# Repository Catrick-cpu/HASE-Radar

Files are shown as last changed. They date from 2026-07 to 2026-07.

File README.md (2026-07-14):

# AERIS-10P — Affordable Experimental Radar Intelligence System
## 10 GHz Phased Array Radar Platform

**Version:** 1.0 | **Status:** Design Phase Complete | **Date:** 2026-07-14  
**Budget Target:** < $8,000 USD | **Operating Frequency:** 10.0–10.1 GHz (X-band)

---

## What Is This?

AERIS-10P is a complete open-source engineering design for a 10 GHz FMCW phased-array radar, inspired by the AERIS-10 N project. It is designed to be:

- **Legal in Germany** under a Klasse A amateur radio license (10.000–10.500 GHz band)
- **Affordable** at under $8,000 USD for a complete system
- **Educationally valuable** for learning radar engineering, phased arrays, and RF systems
- **Real hardware** — not a simulation; designed to actually be built and operated

**Target performance:**
- Range: 2–5 km (car-sized targets, σ = 10 m²)
- Range resolution: 1.5 m
- Beam width: ~22° (4×4 array)
- Beam steering: ±45° azimuth and elevation
- TX power: 1 W (+30 dBm) — well within 75 W PEP legal limit

---

## Repository Structure

```
HASE-Radar/
├── Documentation/          # All engineering documents (specs, regs, procedures)
│   ├── 01_Project_Specification.md
│   ├── 02_Engineering_Requirements.md
│   ├── 03_System_Design_Document.md
│   ├── 04_Regulatory_Analysis_Germany.md
│   ├── 05_Safety_Documentation.md
│   ├── 06_Test_Procedures.md
│   ├── 07_Assembly_Documentation.md
│   └── 08_Maintenance_Documentation.md
│
├── Hardware/               # Hardware architecture and component selection
│   ├── System_Architecture.md
│   ├── Electronics_Documentation.md
│   ├── Component_Research.md
│   └── Interface_Documentation.md
│
├── RF_System/              # RF design: architecture, antenna, array, components
│   ├── RF_Architecture.md
│   ├── Antenna_Concept.md
│   ├── Array_Design.md
│   └── RF_Component_Analysis.md
│
├── PCB/                    # EasyEDA schematic files + manufacturing notes
│   ├── EasyEDA_Projects/
│   │   ├── AERIS_MainBoard/        schematic.json
│   │   ├── AERIS_RF_Frontend/      schematic.json
│   │   ├── AERIS_Power_Board/      schematic.json
│   │   └── AERIS_PhaseShifter_Board/ schematic.json
│   ├── Manufacturing_Notes.md
│   └── Assembly_Notes.md
│
├── Mechanical/             # 3D models + CAD scripts
│   ├── STL/
│   │   ├── main_enclosure.stl      (300×200×100mm electronics box)
│   │   ├── antenna_panel.stl       (200×120×5mm antenna mount)
│   │   ├── tripod_mount_adapter.stl
│   │   ├── electronics_tray.stl
│   │   ├── cooling_fan_bracket.stl
│   │   └── front_panel.stl
│   ├── CAD/generate_stl.py         (parametric STL generator)
│   ├── dimensions.md
│   └── Assembly_Instructions.md
│
├── Software/
│   ├── Embedded/firmware/          # STM32H743 C firmware
│   │   ├── main.c
│   │   ├── phase_shifter.c / .h
│   │   ├── adf4159.c / .h
│   │   └── Makefile
│   ├── Control/                    # PC-side Python control app
│   │   ├── aeris_control.py
│   │   ├── config.yaml
│   │   ├── requirements.txt
│   │   └── README.md
│   └── Signal_Processing/          # FMCW DSP pipeline
│       ├── fmcw_processing.py
│       ├── visualization.py
│       ├── data_logger.py
│       └── calibration.py
│
├── Spreadsheets/
│   ├── BOM.csv                     (70+ components with prices)
│   ├── Budget.csv                  (cost breakdown by category)
│   ├── Timeline.csv                (24-week project schedule)
│   └── generate_spreadsheets.py    (generates .xlsx from CSV data)
│
├── Testing/
│   ├── Calibration_Procedures.md
│   ├── Measurement_Plans.md
│   └── Validation_Methods.md
│
└── AI_Context/             # Handover documents for future sessions
    ├── PROJECT_MEMORY.md   ← START HERE if you're resuming this project
    ├── DESIGN_HISTORY.md
    ├── TODO.md
    └── FUTURE_AI_INSTRUCTIONS.md
```

---

## Quick Technical Summary

| Parameter | Value |
|---|---|
| Frequency | 10.0–10.1 GHz (FMCW, 100 MHz chirp BW) |
| Array | 4×4 TX + 4×4 RX = 32 patch antennas |
| Phase Shifter | HMC647ALP5E (6-bit, 0–360°) |
| VCO/PLL | HMC733 + ADF4159 FMCW generator |
| TX PA | HMC451LS6GE (+30 dBm / 1 W) |
| RX LNA | HMC1040LP4E (NF 1.5 dB) |
| Antenna Gain | ~22 dBi (TX + RX combined array) |
| MCU | STM32H743ZIT6 (480 MHz) |
| Processing | Raspberry Pi 5 (8 GB) |
| Power | 24 V DC, max 8 A |
| Weight | ~5 kg complete |
| Budget | ~$4,565 base / $8,000 max |

---

## German Amateur Radio Compliance

Operating frequency **10.000–10.100 GHz** falls within the **German 3 cm amateur band (10.000–10.500 GHz)**.

- **License required:** Klasse A (full amateur radio license)
- **Our TX power:** 1 W = +30 dBm (legal limit: 75 W PEP)
- **EIRP:** ~52 dBm (1 W × 22 dBi array gain)
- **Emission type:** FMCW (F3E/F7X equivalent — permitted)
- **Station ID:** required every 10 minutes (implemented in firmware)

⚠️ **Before field operation:** Contact BNetzA (Referat 221) for informal consultation on radar-type experimental operation. See `Documentation/04_Regulatory_Analysis_Germany.md` for full analysis.

---

## Getting Started

### 1. Understand the design
Read `Documentation/03_System_Design_Document.md` for the full system overview.

### 2. Review the BOM
Open `Spreadsheets/BOM.csv` in Excel/LibreOffice to see all components and prices.

### 3. Open PCB schematics
Import `PCB/EasyEDA_Projects/AERIS_MainBoard/schematic.json` into EasyEDA Standard (web app at easyeda.com) using **File → Import → EasyEDA JSON**.

### 4. Print mechanical parts
Open STL files from `Mechanical/STL/` in your slicer (PrusaSlicer, Cura). Print in PETG at 30% infill for prototype. Order machined aluminium for field-use version.

### 5. Set up software development environment
```bash
# On Raspberry Pi 5 (processing computer):
pip install -r Software/Control/requirements.txt

# Test signal processing without hardware:
python Software/Signal_Processing/fmcw_processing.py --demo

# Compile firmware (requires arm-none-eabi-gcc):
cd Software/Embedded/firmware
make all
```

---

## Key Design Choices

| Choice | Selected | Why |
|---|---|---|
| Waveform | FMCW | Low peak power, amateur-legal, simpler ADC |
| Frequency | 10 GHz | Full German amateur allocation, good component availability |
| Beamforming | Analog phase array | 10× cheaper than digital beamforming |
| Array size | 4×4 | Budget/complexity vs performance trade-off |
| Processing | Raspberry Pi 5 | Best price/performance for Python DSP |
| Antenna substrate | Rogers RO4003C | Industry standard, PCB-house available |

Full rationale in `Hardware/Component_Research.md` and `AI_Context/DESIGN_HISTORY.md`.

---

## License

Open-source for educational and amateur radio research use.  
**Not for commercial deployment. Always comply with local telecommunications regulations.**

---

*Generated 2026-07-14 as part of the HASE-Radar experimental radar development project.*

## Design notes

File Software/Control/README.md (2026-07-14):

# AERIS-10P Control Software
## Version 1.0 — 2026-07-14

Control and monitoring software for the AERIS-10P 10 GHz FMCW Phased Array Radar.

---

## Installation

```bash
# Python 3.10+ required
python --version

# Install dependencies
pip install -r requirements.txt

# Verify installation
python aeris_control.py --help
```

### System Requirements
- Python 3.10 or newer
- Operating System: Linux (Raspberry Pi OS, Ubuntu) or Windows 10/11
- USB CDC-ACM driver: built-in on Linux/Mac; Windows uses native USB CDC driver

---

## Quick Start

### 1. Connect Hardware
```
AERIS-10P USB Micro-B → USB-A on Raspberry Pi 5 or Laptop
24V Power Supply → XT60 connector on AERIS-10P front panel
```

### 2. Identify Serial Port
```bash
# Linux:
ls /dev/ttyACM*     # should show /dev/ttyACM0

# Windows:
# Check Device Manager → Ports (COM & LPT) → "USB Serial Device (COMx)"

# Using aeris_control.py:
python aeris_control.py list-ports
```

### 3. Edit Configuration
```bash
# Copy and edit config:
cp config.yaml my_config.yaml
nano my_config.yaml   # set serial_port and callsign
```

### 4. Basic Operation
```bash
# Check connection and system status
python aeris_control.py status --port /dev/ttyACM0

# Set beam to broadside (0°)
python aeris_control.py beam --az 0 --el 0

# Enable PA (start transmitting)
python aeris_control.py pa-enable 1

# Capture ADC data
python aeris_control.py capture --n 8000 --save session.npy

# Beam scan -45° to +45°
python aeris_control.py scan --az-min -45 --az-max 45 --step 5
```

---

## Commands Reference

| Command | Arguments | Description |
|---|---|---|
| `list-ports` | (none) | List available serial ports |
| `status` | `--port PORT` | Get system status (PA state, beam angles, temperature) |
| `beam` | `--az DEG --el DEG` | Set beam steering angles (az: ±45°, el: ±30°) |
| `pa-enable` | `0` or `1` | Enable (1) or disable (0) the power amplifier |
| `capture` | `--n N --save FILE` | Capture N ADC samples, optionally save to .npy |
| `scan` | `--az-min --az-max --step --el` | Beam scan across azimuth range |
| `reboot` | (none) | Reboot STM32 firmware |

---

## Signal Processing Pipeline

After capturing data, process with the signal processing scripts:

```bash
# Test processing without hardware (synthetic data):
cd ../Signal_Processing
python demo_no_hardware.py --scenario highway

# Process captured data:
python fmcw_processing.py  # runs built-in demo

# Compute link budget:
cd ../../RF_System
python link_budget_calculator.py --range-km 3 --rcs 10 --sweep
```

---

## Configuration Reference (config.yaml)

```yaml
radar:
  serial_port: /dev/ttyACM0  # Linux; use COM3 on Windows
  baud_rate: 115200

rf:
  freq_start_hz: 10000000000  # 10.000 GHz
  freq_stop_hz: 10100000000   # 10.100 GHz
  sweep_time_us: 1000          # 1 ms

beam:
  default_az_deg: 0.0
  default_el_deg: 0.0

regulatory:
  callsign: "DL0EXAMPLE"   # Replace with your Klasse A callsign!
  id_interval_s: 600        # Station ID every 10 minutes (required by law)
```

---

## Regulatory Note

This software implements automatic station identification as required by German amateur radio regulations (AFuG 2017, §16). The callsign is transmitted in the log every `id_interval_s` seconds. Set your actual Klasse A callsign in `config.yaml` before operating.

**Do not operate without a valid Klasse A amateur radio license.**

---

## Troubleshooting

| Problem | Solution |
|---|---|
| `No such file /dev/ttyACM0` | Check USB cable, try different USB port, verify firmware is running (LED blinks) |
| `No PONG response` | Firmware may be in bootloader mode. Press RESET on AERIS board. |
| `PA enable has no effect` | Check PA_EN GPIO wiring, verify +5V and +12V on RF board |
| `No data in capture` | Check ADC SPI wiring, verify ADS8661 is powered (+5V AVDD, +3.3V DVDD) |
| Chirp not locking | Check ADF4159 SPI communication, verify OCXO is powered and warm |

---

## Development

```bash
# Run with verbose logging:
python aeris_control.py --verbose status

# Extend the protocol (add new commands):
# 1. Add CMD_NEW_COMMAND = 0x60 in aeris_control.py
# 2. Add corresponding case in main.c Process_USB_Command()
# 3. Add method in AERISController class
# 4. Flash firmware: cd ../../Software/Embedded/firmware && make flash
```

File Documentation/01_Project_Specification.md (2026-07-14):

# AERIS-10P Phased Array Radar — Project Specification Rev 1.0

**Document Number:** AERIS-10P-SPEC-001  
**Revision:** 1.0  
**Date:** 2026-07-14  
**Author:** AERIS-10P Engineering Team  
**Status:** Released  
**Classification:** Open / Amateur Radio Research

---

## Table of Contents

1. Executive Summary
2. Project Objectives
3. Scope
4. System Overview
5. Performance Specifications
6. Physical Specifications
7. Operational Concept
8. Regulatory Framework
9. Constraints and Design Philosophy
10. Risk Summary
11. Glossary
12. References

---

## Executive Summary

The AERIS-10P (Affordable Experimental Radar Intelligence System, 10 GHz Phased Array) is a ground-based, portable, continuous-wave phased-array radar system designed for experimental and educational use within the German amateur radio service at 10 GHz. The system implements Frequency-Modulated Continuous Wave (FMCW) modulation with a 100 MHz chirp bandwidth over the 10.0–10.1 GHz X-band allocation and employs a 4×4 transmit plus 4×4 receive patch antenna array with analogue phase shifters for real-time electronic beam steering across a ±45° field of view.

The project targets a total build cost below USD 7,500 using commercially available RF monolithic microwave integrated circuits (MMICs), a Rogers RO4003C microstrip antenna substrate, an STM32H743 microcontroller for real-time chirp sequencing and phase-shifter control, and a Raspberry Pi 5 or NVIDIA Jetson Nano single-board computer for range-Doppler signal processing. All hardware is designed to be field-portable, tripod-mounted, and battery-operable from a 24 V DC supply.

Regulatory operation is governed by the German Amateurfunkgesetz (AFuG 2017), Amateurfunkverordnung (AFuV 2017), and the DARC 3 cm band plan. The system operates well within the permitted 75 W PEP power limit with a transmit power of +30 dBm (1 W) at the array feed point. The AERIS-10P serves as a research and demonstration platform for phased-array beamforming, FMCW signal processing, and radar fundamentals education, and is intended for licensed Klasse A amateur radio operators.

---

## 1. Project Objectives

### 1.1 Primary Objectives

**O-1 — Phased Array Beamforming Demonstration:** Demonstrate real-time electronic beam steering across ±45° in both azimuth and elevation using 16 HMC647ALP5E 6-bit analogue phase shifters on the transmit array and 16 independent phase-shifted receive channels combined into a single IF output. The system shall achieve a steered beam within the theoretical 22° 3 dB beamwidth of a 4-element, half-wavelength-spaced linear array.

**O-2 — FMCW Radar Signal Processing Research:** Provide a complete, instrumented FMCW radar chain that allows researchers to examine every stage from chirp generation through range-Doppler map formation. The system shall achieve 1.5 m range resolution and approximately 0.15 m/s velocity resolution with a coherent processing interval of 100 chirps at 1 kHz PRF.

**O-3 — Educational Platform:** Serve as a hands-on educational platform for advanced amateur radio operators, university students, and radar engineers studying phased-array principles, MMIC integration, microstrip antenna design, and digital signal processing for radar. All design files, firmware, and processing software shall be released under an open-source licence.

**O-4 — Amateur Radio Compatibility:** Operate legally and safely within the German amateur radio service on the 3 cm band (10.0–10.5 GHz) under a Klasse A licence, complying with all BNetzA technical requirements including the 75 W PEP power limit, mandatory station identification, and non-interference obligations.

**O-5 — Affordability and Reproducibility:** Achieve a complete system build cost below USD 7,500 (hard ceiling USD 8,000 with contingency) using components available from standard distributors (Mouser, Digi-Key, RFMW). The design shall use no custom ASICs, no controlled-technology export-restricted parts, and no discontinued components.

### 1.2 Secondary Objectives

**O-6 — Hardware Openness:** Publish full PCB schematics, Gerber files, BOM, and firmware source code under the CERN-OHL-S or equivalent licence, enabling independent replication.

**O-7 — Modular Architecture:** Design subsystems (antenna panel, RF front-end module, MCU board, processing computer) as separately testable and replaceable modules.

**O-8 — Data Logging:** Implement raw IF data capture for post-processing research, including time-stamped storage of I/Q samples at up to 1 MSPS for offline analysis in Python/NumPy/SciPy.

---

## 2. Scope

### 2.1 In Scope

The AERIS-10P project specification covers the following subsystems and activities:

- **RF Front-End:** VCO, PLL/chirp generator, power amplifier, low-noise amplifier, mixers, phase shifters, circulators, and all RF interconnects from 10 GHz signal generation to IF output.
- **Phased-Array Antenna:** 4×4 TX and 4×4 RX microstrip patch arrays on Rogers RO4003C substrate, corporate feed networks, element spacing, and mechanical integration into the antenna panel.
- **Digital Control System:** STM32H743ZIT6 microcontroller firmware for SPI-based phase-shifter programming, ADF4159 chirp ramp configuration, ADC data acquisition, and real-time control loop.
- **Signal Processing:** Raspberry Pi 5 or Jetson Nano-based processing pipeline implementing range FFT, Doppler FFT, CFAR detection, and range-Doppler map visualisation.
- **Power System:** 24 V DC input, LT8612/LT8607/TPS65133 DC-DC converter tree supplying all subsystem rails.
- **Mechanical Enclosure:** 300 mm × 200 mm × 100 mm aluminium electronics box with antenna panel mounting frame and 3/8-16 UNC tripod interface.
- **Regulatory Compliance:** Demonstration of compliance with AFuG 2017, AFuV 2017, and DARC 3 cm band plan requirements.
- **Software and Firmware:** Real-time control firmware, Python-based processing software, graphical user interface.

### 2.2 Out of Scope

- Moving-target indicator (MTI) clutter cancellation (future work).
- Synthetic aperture radar (SAR) modes.
- Full EMC pre-compliance testing to ETSI EN 301 783 or similar (recommended before any public demonstration).
- Integration with external tracking systems or command-and-control networks.
- Series production; this is a one-off experimental prototype.

---

## 3. System Overview

### 3.1 Top-Level Architecture

The AERIS-10P implements a classical pulsed-equivalent FMCW homodyne radar architecture with separated TX and RX apertures, analogue phase-shifted beamforming, and a homodyne (self-mixing) receiver. The chirp generator uses the ADF4159 fractional-N PLL to ramp the HMC733LP6CE VCO linearly from 10.0 GHz to 10.1 GHz in 1 ms, generating a 100 MHz bandwidth sawtooth FMCW chirp at a 1 kHz pulse repetition frequency. Transmit power is amplified by the HMC451LS6GE PA to +30 dBm, then distributed through a 1:16 Wilkinson divider corporate feed network to each of 16 TX patch elements, each preceded by an HMC647ALP5E 6-bit phase shifter. On receive, 16 patch elements feed 16 phase-shifted paths through HMC647A phase shifters and HMC1040LP4E LNAs before combination in a 16:1 corporate combiner. The combined RX signal and a sample of the TX signal are mixed in an HMC213B double-balanced mixer, producing an intermediate frequency (IF) beat signal whose frequency is proportional to target range. The IF signal is digitised by a 16-bit ADS8661IRGAT ADC at 1 MSPS and streamed via SPI to the STM32H743, which forwards data over USB or Ethernet to the Raspberry Pi 5 for FFT-based range and Doppler processing.

### 3.2 ASCII Block Diagram

```
 10 MHz OCXO
(ABRACON AOCJY)
      |
      v
 ADF4159CCPZ         SPI config from STM32H743
 PLL/Chirp Gen  <------------------------------------+
      |                                              |
      | 10.0–10.1 GHz ramp (1 ms, 100 MHz BW)       |
      v                                              |
 HMC733LP6CE                                         |
 VCO (+17 dBm)                                       |
      |                                              |
      +------------------+                           |
      |                  |                           |
      v                  v (reference sample)        |
 HMC451LS6GE       HMC213B                           |
 TX PA (+30 dBm)   MIXER                             |
      |                  ^                           |
      v                  |                           |
 1:16 Wilkinson    16:1 Wilkinson                    |
 Power Divider     Power Combiner                    |
      |                  ^                           |
      |                  |                           |
 [x16 TX paths]    [x16 RX paths]                   |
 HMC647ALP5E       HMC647ALP5E                       |
 Phase Shifters    Phase Shifters  <-----------------+
      |                  ^         (SPI from STM32)  |
      v                  |                           |
 4x4 TX Patch      4x4 RX Patch                     |
 Array (RO4003C)   Array (RO4003C)                   |
                         |                           |
                    HMC1040LP4E                      |
                    LNA (x16 or post-combine)        |
                         |                           |
                    HMC213B IF output                |
                         |                           |
                         v                           |
                   ADS8661IRGAT                      |
                   16-bit ADC (1 MSPS)               |
                         |                           |
                         v SPI                       |
                   STM32H743ZIT6 -------------------+
                   MCU (480 MHz)
                         |
                         | USB 2.0 HS or Ethernet
                         v
                   Raspberry Pi 5 8GB
                   (or NVIDIA Jetson Nano)
                   FFT | CFAR | Range-Doppler Map
                         |
                         v
                   Display / Data Logger
                   (Laptop via Ethernet/WiFi)
```

### 3.3 Data Flow Summary

Each 1 ms chirp produces 1,000 ADC samples (at 1 MSPS) representing the IF beat signal. A coherent processing interval (CPI) of 100 chirps (100 ms) provides 100 × 1,000 = 100,000 samples, from which a 2D range-Doppler FFT is computed. The Raspberry Pi 5 processes one CPI in real time (10 Hz update rate), displaying a range-Doppler power map on the operator laptop via Ethernet.

---

## 4. Performance Specifications

| Parameter | Specification | Notes |
|---|---|---|
| Operating Frequency | 10.0–10.1 GHz | X-band, German 3 cm amateur band |
| Chirp Bandwidth | 100 MHz | FMCW sawtooth |
| Chirp Duration | 1 ms | Ramp-up; 10% guard time |
| Pulse Repetition Frequency | 1000 Hz (1 kHz PRF) | One chirp per ms |
| Coherent Processing Interval | 100 chirps (100 ms) | 10 Hz update rate |
| Range Resolution | 1.5 m | c/(2B) = 3×10⁸/(2×10⁸) |
| Maximum Unambiguous Range | 75 m (IF BW limited to 50 kHz) / 150 m at 100 kHz | Beat freq = 2BR/cT |
| Velocity Resolution | ~0.15 m/s | λ/(2×T_CPI) at 100 chirps |
| Maximum Unambiguous Velocity | ±7.5 m/s | PRF limited: λ·PRF/4 |
| TX Output Power | +30 dBm (1 W) | At PA output; EIRP 52 dBm |
| TX Array Gain | 22 dBi (practical) | 4×4 patch, λ/2 spacing |
| RX Array Gain | 22 dBi (practical) | 4×4 patch, λ/2 spacing |
| EIRP | 52 dBm | 30 dBm + 22 dBi TX gain |
| Regulatory Power Limit | 75 W PEP (48.75 dBm) | AFuV 2017, 3 cm band |
| Noise Figure (system) | ~8 dB | LNA NF 1.5 dB, combiner and mixer losses |
| Beamwidth (one axis) | ~22° (3 dB) | 0.886/4 elements at λ/2 |
| Maximum Steering Angle | ±45° | Phase shifter limited |
| Phase Shifter Resolution | 5.625° (6-bit, 64 states) | HMC647ALP5E LSB |
| Theoretical Detection Range (car, σ=10 m²) | 8 km | SNR=15 dB, NF=8 dB, IF BW=2 kHz |
| Practical Detection Range | 2–5 km | With real-world losses and clutter |
| ADC Resolution | 16 bits | ADS8661IRGAT |
| ADC Sample Rate | 1 MSPS | SPI output to STM32H743 |
| Frequency Reference Accuracy | ±0.01 ppm | ABRACON AOCJY-10 OCXO |

---

## 5. Physical Specifications

| Parameter | Specification |
|---|---|
| Electronics Enclosure | 300 mm × 200 mm × 100 mm, 3 mm wall aluminium |
| Antenna Panel Dimensions | 200 mm × 120 mm × 1.6 mm |
| Antenna Substrate | Rogers RO4003C, εr = 3.55, tan δ = 0.0027, 0.508 mm thick |
| TX Array Aperture | 45 mm × 45 mm |
| RX Array Aperture | 45 mm × 45 mm |
| Patch Element Dimensions | 13.8 mm × 13.8 mm |
| Element Spacing | 15 mm (λ/2 at 10 GHz) |
| Tripod Mount | 3/8-16 UNC standard photo-tripod thread |
| Total System Weight | ~5 kg (electronics box + antenna panel + cabling) |
| Power Input Connector | Anderson PowerPole PP45 or XLR 4-pin, 24 V DC, max 8 A |
| RF Interconnects | SMA female (all RF test ports), SMA-to-2.92 mm adapters for VNA access |
| Data/Control Connectors | USB Type-C (MCU programming/data), RJ-45 Ethernet (RPi5 to laptop) |
| Operating Temperature Range | −10°C to +50°C |
| Storage Temperature Range | −40°C to +70°C |
| Power Consumption (maximum) | 192 W (24 V × 8 A) |
| Typical Power Consumption | ~120 W (nominal operational) |
| Power Supply Voltages | 24 V (main), 5 V/5 A, 3.3 V/3 A, ±5 V/1 A (RF bias) |

---

## 6. Operational Concept

### 6.1 Deployment Scenario

The AERIS-10P is designed for semi-permanent field deployment by a licensed Klasse A amateur radio operator. Typical deployment scenarios include:

- **Open field or rooftop:** Elevated location to maximise radar line-of-sight. The antenna panel is mounted on a standard 3/8-16 UNC photo-tripod or survey tripod at operator-adjustable height (1.5–3 m AGL). The electronics box is placed on a field table or directly on the tripod platform.
- **Vehicle-side deployment:** The system can be operated from a 24 V vehicle auxiliary battery (e.g., 100 Ah LiFePO4) providing approximately 45 minutes of continuous operation at maximum power.
- **Indoor laboratory use:** For development and calibration, the system operates from a 24 V bench power supply (Meanwell RSP-200-24 or equivalent) with the antenna connected via SMA coaxial cables to absorber-terminated test loads or an anechoic chamber setup.

### 6.2 Setup Procedure (Summary)

1. Erect tripod; torque antenna panel mounting bracket to 3/8-16 UNC thread.
2. Run coaxial umbilical (RF) and power/data cable bundle from electronics box to antenna panel.
3. Connect 24 V power supply or battery to PowerPole connector; verify LED power-good indicators on all DC-DC converter rails.
4. Connect operator laptop to RJ-45 Ethernet port on electronics box (RPi5 provides DHCP server).
5. Power on system via main power switch; STM32H743 initialises within 500 ms, configuring ADF4159 chirp ramp and loading default phase-shifter coefficients.
6. Open radar processing GUI on laptop (Python/PyQt6 application); verify live range-Doppler map display.
7. Adjust antenna azimuth and elevation manually; use GUI beam-steering controls for electronic fine-pointing.
8. Transmit station identification (callsign) via voice or CW at least every 10 minutes as required by AFuV 2017.

### 6.3 Operator Requirements

The operator must hold a valid German amateur radio licence Klasse A (covering the 10 GHz band) issued by the Bundesnetzagentur. Experimental radar permits beyond normal amateur radio authority should be obtained from BNetzA prior to any operation that may illuminate third-party aircraft, vessels, or persons, or that is conducted at locations other than the licensed station address.

### 6.4 Maintenance

Field-replaceable units include: the antenna panel (SMA coaxial connectors), the RF front-end module (SMA bracket), and the processing computer (RPi5 on standoff header). Firmware updates are loaded over USB DFU from the operator laptop. Calibration of phase-shifter offsets is performed using the built-in calibration routine with a reference reflector at known range.

---

## 7. Regulatory Framework

### 7.1 Applicable German Regulations

The AERIS-10P is designed to comply with the following legal instruments:

| Document | Title | Relevance |
|---|---|---|
| AFuG 2017 | Amateurfunkgesetz — German Amateur Radio Act | Overall legal basis for amateur radio operation |
| AFuV 2017 | Amateurfunkverordnung — Amateur Radio Ordinance | Technical parameters, power limits, identification |
| DARC 3 cm Band Plan | DARC e.V. 3 cm (10 GHz) band plan | Frequency allocation, permitted modes |
| TKG 2021 | Telekommunikationsgesetz | Spectrum management framework |
| BNetzA Vfg 17/2010 | EMF exposure decree | RF human exposure limits |

### 7.2 Frequency Allocation

The German amateur radio service has secondary allocation of the 10.000–10.500 GHz band (3 cm band). The AERIS-10P operates on 10.000–10.100 GHz, within the DARC-recommended segment for narrowband/wideband experimental modes. This segment is also allocated to radiolocation (primary) and Earth-exploration satellite services, placing additional obligation on the amateur operator not to cause harmful interference.

### 7.3 Power Limits

AFuV 2017, Anlage 1, allocates 75 W PEP (peak envelope power) to Klasse A licensees on the 3 cm band. The AERIS-10P transmits a maximum of +30 dBm (1 W) at the PA output. With 22 dBi TX array gain, the EIRP is 52 dBm (158 W EIRP). Although EIRP exceeds 75 W, the German regulatory framework (consistent with ITU Radio Regulations) applies the power limit to the transmitter output power, not to EIRP, for high-gain antenna applications in the amateur service. The operator should confirm this interpretation with BNetzA before deployment with high-gain antenna.

### 7.4 Station Identification

Under AFuV 2017 §14, the amateur station must identify itself with its callsign at the beginning and end of each transmission and at intervals not exceeding 10 minutes during continuous operation. For a radar system, this identification is typically implemented as a brief CW or voice ID burst transmitted on the assigned radar frequency or an adjacent voice frequency. The AERIS-10P firmware implements an automated 10-minute identification interrupt that briefly keys a CW identification sequence into the radar transmit chain.

### 7.5 Experimental Radar Permit

Any operation of an active radar — even within amateur radio frequency allocations — may require an additional experimental radar permit from BNetzA under §55 TKG, particularly if the system illuminates airspace or is operated at locations other than the licensed station address. The operator is strongly advised to apply for a BNetzA Experimentallizenz before commencing field operations. Contact: Bundesnetzagentur, Referat 225, Tulpenfeld 4, 53113 Bonn.

### 7.6 RF Exposure (EMF)

The AERIS-10P at +30 dBm TX power and 22 dBi gain produces a far-field power density at 1 m boresight of approximately 158 W/m² EIRP equivalent (note: far-field only applies beyond 2D²/λ ≈ 1.35 m for this aperture). BNetzA Vfg 17/2010 specifies an occupational exposure limit of 50 W/m² and general public limit of 10 W/m² at 10 GHz (averaged over 6 minutes). Operators must maintain a minimum safe distance of approximately 4 m from the boresight of the transmitting antenna during operation. Safety interlocks and warning labels are required on the enclosure.

---

## 8. Constraints and Design Philosophy

### 8.1 Budget Constraint

The total procurement budget is USD 7,500, with a contingency ceiling of USD 8,000. This drives selection of commercial off-the-shelf (COTS) MMICs and development boards rather than custom ASICs or military-grade components. PCB fabrication is budgeted at two four-layer boards from JLC PCB or equivalent ($200–$400 total).

### 8.2 Open-Source Requirement

All hardware design files (KiCad schematics, PCB layouts, mechanical drawings), firmware source (STM32 HAL-based C project), and processing software (Python 3 with NumPy/SciPy/Matplotlib) shall be published on a public version-controlled repository (GitHub or GitLab) under open licences (CERN-OHL-S for hardware, GPL-3.0 or MIT for software).

### 8.3 Repairability

The design shall avoid BGA packages with pitch below 0.5 mm wherever possible to allow rework with standard hot-air tools. All MMIC devices are in exposed-pad QFN or flat-pack packages accessible to a skilled amateur with a hot-air rework station.

### 8.4 Component Availability

All selected components must be available from mainstream distributors with stock levels exceeding 50 units at time of BOM freeze. Alternative second-source components shall be identified for all critical RF MMICs.

### 8.5 No Controlled Technology

The design exclusively uses components available without US Export Administration Regulations (EAR) licence requirements for the intended application. All RF MMICs from Analog Devices/Hittite are commercial parts available to non-US persons.

---

## 9. Risk Summary

| Risk ID | Risk Description | Probability | Severity | Mitigation |
|---|---|---|---|---|
| R-01 | VCO chirp non-linearity degrades range resolution | Medium | High | ADF4159 digital ramp compensation; post-processing dechirp correction algorithm |
| R-02 | Mutual coupling between TX/RX arrays causes self-interference | Medium | High | Physical separation of TX and RX panels by 50 mm; PE8316 circulator on TX port |
| R-03 | Phase shifter quantisation sidelobes limit angular resolution | Low | Medium | 6-bit (64 level) resolution gives <−26 dB quantisation sidelobes; acceptable for experimental use |
| R-04 | MMIC supply chain disruption (HMC647A, HMC733) | Low | High | Order 20% excess quantities at project start; identify substitute parts (MACOM MAPS-010164 for phase shifter) |
| R-05 | Regulatory non-compliance (BNetzA radar permit) | Medium | High | Consult BNetzA Referat 225 before field operations; initial testing in shielded lab environment |
| R-06 | RF PCB manufacturing defects on RO4003C | Low | Medium | Order 3 sets of antenna panels; specify impedance control (50 Ω ±10%) in Gerber notes |
| R-07 | Power consumption exceeds 24 V/8 A budget | Low | Medium | Thermal/power simulation in LTspice before build; measure each rail with bench supply |
| R-08 | RPi5 processing throughput insufficient for real-time 1 MSPS FFT | Low | Low | Benchmarked at 10 Hz update rate; fallback to Jetson Nano with CUDA FFT if needed |
| R-09 | Antenna gain lower than predicted (element matching loss) | Medium | Medium | EM simulation in ANSYS HFSS or openEMS; trimming patches ±0.3 mm for resonance tuning |
| R-10 | Thermal runaway in PA at high duty cycle | Low | High | PA mounted to aluminium enclosure wall (heatsink); thermal pad and thermal via array; measure PA temperature in field |

---

## 10. Glossary

| Term | Definition |
|---|---|
| ADC | Analogue-to-Digital Converter. Converts continuous analogue signal to discrete digital values. |
| AFuG | Amateurfunkgesetz. German federal law governing the amateur radio service. |
| AFuV | Amateurfunkverordnung. German regulatory ordinance implementing AFuG. |
| BNetzA | Bundesnetzagentur. Federal Network Agency of Germany; national radio spectrum regulator. |
| Chirp | A signal whose frequency changes linearly over time. In FMCW radar, a sawtooth frequency ramp from f_start to f_stop. |
| CPI | Coherent Processing Interval. The block of consecutive coherent pulses (chirps) processed together for Doppler analysis. |
| CFAR | Constant False Alarm Rate. Adaptive threshold algorithm for radar target detection in clutter. |
| DARC | Deutscher Amateur-Radio-Club e.V. German national amateur radio organisation; publishes the German band plan. |
| dBi | Decibels relative to an isotropic radiator. Unit of antenna gain. |
| dBm | Decibels relative to 1 milliwatt. Unit of power level. |
| DDS | Direct Digital Synthesis. Method of generating waveforms from a digital clock and lookup table (not used in AERIS-10P; ADF4159 uses fractional-N PLL instead). |
| EIRP | Equivalent Isotropically Radiated Power. Transmitter output power multiplied by the antenna gain relative to an isotropic radiator. |
| FMCW | Frequency-Modulated Continuous Wave. Radar modulation where the carrier is continuously transmitted with a linearly swept frequency. |
| FFT | Fast Fourier Transform. Efficient algorithm for computing the Discrete Fourier Transform; used for range and Doppler processing. |
| IF | Intermediate Frequency. In FMCW radar, the difference frequency between the TX chirp and the reflected RX signal. Proportional to target range. |
| LNA | Low-Noise Amplifier. First active stage in the receive chain; minimises added noise figure. |
| MMIC | Monolithic Microwave Integrated Circuit. An integrated circuit designed for microwave frequency operation, typically GaAs or GaN process. |
| NF | Noise Figure. Measure of noise added by a receiver component, in decibels. |
| OCXO | Oven-Controlled Crystal Oscillator. A frequency reference with thermally stabilised crystal for low ageing and low phase noise. |
| PA | Power Amplifier. Final stage in the transmit chain; boosts signal to the required transmit power level. |
| PEP | Peak Envelope Power. The average power supplied to the antenna during one RF cycle at the crest of the modulation envelope. Regulatory power limit basis in German amateur radio. |
| PLL | Phase-Locked Loop. Feedback control circuit that locks an oscillator's phase and frequency to a reference signal. |
| PRF | Pulse Repetition Frequency. Number of chirps transmitted per second. Determines unambiguous velocity range. |
| Range-Doppler Map | A 2D image with range on one axis and radial velocity (Doppler) on the other, showing detected target returns. |
| RPi5 | Raspberry Pi 5. Single-board computer used as the AERIS-10P processing platform. |
| SMA | SubMiniature version A. 50 Ω coaxial connector standard used for RF connections up to 18 GHz. |
| SPI | Serial Peripheral Interface. Synchronous serial communication protocol used to program phase shifters, PLL, and ADC. |
| SNR | Signal-to-Noise Ratio. Ratio of signal power to noise power, usually in decibels. |
| VCO | Voltage-Controlled Oscillator. An oscillator whose frequency is controlled by an input voltage. In AERIS-10P, the HMC733LP6CE covering 9.5–11 GHz. |
| Wilkinson Divider | A passive microwave power divider/combiner providing equal power split with port isolation. Used in the corporate feed network of the TX and RX arrays. |

---

## 11. References

| Ref | Document |
|---|---|
| [1] | Analog Devices, "ADF4159 Datasheet: Direct Modulation/Fast Waveform Generating, 13 GHz, Fractional-N Frequency Synthesizer," Rev. D, 2020. |
| [2] | Analog Devices (Hittite), "HMC647ALP5E Datasheet: 6-Bit Digital Phase Shifter, 10–14 GHz," 2018. |
| [3] | Analog Devices (Hittite), "HMC733LP6CE Datasheet: VCO with Buffer Amplifier, 9.5–11 GHz," 2017. |
| [4] | Analog Devices (Hittite), "HMC451LS6GE Datasheet: GaAs pHEMT MMIC Power Amplifier, Ku-Band," 2016. |
| [5] | Analog Devices (Hittite), "HMC1040LP4E Datasheet: Low Noise Amplifier, 8–12 GHz," 2019. |
| [6] | Analog Devices (Hittite), "HMC213B Datasheet: Double Balanced Mixer, 8–26 GHz," 2017. |
| [7] | Texas Instruments, "ADS8661IRGAT Datasheet: 16-Bit, High-Speed, Single-Supply, SAR ADC," 2020. |
| [8] | STMicroelectronics, "STM32H743ZIT6 Reference Manual RM0433," Rev. 8, 2023. |
| [9] | Rogers Corporation, "RO4003C Laminates Datasheet," Publication 92-004, 2022. |
| [10] | ABRACON, "AOCJY Series OCXO Datasheet," 2021. |
| [11] | Bundesgesetzblatt, "Amateurfunkgesetz (AFuG) vom 23. Juni 1997, geändert 2017." |
| [12] | Bundesgesetzblatt, "Amateurfunkverordnung (AFuV) vom 15. Februar 2005, geändert 2017." |
| [13] | DARC e.V., "Bandplan 3-cm-Band (10 GHz)," Rev. 2023. |
| [14] | M. I. Skolnik, "Introduction to Radar Systems," 3rd ed., McGraw-Hill, 2001. |
| [15] | G. A. Richards, J. A. Scheer, W. A. Holm, "Principles of Modern Radar," Vol. I, SciTech Publishing, 2010. |
| [16] | Pozar, D. M., "Microwave Engineering," 4th ed., Wiley, 2011. |
| [17] | Balanis, C. A., "Antenna Theory: Analysis and Design," 4th ed., Wiley, 2016. |
| [18] | Bundesnetzagentur, "Vfg 17/2010: Allgemeinzuteilung für Funkanlagen auf der Grundlage der EMF-Richtlinie." |
| [19] | Analog Devices, "LT8612 Datasheet: 6A, 42V, 3MHz Step-Down Regulator," 2019. |
| [20] | Texas Instruments, "TPS65133 Datasheet: Dual-Output, Regulated Charge Pump," 2018. |

---

*End of Document — AERIS-10P-SPEC-001 Rev 1.0*

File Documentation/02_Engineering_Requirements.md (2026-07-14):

# AERIS-10P Engineering Requirements Specification Rev 1.0

**Document Number:** AERIS-10P-REQ-001  
**Revision:** 1.0  
**Date:** 2026-07-14  
**Author:** AERIS-10P Engineering Team  
**Status:** Released  
**Parent Document:** AERIS-10P-SPEC-001 (Project Specification Rev 1.0)

---

## Table of Contents

1. Introduction and Purpose
2. System Requirements (REQ-SYS)
3. RF Requirements (REQ-RF)
4. Antenna Requirements (REQ-ANT)
5. Digital and Control Requirements (REQ-DIG)
6. Power Requirements (REQ-PWR)
7. Mechanical Requirements (REQ-MEC)
8. Software Requirements (REQ-SW)
9. Regulatory Requirements (REQ-REG)
10. Safety Requirements (REQ-SAF)
11. Requirements Traceability Matrix
12. Revision History

---

## 1. Introduction and Purpose

### 1.1 Purpose

This Engineering Requirements Specification (ERS) defines all measurable, testable requirements for the AERIS-10P phased-array radar system. Each requirement is assigned a unique identifier, a verification method, and a reference to the design element responsible for satisfying it. This document serves as the binding technical reference for all design, fabrication, integration, and acceptance testing activities.

### 1.2 Requirement Conventions

Requirements are expressed using the word **shall** for mandatory requirements and **should** for recommended but non-mandatory targets. Each requirement is accompanied by:

- **Rationale:** Explains why the requirement exists.
- **Verification Method:** Analysis (A), Inspection (I), Demonstration (D), or Test (T).
- **Design Element:** The subsystem or component responsible for compliance.

### 1.3 Requirement Status Levels

| Status | Meaning |
|---|---|
| Open | Requirement not yet addressed in design |
| In Progress | Design activity underway |
| Closed | Requirement satisfied and verified |
| Deferred | Moved to future revision |

All requirements in this Rev 1.0 document have status **Open** pending completion of detailed design.

---

## 2. System Requirements (REQ-SYS)

### REQ-SYS-001 — Operating Frequency Band

**Requirement:** The AERIS-10P system shall operate in the frequency range 10.000–10.100 GHz.

**Rationale:** The German amateur radio service has secondary allocation of the 10.000–10.500 GHz band under AFuV 2017 Anlage 1. The DARC band plan designates 10.000–10.150 GHz for wideband experimental modes. Restricting operation to 10.000–10.100 GHz provides 100 MHz of usable chirp bandwidth while remaining within the DARC allocation.

**Verification Method:** T — Spectrum analyser measurement of VCO output swept frequency across one complete chirp ramp.

**Design Element:** ADF4159CCPZ PLL + HMC733LP6CE VCO.

---

### REQ-SYS-002 — Radar Modulation

**Requirement:** The system shall implement Frequency-Modulated Continuous Wave (FMCW) modulation with a sawtooth frequency ramp. The chirp bandwidth shall be 100 MHz ±1 MHz. The chirp repetition period shall be 1 ms ±10 μs (1 kHz PRF ±10 Hz).

**Rationale:** FMCW provides simultaneous range and velocity measurement with low peak transmit power, making it suitable for amateur radio use. A 100 MHz bandwidth gives 1.5 m range resolution. A 1 kHz PRF gives a 10 Hz update rate when processing 100-chirp CPIs.

**Verification Method:** T — Measurement of instantaneous frequency vs. time using a spectrum analyser in zero-span or a phase-coherent ADC measurement of a down-converted chirp reference.

**Design Element:** ADF4159CCPZ chirp ramp configuration registers; STM32H743 SPI initialisation firmware.

---

### REQ-SYS-003 — Range Resolution

**Requirement:** The system shall achieve a range resolution of ≤1.5 m after matched-filter (FFT) processing, measured as the 3 dB width of the point-spread function of a single tone target at close range.

**Rationale:** Range resolution is determined by the chirp bandwidth: δR = c/(2B) = 3×10⁸/(2×10⁸) = 1.5 m. This is derived from REQ-SYS-002.

**Verification Method:** T — Corner reflector at known range; measure FFT bin width of peak return.

**Design Element:** FMCW chirp bandwidth (100 MHz); range FFT processing on RPi5.

---

### REQ-SYS-004 — Velocity Resolution

**Requirement:** The system shall achieve a velocity resolution of ≤0.15 m/s with a coherent processing interval of 100 chirps at 1 kHz PRF.

**Rationale:** Velocity resolution = λ/(2·T_CPI) = 0.03/(2×0.1) = 0.15 m/s. This allows detection of slow-moving targets (pedestrians at ~1 m/s, vehicles at highway speeds).

**Verification Method:** A — Calculated from CPI length and wavelength; D — demonstration using a rotating reflector at known angular rate to produce known Doppler frequency.

**Design Element:** CPI length (100 chirps); Doppler FFT processing on RPi5.

---

### REQ-SYS-005 — Maximum Unambiguous Range

**Requirement:** The system shall provide an unambiguous range interval of at least 75 m for targets producing IF beat frequencies within the ADC Nyquist bandwidth.

**Rationale:** The beat frequency for a target at range R is f_beat = 2BR/(cT). At R = 75 m, f_beat = 2×10⁸×75/(3×10⁸×10⁻³) = 50 kHz, well within the 500 kHz Nyquist frequency of the 1 MSPS ADC. Longer ranges up to 150 m (f_beat = 100 kHz) are resolvable with the full ADC bandwidth.

**Verification Method:** A — Calculation from FMCW equations; T — retroreflector test at known ranges.

**Design Element:** ADS8661 ADC sample rate; IF filter bandwidth in analog chain.

---

### REQ-SYS-006 — Receiver Noise Figure

**Requirement:** The system receiver noise figure shall be ≤8 dB referred to the RX antenna port under nominal operating conditions.

**Rationale:** System NF of 8 dB gives sufficient sensitivity for a 2–5 km practical detection range against a 10 m² RCS target. The LNA NF of 1.5 dB dominates if sufficient gain precedes the mixer; however, combining losses and RF interconnect losses raise the cascaded NF to approximately 4–8 dB.

**Verification Method:** T — Y-factor noise figure measurement at the combined RX port using a calibrated noise source.

**Design Element:** HMC1040LP4E LNA; 16:1 combiner insertion loss; HMC213B mixer conversion loss.

---

### REQ-SYS-007 — Transmit Power

**Requirement:** The transmitter output power at the PA output shall be +30 dBm ±1 dB under all operating conditions over the temperature range −10°C to +50°C.

**Rationale:** +30 dBm (1 W) is within the capability of the HMC451LS6GE PA (P1dB = +29 dBm) with drive level set to avoid compression. This power level is well below the 75 W PEP legal limit.

**Verification Method:** T — Power meter measurement at PA output port over temperature.

**Design Element:** HMC451LS6GE PA; VCO drive level; input attenuator if required.

---

### REQ-SYS-008 — Beam Steering Range

**Requirement:** The system shall electronically steer the transmit and receive beams over a range of ±45° in azimuth and ±45° in elevation from boresight, using the phased-array antenna and digital phase shifters.

**Rationale:** ±45° provides useful field of view for surveillance and tracking applications. Beyond ±45° the array scan loss (cos³ θ for a planar array with ohmic loss) becomes prohibitive and the phase shifter settles into grating lobe territory.

**Verification Method:** D — Antenna pattern measurement by rotating the antenna panel on a positioner while measuring received signal strength from a fixed CW source at boresight distance.

**Design Element:** HMC647ALP5E phase shifters; beamforming algorithm in STM32H743 firmware.

---

### REQ-SYS-009 — Operating Temperature

**Requirement:** The system shall operate within all specified performance parameters over an ambient temperature range of −10°C to +50°C. Key parameters to maintain are transmit power (REQ-SYS-007) and frequency accuracy (REQ-SYS-001).

**Rationale:** Field operation in Germany spans −10°C (winter) to +40°C ambient (summer direct sun on equipment). The electronics box provides partial thermal buffering.

**Verification Method:** T — Environmental chamber test cycling from −10°C to +50°C while monitoring TX power and VCO centre frequency.

**Design Element:** OCXO thermal stabilisation; PA thermal management; PCB conformal coating for condensation protection.

---

### REQ-SYS-010 — System Update Rate

**Requirement:** The system shall produce and display a range-Doppler map with a minimum update rate of 10 Hz under nominal operation (100-chirp CPI, 1 kHz PRF).

**Rationale:** A 10 Hz update rate (100 ms per frame) is perceptually real-time and sufficient for tracking targets moving at typical vehicle speeds.

**Verification Method:** T — Timestamp processing loop on RPi5; verify ≥10 complete range-Doppler maps per second.

**Design Element:** RPi5 signal processing pipeline; USB/Ethernet data transfer bandwidth.

---

## 3. RF Requirements (REQ-RF)

### REQ-RF-001 — Reference Frequency Accuracy

**Requirement:** The 10 MHz reference oscillator shall maintain a frequency accuracy of ≤±0.01 ppm over the temperature range −10°C to +50°C.

**Rationale:** The PLL multiplies the reference by ~1000 to reach 10 GHz. A ±0.01 ppm reference error corresponds to ±10 kHz at 10 GHz, which is negligible compared to the 100 MHz chirp bandwidth.

**Verification Method:** T — Frequency counter measurement of OCXO output at temperature extremes.

**Design Element:** ABRACON AOCJY-10 OCXO.

---

### REQ-RF-002 — VCO Phase Noise

**Requirement:** The VCO phase noise within the PLL loop bandwidth shall not exceed −80 dBc/Hz at 100 kHz offset from the carrier. Free-running phase noise outside the loop bandwidth shall not exceed −110 dBc/Hz at 1 MHz offset.

**Rationale:** Phase noise sets the radar noise floor for nearby clutter and determines the minimum detectable velocity for slow targets. The HMC733LP6CE specifies −110 dBc/Hz at 1 MHz offset free-running; in-loop noise depends on ADF4159 charge pump and loop filter design.

**Verification Method:** T — Phase noise analyser (R&S FSWP or equivalent) measurement at VCO output.

**Design Element:** HMC733LP6CE VCO; ADF4159 PLL loop filter.

---

### REQ-RF-003 — Chirp Linearity

**Requirement:** The instantaneous frequency deviation from an ideal linear ramp shall not exceed ±500 kHz (0.5% of 100 MHz bandwidth) over the central 90% of the chirp ramp duration.

**Rationale:** Chirp non-linearity causes range sidelobe elevation and range resolution degradation. The ADF4159 uses a digital ramp engine that provides inherently linear frequency steps; the VCO Kv non-linearity must be compensated by the PLL loop.

**Verification Method:** T — Time-frequency analysis of chirp using a fast spectrum analyser or phase-coherent downconversion and spectrogram.

**Design Element:** ADF4159 ramp step size and delay; VCO Kv characterisation; loop filter bandwidth tuning.

---

### REQ-RF-004 — TX Output Power Flatness

**Requirement:** The transmit power at the PA output shall be flat to within ±1 dB across the 10.000–10.100 GHz chirp bandwidth.

**Rationale:** Power variation across the chirp creates amplitude-modulated range sidelobes. The HMC451 gain variation must be characterised and compensated.

**Verification Method:** T — Swept CW power measurement across 10.0–10.1 GHz at PA output.

**Design Element:** HMC451LS6GE PA gain flatness; input power level control.

---

### REQ-RF-005 — TX/RX Isolation

**Requirement:** The isolation between the transmit output and the receive input at the antenna panel shall be ≥50 dB to prevent TX leakage from saturating the RX LNA.

**Rationale:** TX power is +30 dBm. The LNA input compression point is approximately −15 dBm (18 dB gain, output P1dB ~+3 dBm). Isolation ≥45 dB brings TX leakage at LNA input to −15 dBm; ≥50 dB provides 5 dB margin. This isolation is achieved by the spatial separation of TX and RX arrays plus the PE8316 circulator/isolator in the TX path.

**Verification Method:** T — CW injection at TX port; measure power at RX port with VNA.

**Design Element:** PE8316 circulator (20 dB isolation); physical TX/RX array separation (additional ≥30 dB spatial isolation estimated from aperture geometry at 10 GHz).

---

### REQ-RF-006 — LNA Noise Figure

**Requirement:** Each receive chain LNA shall have a noise figure of ≤2.0 dB at the operating frequency 10.0–10.1 GHz and at temperatures up to +50°C.

**Rationale:** The HMC1040LP4E specifies 1.5 dB NF at room temperature; a 0.5 dB margin is allowed for temperature degradation and PCB trace losses ahead of the LNA input.

**Verification Method:** T — Noise figure analyser (Y-factor method) measurement of each LNA chain.

**Design Element:** HMC1040LP4E LNA; PCB layout (minimal trace between antenna feed and LNA input).

---

### REQ-RF-007 — LNA Gain

**Requirement:** The receive chain LNA shall provide ≥16 dB gain at 10.0–10.1 GHz to ensure the LNA noise figure dominates the cascaded system noise figure ahead of the combiner and mixer.

**Rationale:** The HMC1040 specifies 18 dB gain. Friis formula: F_sys = F_LNA + (F_combiner − 1)/G_LNA. At G_LNA = 63 (18 dB), even a combiner loss of 16 dB (Factor 40) contributes only 40/63 ≈ 0.6 to F_sys, well controlled.

**Verification Method:** T — Gain measurement using VNA or signal generator/power meter.

**Design Element:** HMC1040LP4E LNA; bias circuitry.

---

### REQ-RF-008 — Mixer Conversion Loss

**Requirement:** The RX mixer (HMC213B) conversion loss shall be ≤8 dB at LO power of +10 dBm ±2 dB over the 10.0–10.1 GHz RF input range, with IF output at frequencies ≤1 MHz.

**Rationale:** The HMC213B specifies 6 dB typical conversion loss with 10 dBm LO. The IF beat frequency for targets within 150 m ranges is below 100 kHz, well within the 5 GHz IF bandwidth of the HMC213B.

**Verification Method:** T — Two-tone measurement with VNA port 1 as RF (10 GHz), port 2 as LO (10 GHz), spectrum analyser on IF port.

**Design Element:** HMC213B mixer; LO power splitter from VCO/PA chain.

---

### REQ-RF-009 — Spurious Emissions

**Requirement:** Spurious emissions from the transmitter, measured at the TX antenna port, shall be ≤−50 dBc at any frequency other than the intended chirp carrier and its harmonics below −30 dBc.

**Rationale:** German amateur radio station operation must not cause harmful interference to other services. PLL reference spurs and VCO harmonics must be filtered. The 2nd harmonic at 20 GHz is outside amateur allocations; a low-pass filter after the PA is required.

**Verification Method:** T — Spectrum analyser measurement at TX antenna port, bandwidth 1–20 GHz.

**Design Element:** Low-pass filter after PA (fc ≈ 12 GHz); ADF4159 charge pump spur optimisation.

---

### REQ-RF-010 — Phase Shifter Resolution

**Requirement:** The phase shifter shall provide 6-bit resolution (64 discrete phase states) with an LSB phase step of 5.625° ±0.5° per bit, allowing phase settings from 0° to 354.375° in 5.625° increments.

**Rationale:** 6-bit phase resolution produces quantisation sidelobes of approximately −26 dB in the array pattern (20·log10(1/64) ≈ −36 dBc, reduced by statistical effects to approximately −26 dB for practical arrays), acceptable for this experimental application.

**Verification Method:** T — VNA measurement of insertion phase vs. SPI control word for each of 64 states for representative sample of HMC647A devices.

**Design Element:** HMC647ALP5E phase shifter; SPI control from STM32H743.

---

### REQ-RF-011 — Phase Shifter Settling Time

**Requirement:** The phase shifter shall settle to the commanded phase state within 50 ns of the SPI latch signal falling edge, allowing chirp-to-chirp beam steering updates at 1 kHz PRF.

**Rationale:** The HMC647A specifies a switching speed of <10 ns. At 1 ms chirp period and 50 ns settling, the effective duty cycle loss for beam reconfiguration is <0.005%, negligible.

**Verification Method:** T — Time-domain measurement of RF phase step response using a phase discriminator and oscilloscope.

**Design Element:** HMC647ALP5E phase shifter; SPI clock rate ≥10 MHz from STM32H743.

---

### REQ-RF-012 — Phase Shifter Insertion Loss

**Requirement:** The HMC647ALP5E insertion loss shall not exceed 8 dB at 10 GHz, and the insertion loss variation across all 64 phase states shall not exceed ±1.5 dB (amplitude ripple).

**Rationale:** Amplitude ripple across phase states causes beam pattern asymmetry and sidelobe elevation. The HMC647A specifies 6 dB typical insertion loss and ±1 dB amplitude variation.

**Verification Method:** T — VNA S21 measurement for all 64 states on 5 representative devices; record max variation.

**Design Element:** HMC647ALP5E phase shifter.

---

### REQ-RF-013 — Impedance Matching

**Requirement:** All RF ports (VCO output, PA input/output, LNA input/output, mixer RF/LO/IF, phase shifter input/output) shall be matched to 50 Ω with return loss ≥10 dB (VSWR ≤1.92:1) across the 10.0–10.1 GHz operating band.

**Rationale:** Impedance mismatches cause signal reflections, power loss, and potential oscillation in cascaded amplifiers. Each MMIC datasheet specifies 50 Ω matching conditions.

**Verification Method:** T — VNA S11 measurement at each port under operational bias conditions.

**Design Element:** PCB microstrip matching networks; MMIC bias circuits.

---

### REQ-RF-014 — Beam Steering Scan Loss

**Requirement:** The array gain reduction at ±45° scan angle relative to boresight shall not exceed 6 dB.

**Rationale:** For a uniform planar array, gain reduction at scan angle θ is approximately −10·log10(cos(θ)) per axis for element pattern effects, plus grating lobe and impedance mismatch contributions. At ±45°, cos(45°) = 0.707, yielding approximately −3 dB per axis or −6 dB combined for 2D scan.

**Verification Method:** A — Array factor calculation; D — antenna range measurement at ±45° scan.

**Design Element:** Antenna array element pattern (patch); phase shifter settings.

---

### REQ-RF-015 — Cross-Port Isolation of PA

**Requirement:** The HMC451LS6GE PA shall maintain output-to-input isolation ≥20 dB across the 10.0–10.1 GHz band to prevent oscillation via the PCB layout feedback path.

**Rationale:** High-gain amplifiers (28 dB) can oscillate if the reverse isolation (S12) is insufficient and board layout provides a feedback path. The HMC451 specifies >20 dB isolation.

**Verification Method:** T — VNA S12 measurement of assembled PA circuit on PCB.

**Design Element:** HMC451LS6GE; PCB layout ground via isolation.

---

## 4. Antenna Requirements (REQ-ANT)

### REQ-ANT-001 — Element Type and Substrate

**Requirement:** Antenna elements shall be rectangular microstrip patch radiators fabricated on Rogers RO4003C substrate, thickness 0.508 mm, relative permittivity εr = 3.55 ±0.05, loss tangent tan δ ≤ 0.0027 at 10 GHz.

**Rationale:** RO4003C is an industry-standard, low-loss, stable microwave laminate available in standard panel sizes. Its well-characterised electrical properties allow accurate antenna design using analytical models and EM simulation.

**Verification Method:** I — Manufacturer certificate of conformance; T — dielectric property measurement by resonator method.

**Design Element:** Antenna PCB fabrication; Rogers RO4003C laminate.

---

### REQ-ANT-002 — Patch Resonant Frequency

**Requirement:** Each patch antenna element shall resonate at 10.050 GHz ±50 MHz (S11 ≤ −15 dB at 10.050 GHz), as the centre of the 10.000–10.100 GHz chirp sweep.

**Rationale:** Patch dimensions of 13.8 mm × 13.8 mm on RO4003C (0.508 mm, εr = 3.55) give a resonant frequency of approximately 10.05 GHz based on the effective permittivity and fringing field model.

**Verification Method:** T — VNA S11 measurement of individual patch element with reference ground plane.

**Design Element:** Patch dimensions (13.8 mm × 13.8 mm); substrate thickness (0.508 mm).

---

### REQ-ANT-003 — Element Spacing

**Requirement:** The element spacing in both row and column directions shall be 15 mm ±0.2 mm (λ/2 at 10 GHz, where λ = 30 mm).

**Rationale:** Half-wavelength spacing is the standard design point for phased arrays, providing a 3 dB beamwidth consistent with REQ-SYS-008 (22° per axis for 4 elements) without grating lobes for scan angles up to ±90°.

**Verification Method:** I — Optical measurement of fabricated PCB element centres; gerber file inspection.

**Design Element:** Antenna PCB layout; KiCad footprint placement.

---

### REQ-ANT-004 — Array Size and Configuration

**Requirement:** Each of the TX and RX antenna arrays shall be configured as a 4×4 planar array (4 elements per row, 4 rows). The total TX aperture shall be 45 mm × 45 mm (3 element spacings per axis). The same dimensions apply to the RX array.

**Rationale:** A 4×4 array provides 16×16 = 256 two-way array factor, corresponding to approximately 48 dBi combined two-way gain (24 dBi each way), giving adequate EIRP for multi-kilometre detection range.

**Verification Method:** I — PCB layout inspection; T — antenna pattern measurement.

**Design Element:** Antenna PCB layout; feed network topology.

---

### REQ-ANT-005 — TX Array Gain

**Requirement:** The TX antenna array shall achieve a realised gain of ≥20 dBi at boresight at 10.050 GHz, accounting for impedance mismatch, ohmic loss in feed network, and patch radiation efficiency.

**Rationale:** Theoretical gain of a 4×4 array with λ/2 spacing is 10·log10(16·4π/λ²·0.01×0.01) ≈ 10·log10(16) + 10·log10(4π·A/λ²) for directivity ≈ 24 dBi. Deducting 2 dB for ohmic and mismatch losses gives a minimum requirement of 22 dBi (design target) with 20 dBi as the minimum passing criterion.

**Verification Method:** T — Antenna range gain measurement using calibrated gain standard horn at 10 GHz.

**Design Element:** 4×4 TX patch array; corporate feed Wilkinson divider network.

---

### REQ-ANT-006 — RX Array Gain

**Requirement:** The RX antenna array shall achieve a realised gain of ≥20 dBi at boresight at 10.050 GHz, under the same conditions as REQ-ANT-005.

**Verification Method:** T — Same method as REQ-ANT-005, applied to RX array.

**Design Element:** 4×4 RX patch array; corporate feed Wilkinson combiner network.

---

### REQ-ANT-007 — Antenna Beamwidth

**Requirement:** The 3 dB one-way beamwidth of each array (TX or RX) shall be 20°–25° in both azimuth and elevation at boresight, consistent with a 4-element, half-wavelength-spaced uniform linear array.

**Rationale:** Theoretical 3 dB beamwidth = 0.886·λ/(N·d) = 0.886/(4·0.5) = 0.443 rad ≈ 25.4° for a 4-element ULA at λ/2 spacing. In practice the patch element pattern narrows this slightly.

**Verification Method:** T — Antenna pattern measurement in azimuth and elevation planes.

**Design Element:** Antenna array geometry; element pattern.

---

### REQ-ANT-008 — Port Impedance

**Requirement:** The corporate feed network port impedance (at the SMA connector feeding each array) shall be 50 Ω ±5 Ω at 10.050 GHz, with return loss ≥15 dB.

**Rationale:** The RF chain is designed around 50 Ω transmission line impedance throughout. The Wilkinson divider output impedance is transformed to 50 Ω at each stage.

**Verification Method:** T — VNA S11 measurement at antenna SMA port.

**Design Element:** Wilkinson divider microstrip line dimensions; substrate εr.

---

### REQ-ANT-009 — TX/RX Cross-Panel Isolation

**Requirement:** The isolation between the TX array SMA feed port and the RX array SMA feed port, measured on the antenna panel with both arrays present, shall be ≥30 dB across 10.0–10.1 GHz.

**Rationale:** Combined with the PA-to-LNA isolation from PE8316 circulator (20 dB) and the combiner/divider network insertion losses, total TX-to-LNA-input isolation needs to be ≥50 dB (REQ-RF-005). The antenna panel contributes ≥30 dB from the physical separation and cross-polar orientation of TX and RX patches.

**Verification Method:** T — VNA S21 measurement from TX SMA port to RX SMA port on assembled antenna panel.

**Design Element:** TX and RX array physical separation (≥50 mm between array edges); absorber barrier between arrays if needed.

---

### REQ-ANT-010 — Cross-Polarisation Isolation

**Requirement:** The co-polar to cross-polar isolation of each patch element shall be ≥20 dB at boresight, measured at 10.050 GHz.

**Rationale:** Low cross-polarisation ensures clean beam pattern and reduces ambiguous target returns from cross-pol reflections.

**Verification Method:** T — Pattern measurement with co-polar and cross-polar reference horn; record null-to-peak ratio.

**Design Element:** Patch geometry; symmetric feed point placement.

---

## 5. Digital and Control Requirements (REQ-DIG)

### REQ-DIG-001 — ADC Resolution

**Requirement:** The analogue-to-digital converter shall provide ≥14 effective number of bits (ENOB) at the IF signal input frequency range of DC to 500 kHz, with a full-scale input range of ±4.096 V (configurable).

**Rationale:** The ADS8661IRGAT is a 16-bit SAR ADC with specified ENOB of ≥14.5 bits at low input frequencies. 14 ENOB provides a noise floor of 6.02×14 + 1.76 = 86.04 dBFS, sufficient to resolve target returns at −60 dBFS above noise.

**Verification Method:** T — FFT test: apply single-tone sine wave at 10 kHz; compute SINAD from FFT output.

**Design Element:** ADS8661IRGAT ADC; anti-aliasing filter on IF input.

---

### REQ-DIG-002 — ADC Sample Rate

**Requirement:** The ADC shall operate at a sample rate of 1 MSPS ±1% (1,000,000 samples per second ±10,000 sps), synchronised to the STM32H743 SPI clock.

**Rationale:** 1 MSPS provides a Nyquist bandwidth of 500 kHz, sufficient to capture beat frequencies corresponding to targets within 150 m at 100 MHz chirp bandwidth. Synchronisation with the chirp ramp timing ensures coherent processing.

**Verification Method:** T — Logic analyser measurement of SPI CLK frequency with ADS8661 in continuous conversion mode.

**Design Element:** ADS8661IRGAT; STM32H743 SPI peripheral clock divider configuration.

---

### REQ-DIG-003 — MCU Clock Speed

**Requirement:** The STM32H743ZIT6 shall operate at its maximum rated CPU frequency of 480 MHz using the external 25 MHz crystal or internal PLL, with all performance-critical peripherals (SPI, DMA, USB) enabled.

**Rationale:** 480 MHz provides sufficient DMIPS throughput to manage 6 SPI buses for 32 phase shifters plus ADC data, PLL control, and USB data forwarding simultaneously in a real-time RTOS context.

**Verification Method:** T — Oscilloscope measurement of SysTick timer period; verify CPU clock via debugger register.

**Design Element:** STM32H743ZIT6; external 25 MHz crystal oscillator; PLL configuration in STM32CubeIDE.

---

### REQ-DIG-004 — SPI Bus Speed for Phase Shifters

**Requirement:** The SPI interfaces controlling the HMC647ALP5E phase shifters shall operate at ≥10 Mbit/s to ensure all 32 phase shifters (TX and RX arrays) can be updated within 100 μs (one-tenth of the chirp period).

**Rationale:** Each HMC647A requires a 6-bit SPI word plus 2 bits framing = 8 bits. 32 phase shifters × 8 bits = 256 bits. At 10 Mbit/s, 256 bits requires 25.6 μs. With overhead, update time ≤100 μs is achievable. The STM32H743 SPI peripheral supports up to 150 Mbit/s.

**Verification Method:** T — Logic analyser measurement of SPI CLK frequency during phase-shifter update routine.

**Design Element:** STM32H743 SPI1–SPI6 configuration; SPI daisy-chain or parallel bus topology for phase shifters.

---

### REQ-DIG-005 — Phase Shifter Update Latency

**Requirement:** The time from issuance of a new beam direction command by the processing computer to completion of phase-shifter latch on all 32 devices shall be ≤200 μs, including SPI transfer time and GPIO latch pulse generation.

**Rationale:** At 1 kHz PRF (1 ms chirp period), a 200 μs update latency allows beam direction change between consecutive chirps, enabling electronically scanned operation.

**Verification Method:** T — Logic analyser trace from Ethernet command receipt to last phase shifter LE (latch enable) pulse assertion.

**Design Element:** STM32H743 firmware; SPI DMA configuration; phase shifter SPI topology.

---

### REQ-DIG-006 — ADC DMA Buffer

**Requirement:** The STM32H743 shall implement double-buffered DMA transfer of ADC samples, each buffer holding exactly 1000 samples (one chirp period), allowing the CPU to process one buffer while the DMA fills the other.

**Rationale:** Double-buffering prevents DMA buffer overruns at 1 MSPS. Buffer size of 1000 samples corresponds to exactly one 1 ms chirp at 1 MSPS.

**Verification Method:** T — Debugger observation of DMA buffer fill; verify no overrun flag in STM32 DMA status register over 10,000 consecutive chirps.

**Design Element:** STM32H743 DMA2 or MDMA controller; SRAM buffer allocation.

---

### REQ-DIG-007 — Data Transfer to Processing Computer

**Requirement:** Raw ADC data shall be transferred from STM32H743 to the RPi5 at a sustained rate of ≥2 MB/s to support 1 MSPS × 16-bit = 2 MB/s raw data throughput. The interface shall be USB 2.0 High Speed (480 Mbit/s) or 100BASE-TX Ethernet.

**Rationale:** USB 2.0 HS provides 480 Mbit/s theoretical maximum; practical CDC or bulk transfer rates of 25–40 MB/s are well above the 2 MB/s requirement.

**Verification Method:** T — Sustained data transfer test; measure throughput with `iperf` (Ethernet) or USB bulk transfer benchmark.

**Design Element:** STM32H743 USB HS peripheral (with ULPI PHY) or Ethernet MAC; RPi5 USB 3.0 or Ethernet port.

---

### REQ-DIG-008 — Chirp Synchronisation

**Requirement:** The start of each chirp ramp (ADF4159 ramp trigger) shall be synchronised to the ADC sampling start with a jitter of ≤100 ns to ensure coherent processing across the CPI.

**Rationale:** Chirp-to-ADC timing jitter causes phase errors across the CPI, elevating Doppler sidelobes and degrading velocity resolution. 100 ns jitter at 10 GHz corresponds to 1 rad phase error, which is tolerable with digital compensation.

**Verification Method:** T — Oscilloscope measurement of ADF4159 TXDATA pin (ramp start) vs. ADC CS (conversion start) edge timing across 1000 chirps.

**Design Element:** STM32H743 timer-based synchronisation; TXDATA GPIO to ADF4159; ADC CS GPIO.

---

### REQ-DIG-009 — Firmware Update Mechanism

**Requirement:** The STM32H743 firmware shall be updateable over USB using the STM32 built-in DFU (Device Firmware Upgrade) bootloader without requiring a JTAG/SWD debugger connection in the field.

**Rationale:** Field firmware updates are required for bug fixes and parameter changes without disassembly of the electronics box.

**Verification Method:** D — Demonstrate firmware update via USB DFU using STM32CubeProgrammer on a field laptop.

**Design Element:** STM32H743 USB FS peripheral; BOOT0 pin accessible from front panel; DFU bootloader activation logic.

---

### REQ-DIG-010 — Real-Time Operating System

**Requirement:** The STM32H743 firmware shall run under FreeRTOS with task priorities assigned to ensure ADC DMA interrupt handling and SPI phase-shifter update complete with deterministic latency ≤50 μs from interrupt to execution.

**Rationale:** Deterministic timing is essential for coherent radar operation. FreeRTOS priority scheduling prevents lower-priority tasks (USB data forwarding, configuration parsing) from blocking time-critical ADC and SPI operations.

**Verification Method:** T — FreeRTOS trace (Tracealyzer or SystemView) measurement of interrupt-to-task-run latency distribution over 10,000 events.

**Design Element:** STM32H743 FreeRTOS port; task priority configuration in main.c.

---

## 6. Power Requirements (REQ-PWR)

### REQ-PWR-001 — Input Voltage

**Requirement:** The system shall operate from a 24 V DC input voltage in the range 22.0–26.0 V DC, representing ±10% around the nominal 24 V.

**Rationale:** 24 V is a standard vehicle auxiliary and industrial DC power voltage. The ±10% range accommodates discharged (22 V LiFePO4) and fully charged (29.2 V LiFePO4 at 4-cell) battery states; the 26 V upper limit is set by DC-DC converter ratings.

**Verification Method:** T — Power supply test at 22 V, 24 V, and 26 V; verify system operation and measure output rail voltages.

**Design Element:** LT8612 and LT8607 DC-DC converters; input undervoltage protection circuit.

---

### REQ-PWR-002 — Input Current Limit

**Requirement:** The maximum input current drawn from the 24 V supply shall not exceed 8.0 A DC under any operational condition, including worst-case duty cycle with all RF stages active.

**Rationale:** The total power budget is 192 W (24 V × 8 A). Breakdown: PA at +30 dBm (HMC451, ~400 mA at 5 V drain = 2 W), VCO (HMC733, ~180 mA at 5 V = 0.9 W), 32 × HMC647A phase shifters (~50 mA at 5 V each = 8 W total), 16 × HMC1040 LNAs (~180 mA at 5 V = 14.4 W), MCU + RPi5 (~25 W combined). Total ≈ 80–120 W typical; 192 W is the hard ceiling.

**Verification Method:** T — Clamp meter measurement at 24 V input connector during maximum load operation.

**Design Element:** System power budget; DC-DC converter sizing.

---

### REQ-PWR-003 — 5 V Rail

**Requirement:** The 5 V output rail (generated by LT8612) shall maintain 5.0 V ±2% (4.9–5.1 V) at output currents up to 5 A. Output voltage ripple shall not exceed 50 mV peak-to-peak at 1 MHz switching frequency.

**Rationale:** The 5 V rail powers all RF MMICs (VCO, PA, LNA, phase shifters). Excessive ripple couples into the VCO tune voltage via the RF power supply, causing frequency modulation and elevated phase noise.

**Verification Method:** T — DMM voltage measurement at 5 A load; oscilloscope measurement of ripple with 20 MHz bandwidth.

**Design Element:** LT8612 DC-DC converter; output LC filter; bulk capacitance (470 μF electrolytic + 10 μF MLCC per RF device).

---

### REQ-PWR-004 — 3.3 V Rail

**Requirement:** The 3.3 V output rail (generated by LT8607) shall maintain 3.3 V ±2% (3.234–3.366 V) at output currents up to 3 A. Ripple shall not exceed 30 mV peak-to-peak.

**Rationale:** 3.3 V powers the STM32H743 I/O and logic, ADF4159, and ADS8661 ADC. ADC accuracy is sensitive to supply ripple; 30 mV corresponds to 30 mV/4096 mV ≈ 7.3 LSB at 16-bit full-scale, which must be reduced by decoupling at the ADC VCC pin.

**Verification Method:** T — Same measurement method as REQ-PWR-003.

**Design Element:** LT8607 DC-DC converter; ADC power supply decoupling (100 nF + 10 μF MLCC at AVDD pin).

---

### REQ-PWR-005 — ±5 V RF Bias Rail

**Requirement:** The ±5 V rails (generated by TPS65133) shall maintain ±5.0 V ±5% at currents up to ±1 A. Ripple shall not exceed 20 mV peak-to-peak on either rail.

**Rationale:** Some MMIC bias circuits require a negative supply for gate voltage. The TPS65133 provides regulated ±5 V from a single inductor charge pump architecture. The RF bias rails require exceptionally low ripple to avoid frequency pulling of the VCO.

**Verification Method:** T — Oscilloscope measurement at TPS65133 VOUT+ and VOUT− pins under nominal load.

**Design Element:** TPS65133 regulator; RF bias filter network (ferrite bead + MLCC Pi filter on each supply to each MMIC).

---

### REQ-PWR-006 — Power Sequencing

**Requirement:** At system power-on, the 5 V rail shall be stable before 3.3 V logic rails power-up. The RF MMICs shall be biased (gate/drain) only after the STM32H743 has completed initialisation and asserted a PA_ENABLE GPIO signal. At power-down, the PA_ENABLE signal shall be de-asserted before removing the 5 V supply.

**Rationale:** Out-of-sequence biasing can destroy GaAs pHEMT devices (HMC451 PA). The gate must be biased before the drain voltage is applied; the STM32H743 controls the drain enable via GPIO-controlled load switch.

**Verification Method:** T — Oscilloscope multi-channel capture of 5 V, 3.3 V, PA drain voltage, and STM32 PA_ENABLE GPIO at power-on and power-off transitions.

**Design Element:** STM32H743 GPIO PA_ENABLE; TPS2110 load switch for PA drain; power-on reset sequencer.

---

### REQ-PWR-007 — Input Protection

**Requirement:** The 24 V input shall be protected against reverse polarity (−24 V) and overvoltage up to +30 V transients without permanent damage to any system component.

**Rationale:** Field power connections (Anderson PowerPole) can be reversed by untrained users. Vehicle alternator load-dump transients can exceed 30 V for tens of milliseconds.

**Verification Method:** T — Apply −24 V for 5 seconds; remove and verify system powers up correctly. Apply 30 V transient (100 ms) via surge generator; verify no damage.

**Design Element:** P-channel MOSFET reverse-polarity protection; TVS diode (SMAJ30A) across input for overvoltage clamping.

---

### REQ-PWR-008 — Conversion Efficiency

**Requirement:** The combined DC-DC conversion efficiency from 24 V input to all regulated output rails (5 V, 3.3 V, ±5 V) shall be ≥85% under nominal load conditions.

**Rationale:** At 120 W typical load with 85% efficiency, input power is 141 W; 21 W is dissipated as heat in the converters and must be removed by the aluminium enclosure. Efficiency below 85% would require additional heatsinking.

**Verification Method:** T — Measure input power (V_in × I_in) and output powers (sum of V_out × I_out for each rail); compute η = P_out/P_in.

**Design Element:** LT8612, LT8607, TPS65133 converter selection; inductor and capacitor quality (DCR, ESR).

---

## 7. Mechanical Requirements (REQ-MEC)

### REQ-MEC-001 — Enclosure Dimensions

**Requirement:** The electronics enclosure (excluding antenna panel) shall not exceed 300 mm (L) × 200 mm (W) × 100 mm (H) external dimensions, fabricated from 3 mm wall aluminium alloy (6061-T6 or equivalent).

**Rationale:** This envelope fits in a standard field case (Pelican 1510 or equivalent) alongside the antenna panel, cabling, and accessories, allowing single-person transport.

**Verification Method:** I — Dimensional measurement with calipers.

**Design Element:** Mechanical enclosure design; PCB stack planning.

---

### REQ-MEC-002 — Antenna Panel Dimensions

**Requirement:** The antenna panel shall not exceed 200 mm (W) × 120 mm (H) × 5 mm (D, including connectors and standoffs). The panel shall be flat within 0.5 mm across its full area.

**Rationale:** Flatness is critical for antenna pattern integrity; a 0.5 mm bow at 10 GHz corresponds to λ/60 variation, negligible for the 22° beamwidth application.

**Verification Method:** I — Flatness measurement on surface plate; caliper measurement.

**Design Element:** Rogers RO4003C PCB; aluminium backing plate.

---

### REQ-MEC-003 — Tripod Mount

**Requirement:** The system shall include a standard 3/8-16 UNC threaded female insert (stainless steel, minimum depth 10 mm) located at the centre of mass of the electronics box ±25 mm, for direct attachment to a standard photo-tripod head.

**Rationale:** Standard 3/8-16 UNC is universal for tripods supporting loads over 3 kg, compatible with heavy-duty video heads and survey tripods.

**Verification Method:** I — Thread gauge measurement; load test with 10 kg (2× design margin).

**Design Element:** Enclosure base plate; stainless steel threaded insert (M8-to-3/8-16 adapter available as alternative).

---

### REQ-MEC-004 — System Weight

**Requirement:** The total system weight (electronics box + antenna panel + interconnect cables) shall not exceed 6 kg.

**Rationale:** Single-operator deployment requires a manageable carry weight. The 5 kg design target has a 1 kg margin to 6 kg requirement.

**Verification Method:** I — Weigh assembled system on calibrated scale.

**Design Element:** Aluminium enclosure wall thickness; PCB material choice; cable selection.

---

### REQ-MEC-005 — Connector Types and Locations

**Requirement:** The following connectors shall be provided on the enclosure rear panel in the positions shown in the mechanical drawing: (a) 1× Anderson PowerPole PP45 for 24 V DC input, (b) 2× SMA female (TX and RX RF test ports), (c) 1× USB Type-C (STM32H743 USB), (d) 1× RJ-45 Ethernet (RPi5), (e) 1× 4-pin M8 circular (CAN bus / spare digital I/O). Front panel shall have: 1× rocker power switch rated 15 A 30 V DC, 3× LED indicators (Power, RF Active, Fault/Status).

**Rationale:** All external connections on the rear panel prevent accidental disconnection when the unit is mounted on a tripod. LEDs on the front panel are visible to the operator standing in front of the system.

**Verification Method:** I — Visual inspection; connector mating test.

**Design Element:** Rear panel machining drawing; front panel silk-screen legend.

---

### REQ-MEC-006 — Ingress Protection

**Requirement:** The electronics enclosure shall achieve a minimum IP54 rating (dust protected, splash resistant from all directions) per IEC 60529. The antenna panel, mounted externally, shall be coated with a conformal coat rated for outdoor exposure (IPC-CC-830B compliant).

**Rationale:** Field use in Germany includes operation in rain and dusty environments. IP54 provides adequate protection without the cost and complexity of a fully sealed IP67 enclosure.

**Verification Method:** T — IP54 water spray test per IEC 60529 §14.2.3; verify no ingress into electronics cavity.

**Design Element:** Enclosure O-ring seal; cable gland for umbilical; conformal coating of antenna PCB.

---

### REQ-MEC-007 — Thermal Management

**Requirement:** The PA (HMC451LS6GE) junction temperature shall not exceed 125°C at +50°C ambient with maximum continuous TX operation. The enclosure internal temperature shall not exceed +70°C under any operating condition.

**Rationale:** The HMC451 maximum junction temperature is 150°C. At 28 dB gain and +30 dBm output, the PA dissipates approximately 3 W. With a 3 W device-to-case thermal resistance of 15°C/W and case-to-ambient of 5°C/W, junction temperature at 50°C ambient is 50 + 3×(15+5) = 110°C, within limit.

**Verification Method:** T — Thermal camera measurement of PA package at +50°C ambient during 30-minute continuous operation.

**Design Element:** PA PCB thermal via array; aluminium chassis heatsink contact; thermal interface pad (Bergquist GP3000).

---

### REQ-MEC-008 — Cable Management

**Requirement:** The umbilical cable bundle connecting the electronics box to the antenna panel shall be ≤1.5 m in length, terminated with SMA connectors (RF) and a multi-pin connector (power, SPI, control) at each end. Minimum bend radius shall be 30 mm for SMA cables at 10 GHz.

**Rationale:** Excessive cable length introduces insertion loss (0.5 dB/m for RG-405 semi-rigid at 10 GHz). 1.5 m is sufficient for tripod deployment without excessive loss.

**Verification Method:** I — Physical measurement; VNA insertion loss measurement of assembled cable set.

**Design Element:** RF cable selection (RG-405 or Flexiform 047); cable harness design.

---

## 8. Software Requirements (REQ-SW)

### REQ-SW-001 — Real-Time Control Firmware (STM32)

**Requirement:** The STM32H743 firmware shall implement all radar control functions including: ADF4159 SPI initialisation and chirp ramp configuration, HMC647A phase-shifter SPI update, ADS8661 ADC SPI sampling at 1 MSPS, chirp start/stop synchronisation, and USB/Ethernet data forwarding to RPi5.

**Verification Method:** D — Functional demonstration of all control outputs while monitoring with logic analyser.

**Design Element:** STM32H743 firmware; FreeRTOS task design.

---

### REQ-SW-002 — FMCW Signal Processing Pipeline

**Requirement:** The processing software on RPi5 shall implement the following signal chain: (1) receive raw ADC samples from STM32, (2) apply Hann window per chirp, (3) compute 1024-point range FFT per chirp, (4) stack 100 range FFT outputs into a 100×512 range-Doppler matrix, (5) apply Hann window along slow-time axis, (6) compute 128-point Doppler FFT across slow-time, producing a range-Doppler map.

**Verification Method:** T — Inject synthetic target signal; verify correct range bin and Doppler bin detection.

**Design Element:** Python signal processing module (numpy.fft); data receiver thread.

---

### REQ-SW-003 — CFAR Detection

**Requirement:** The software shall implement Cell-Averaging CFAR (CA-CFAR) detection in the range-Doppler map with configurable guard cells (default 2) and reference cells (default 16), and a configurable probability of false alarm (PFA, default 10⁻⁴).

**Verification Method:** T — Inject simulated target at SNR = 13 dB; verify detection rate ≥90% and false alarm rate ≤0.01% in 10,000 test frames.

**Design Element:** Python CFAR module; configurable parameters in config.yaml.

---

### REQ-SW-004 — Graphical User Interface

**Requirement:** The processing software shall provide a real-time GUI displaying: (a) range-Doppler power map (colour-mapped dB scale), (b) detected target list (range, velocity, bearing), (c) beam direction indicator, (d) system status (RF active, temperature, power rails status), and (e) controls for beam steering direction, CFAR threshold, and display range scale.

**Verification Method:** D — Visual demonstration of GUI with live data or replay of recorded data file.

**Design Element:** Python/PyQt6 GUI; Matplotlib/pyqtgraph range-Doppler plot widget.

---

### REQ-SW-005 — Data Logging

**Requirement:** The software shall log raw ADC samples (or processed range-Doppler maps, selectable) to disk in HDF5 format with timestamps, system configuration, and GPS coordinates (if external GPS receiver is connected via USB). Log file size shall not exceed 2 GB per hour at 1 MSPS full-raw logging.

**Rationale:** Raw data logging enables offline reprocessing with improved algorithms without requiring a new measurement campaign.

**Verification Method:** T — Run system for 1 hour in raw logging mode; verify file size ≤2 GB and correct data format using h5py.

**Design Element:** Python logging module; h5py library; configurable logging mode in config.yaml.

---

### REQ-SW-006 — Beamforming Control

**Requirement:** The software shall provide a beamforming control API that accepts a target direction (azimuth, elevation in degrees) and computes the required 32 phase-shifter control words using the planar array steering vector equation, then transmits the control words to the STM32H743 over the control interface.

**Verification Method:** T — Command beam to known angles (0°, ±22.5°, ±45°); verify received signal strength peaks at expected angles using a fixed CW test source.

**Design Element:** Python beamforming module; TCP socket command interface to STM32.

---

### REQ-SW-007 — Calibration Routine

**Requirement:** The software shall include an antenna array calibration routine that: (a) sweeps beam directions in 5° steps, (b) measures received signal strength from a known calibration reflector or CW source at a fixed known location, (c) computes per-element amplitude and phase correction coefficients, and (d) stores coefficients in a calibration file applied during normal operation.

**Verification Method:** D — Run calibration routine with corner reflector at 50 m range; verify beam pattern improvement vs. uncalibrated.

**Design Element:** Python calibration module; calibration coefficient storage (JSON or HDF5).

---

### REQ-SW-008 — Configuration Management

**Requirement:** All system operating parameters (frequency, chirp bandwidth, PRF, CPI length, CFAR thresholds, beam scan pattern, logging options) shall be stored in a human-readable YAML configuration file loadable at startup and modifiable without recompiling firmware or software.

**Verification Method:** I — Inspect config.yaml; D — modify parameter and verify changed behaviour.

**Design Element:** config.yaml; Python configparser module; STM32 parameter upload command.

---

### REQ-SW-009 — Station Identification Automation

**Requirement:** The firmware shall implement an automated station identification interrupt: at every 10-minute interval, the system shall briefly (≤5 seconds) transmit the operator's callsign in Morse code (CW) at the current operating frequency, then resume radar operation.

**Rationale:** AFuV 2017 §14 requires station identification at maximum 10-minute intervals. Automating this ensures compliance without operator action.

**Verification Method:** D — Run system for 15 minutes; verify CW identification burst transmitted at minute 10; verify callsign is correct (configurable in config.yaml).

**Design Element:** STM32H743 FreeRTOS timer task; CW keyer function; callsign string in config.

---

### REQ-SW-010 — Remote Control Interface

**Requirement:** The RPi5 shall expose a TCP/IP control interface (port 5555) allowing a remote laptop to send beam steering commands, request system status, start/stop recording, and query the detected target list. The interface shall use a simple JSON command-response protocol.

**Verification Method:** T — Connect via `netcat` from remote laptop; send JSON command {"cmd": "beam", "az": 30.0, "el": 0.0}; verify system responds with {"status": "ok"} and beam updates.

**Design Element:** Python asyncio TCP server on RPi5; JSON command parser.

---

### REQ-SW-011 — Software Licence

**Requirement:** All processing software and firmware source code shall be released under an OSI-approved open-source licence. Firmware shall be licensed under GPL-3.0 or MIT. Processing software shall be licensed under MIT or Apache-2.0.

**Verification Method:** I — SPDX licence header in all source files; LICENSE file in repository root.

**Design Element:** GitHub/GitLab repository; SPDX header template.

---

### REQ-SW-012 — Software Build Reproducibility

**Requirement:** The processing software shall have a reproducible build environment specified by a requirements.txt (Python pip) and a Dockerfile (for RPi5 deployment), ensuring consistent library versions across installations.

**Verification Method:** D — Fresh build in Docker container from repository; verify all tests pass.

**Design Element:** requirements.txt; Dockerfile; GitHub Actions CI pipeline.

---

## 9. Regulatory Requirements (REQ-REG)

### REQ-REG-001 — Frequency Band Compliance

**Requirement:** The transmitter shall operate exclusively in the 10.000–10.100 GHz range as specified in REQ-SYS-001. Spurious emissions outside the 10.000–10.500 GHz amateur band shall be suppressed per REQ-RF-009.

**Verification Method:** T — Spectrum analyser measurement.

**Design Element:** ADF4159 frequency limits programmed in firmware; output low-pass filter.

---

### REQ-REG-002 — Transmitter Output Power Compliance

**Requirement:** The transmitter output power at the PA output shall not exceed +47.75 dBm (75 W PEP) under any operating condition, in compliance with AFuV 2017 Anlage 1 for the 3 cm band.

**Rationale:** The design target of +30 dBm (1 W) is 47.75 dB below the 75 W legal limit, providing 17.75 dB regulatory headroom.

**Verification Method:** T — Calibrated power meter at TX port.

**Design Element:** PA drive level; ADF4159 output power setting.

---

### REQ-REG-003 — Station Identification

**Requirement:** The system shall transmit the operator's callsign in CW or voice at the beginning of each operational session and at intervals not exceeding 10 minutes, as required by AFuV 2017 §14.

**Verification Method:** D — Verify automated 10-minute CW ID from REQ-SW-009.

**Design Element:** STM32H743 firmware CW ID timer.

---

### REQ-REG-004 — Operator Licence Verification

**Requirement:** The system configuration file shall require entry of a valid Klasse A callsign before activating the transmitter. The software shall not enable the RF stages (PA_ENABLE) without a non-empty callsign string in config.yaml.

**Verification Method:** D — Attempt to start system with empty callsign field; verify transmitter does not activate.

**Design Element:** STM32H743 firmware callsign validation; RPi5 software pre-flight check.

---

### REQ-REG-005 — Non-Interference Declaration

**Requirement:** System operating procedures shall include a statement that the AERIS-10P operates on a non-interference basis as a secondary user of the 10 GHz band, and the operator shall immediately cease transmission if interference to a primary user is detected.

**Verification Method:** I — Inspection of operating procedure document included in user documentation.

**Design Element:** User documentation; operating procedure SOP-001.

---

### REQ-REG-006 — Experimental Radar Permit Documentation

**Requirement:** Field operation of the AERIS-10P outside the operator's licensed station address shall be preceded by submission of a Frequenznutzungsantrag or Experimentallizenz application to BNetzA Referat 225. The system documentation shall include a template application letter.

**Verification Method:** I — Template letter present in documentation package.

**Design Element:** Regulatory documentation package.

---

## 10. Safety Requirements (REQ-SAF)

### REQ-SAF-001 — RF Exposure Safety Distance

**Requirement:** A minimum safety exclusion distance of 4 m from the boresight of the transmitting antenna shall be maintained during operation, enforced by physical barriers (safety tape, cones) or supervision during any measurement session.

**Rationale:** At +30 dBm TX power, 22 dBi gain, and 4 m distance: far-field power density S = EIRP/(4πR²) = 158/(4π×16) = 0.79 W/m², below the BNetzA general public limit of 10 W/m² at 10 GHz. Note: at distances below the Rayleigh distance (2D²/λ = 2×0.045²/0.03 = 0.135 m), near-field analysis is required; at 4 m, far-field formula applies.

**Verification Method:** T — Power density measurement at 4 m range using a calibrated EMF probe (Narda NBM-550 or equivalent).

**Design Element:** Safety procedure SOP-001; physical site preparation.

---

### REQ-SAF-002 — RF Interlock

**Requirement:** The system shall include a hardware RF kill switch accessible from the operator position that immediately de-asserts PA_ENABLE and disables the VCO ramp, cutting transmit power within 10 ms of actuation.

**Verification Method:** T — Actuate kill switch during transmission; measure power at TX port; verify ≤10 ms to −40 dBm or lower.

**Design Element:** Front panel emergency stop button; STM32H743 external interrupt on kill switch GPIO; PA drain load switch.

---

### REQ-SAF-003 — Electrical Safety

**Requirement:** The 24 V DC input wiring shall use wire gauge ≥12 AWG rated for ≥10 A. All high-current connections shall use approved crimp terminals. The enclosure shall be bonded to chassis ground. A resettable polyfuse or automotive-type fuse (10 A) shall be installed in the 24 V positive input line within 15 cm of the power connector.

**Verification Method:** I — Visual inspection of wiring and fuse; measurement of chassis-to-earth continuity ≤0.1 Ω.

**Design Element:** Power wiring harness; enclosure grounding lug.

---

### REQ-SAF-004 — Warning Labels

**Requirement:** The following labels shall be affixed to the antenna panel and electronics box: (a) "CAUTION: RF RADIATION — Do not stand within 4 m of antenna aperture during operation," (b) "ACTIVE RADAR — Licensed amateur radio use only," (c) Operator callsign and contact information.

**Verification Method:** I — Inspect labels on assembled system.

**Design Element:** Enclosure labelling; antenna panel silkscreen or adhesive label.

---

### REQ-SAF-005 — Thermal Protection

**Requirement:** The PA (HMC451) shall be equipped with a thermistor (NTC, 10 kΩ at 25°C) mounted on the PCB within 5 mm of the PA package. If the thermistor reading corresponds to a temperature ≥100°C, the STM32H743 shall de-assert PA_ENABLE and set the Fault LED.

**Verification Method:** T — Simulate overtemperature by heating thermistor to 100°C equivalent resistance; verify PA disable occurs.

**Design Element:** NTC thermistor footprint on RF PCB; STM32H743 ADC input for thermistor; firmware thermal protection task.

---

### REQ-SAF-006 — Grounding and ESD Protection

**Requirement:** All SMA RF connectors shall be grounded to the chassis through direct metal contact. All digital I/O lines entering or leaving the enclosure shall be protected with ESD protection diodes (TVS or Zener, VBRL ≤5.5 V) at the PCB connector.

**Verification Method:** I — Inspect connector grounding; measure SMA shell-to-chassis resistance ≤0.1 Ω.

**Design Element:** PCB connector footprints; chassis bonding straps; ESD protection diode placement.

---

## 11. Requirements Traceability Matrix

| Requirement ID | Requirement Description (Short) | Design Element | Verification | Status |
|---|---|---|---|---|
| REQ-SYS-001 | Operating frequency 10.0–10.1 GHz | ADF4159 + HMC733 | T | Open |
| REQ-SYS-002 | FMCW, 100 MHz BW, 1 kHz PRF | ADF4159 chirp config | T | Open |
| REQ-SYS-003 | Range resolution ≤1.5 m | Chirp BW + Range FFT | T | Open |
| REQ-SYS-004 | Velocity resolution ≤0.15 m/s | CPI length + Doppler FFT | A+D | Open |
| REQ-SYS-005 | Unambiguous range ≥75 m | ADC sample rate + IF BW | A+T | Open |
| REQ-SYS-006 | System NF ≤8 dB | HMC1040 LNA + combiner | T | Open |
| REQ-SYS-007 | TX power +30 dBm ±1 dB | HMC451 PA | T | Open |
| REQ-SYS-008 | Beam steering ±45° | HMC647A + beamform algo | D | Open |
| REQ-SYS-009 | Operating temp −10°C to +50°C | Full system | T | Open |
| REQ-SYS-010 | Update rate ≥10 Hz | RPi5 processing | T | Open |
| REQ-RF-001 | Reference accuracy ±0.01 ppm | AOCJY-10 OCXO | T | Open |
| REQ-RF-002 | VCO phase noise ≤−80 dBc/Hz @100 kHz | HMC733 + ADF4159 loop | T | Open |
| REQ-RF-003 | Chirp linearity ±500 kHz | ADF4159 ramp + VCO Kv | T | Open |
| REQ-RF-004 | TX power flatness ±1 dB | HMC451 gain flatness | T | Open |
| REQ-RF-005 | TX/RX isolation ≥50 dB | PE8316 + array separation | T | Open |
| REQ-RF-006 | LNA NF ≤2.0 dB | HMC1040LP4E | T | Open |
| REQ-RF-007 | LNA gain ≥16 dB | HMC1040LP4E | T | Open |
| REQ-RF-008 | Mixer conversion loss ≤8 dB | HMC213B | T | Open |
| REQ-RF-009 | Spurious emissions ≤−50 dBc | LPF after PA | T | Open |
| REQ-RF-010 | Phase shifter resolution 5.625°/bit | HMC647ALP5E | T | Open |
| REQ-RF-011 | Phase shifter settling ≤50 ns | HMC647ALP5E | T | Open |
| REQ-RF-012 | Phase shifter IL ≤8 dB, ripple ±1.5 dB | HMC647ALP5E | T | Open |
| REQ-RF-013 | All ports 50 Ω, RL ≥10 dB | PCB matching networks | T | Open |
| REQ-RF-014 | Scan loss ≤6 dB at ±45° | Array element pattern | A+D | Open |
| REQ-RF-015 | PA output-to-input isolation ≥20 dB | HMC451 + PCB layout | T | Open |
| REQ-ANT-001 | RO4003C substrate | Rogers RO4003C PCB | I+T | Open |
| REQ-ANT-002 | Patch resonant at 10.05 GHz | 13.8×13.8 mm patch | T | Open |
| REQ-ANT-003 | Element spacing 15 mm ±0.2 mm | PCB layout | I | Open |
| REQ-ANT-004 | 4×4 TX and 4×4 RX arrays | Antenna PCB | I+T | Open |
| REQ-ANT-005 | TX array gain ≥20 dBi | 4×4 TX array + feed net | T | Open |
| REQ-ANT-006 | RX array gain ≥20 dBi | 4×4 RX array + feed net | T | Open |
| REQ-ANT-007 | Beamwidth 20°–25° | Array geometry | T | Open |
| REQ-ANT-008 | Feed port 50 Ω, RL ≥15 dB | Wilkinson divider | T | Open |
| REQ-ANT-009 | TX/RX panel isolation ≥30 dB | Array separation | T | Open |
| REQ-ANT-010 | Cross-pol isolation ≥20 dB | Patch geometry | T | Open |
| REQ-DIG-001 | ADC ENOB ≥14 bits | ADS8661IRGAT | T | Open |
| REQ-DIG-002 | ADC sample rate 1 MSPS ±1% | ADS8661 + STM32 SPI | T | Open |
| REQ-DIG-003 | MCU clock 480 MHz | STM32H743 PLL | T | Open |
| REQ-DIG-004 | SPI speed ≥10 Mbit/s | STM32H743 SPI config | T | Open |
| REQ-DIG-005 | Phase shift update latency ≤200 μs | STM32 firmware + SPI | T | Open |
| REQ-DIG-006 | ADC double-buffer DMA | STM32 DMA config | T | Open |
| REQ-DIG-007 | Data transfer ≥2 MB/s | USB HS or Ethernet | T | Open |
| REQ-DIG-008 | Chirp sync jitter ≤100 ns | STM32 timer sync | T | Open |
| REQ-DIG-009 | USB DFU firmware update | STM32 DFU bootloader | D | Open |
| REQ-DIG-010 | FreeRTOS, latency ≤50 μs | STM32 RTOS config | T | Open |
| REQ-PWR-001 | Input voltage 22–26 V DC | LT8612/LT8607 | T | Open |
| REQ-PWR-002 | Input current ≤8 A | System power budget | T | Open |
| REQ-PWR-003 | 5 V ±2%, ripple ≤50 mV | LT8612 | T | Open |
| REQ-PWR-004 | 3.3 V ±2%, ripple ≤30 mV | LT8607 | T | Open |
| REQ-PWR-005 | ±5 V ±5%, ripple ≤20 mV | TPS65133 | T | Open |
| REQ-PWR-006 | Power sequencing: 5V before 3.3V, PA last | STM32 GPIO + load switch | T | Open |
| REQ-PWR-007 | Input reverse polarity and OV protection | MOSFET + TVS | T | Open |
| REQ-PWR-008 | DC-DC efficiency ≥85% | LT8612/LT8607 | T | Open |
| REQ-MEC-001 | Enclosure ≤300×200×100 mm aluminium | Mechanical drawing | I | Open |
| REQ-MEC-002 | Antenna panel ≤200×120×5 mm, flat ±0.5 mm | Antenna panel drawing | I | Open |
| REQ-MEC-003 | 3/8-16 UNC tripod mount | Enclosure base plate | I+T | Open |
| REQ-MEC-004 | Total weight ≤6 kg | System assembly | I | Open |
| REQ-MEC-005 | Connector layout per mechanical drawing | Rear/front panel | I | Open |
| REQ-MEC-006 | IP54 enclosure, conformal coat antenna | Enclosure sealing | T+I | Open |
| REQ-MEC-007 | PA Tj ≤125°C at +50°C ambient | PA thermal design | T | Open |
| REQ-MEC-008 | Cable ≤1.5 m, ≥30 mm bend radius | Cable harness | I+T | Open |
| REQ-SW-001 | STM32 radar control firmware | STM32 FW | D | Open |
| REQ-SW-002 | Range-Doppler FFT pipeline | RPi5 Python | T | Open |
| REQ-SW-003 | CA-CFAR detection | Python CFAR module | T | Open |
| REQ-SW-004 | Real-time GUI | PyQt6 GUI | D | Open |
| REQ-SW-005 | HDF5 data logging ≤2 GB/hr | Python logger | T | Open |
| REQ-SW-006 | Beamforming API | Python beamform module | T | Open |
| REQ-SW-007 | Calibration routine | Python calibration | D | Open |
| REQ-SW-008 | YAML configuration | config.yaml | I+D | Open |
| REQ-SW-009 | 10-minute CW station ID | STM32 FW CW keyer | D | Open |
| REQ-SW-010 | TCP/IP JSON control interface | RPi5 asyncio server | T | Open |
| REQ-SW-011 | Open-source licence | Repository SPDX headers | I | Open |
| REQ-SW-012 | Reproducible build (requirements.txt + Docker) | Dockerfile | D | Open |
| REQ-REG-001 | Frequency band compliance | ADF4159 + LPF | T | Open |
| REQ-REG-002 | TX power ≤75 W PEP | PA output power limit | T | Open |
| REQ-REG-003 | Station identification ≤10 min | CW ID firmware | D | Open |
| REQ-REG-004 | Callsign required before TX enable | STM32 FW pre-check | D | Open |
| REQ-REG-005 | Non-interference declaration | Operating procedures | I | Open |
| REQ-REG-006 | BNetzA experimental permit template | Documentation | I | Open |
| REQ-SAF-001 | 4 m RF exclusion zone | Site procedure | T | Open |
| REQ-SAF-002 | Hardware RF kill switch | Front panel E-stop | T | Open |
| REQ-SAF-003 | Electrical safety: wiring, fuse, chassis ground | Power harness | I | Open |
| REQ-SAF-004 | Warning labels on enclosure and antenna | Labels | I | Open |
| REQ-SAF-005 | PA overtemperature protection | NTC + STM32 FW | T | Open |
| REQ-SAF-006 | Grounding and ESD protection | PCB layout + chassis | I | Open |

---

## 12. Revision History

| Revision | Date | Author | Description |
|---|---|---|---|
| 1.0 | 2026-07-14 | AERIS-10P Engineering Team | Initial release of requirements specification. |

---

*End of Document — AERIS-10P-REQ-001 Rev 1.0*

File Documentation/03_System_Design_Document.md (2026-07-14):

# AERIS-10P System Design Document Rev 1.0

**Document Number:** AERIS-10P-SDD-001  
**Revision:** 1.0  
**Date:** 2026-07-14  
**Author:** AERIS-10P Engineering Team  
**Status:** Released  
**Parent Documents:** AERIS-10P-SPEC-001, AERIS-10P-REQ-001

---

## Table of Contents

1. Architecture Overview
2. Subsystem Descriptions
   - 2.1 Chirp Generator (ADF4159 + HMC733)
   - 2.2 Transmit Chain
   - 2.3 Phase Shifter Array
   - 2.4 Antenna Array
   - 2.5 Receive Chain
   - 2.6 ADC and MCU Interface
   - 2.7 Signal Processing (RPi5)
   - 2.8 Power Subsystem
3. Link Budget
4. Signal Flow: Time and Frequency Domain
5. Beamforming Algorithm
6. Design Trade-offs
7. Interfaces
8. Performance Predictions

---

## 1. Architecture Overview

### 1.1 Design Philosophy

The AERIS-10P implements a homodyne FMCW radar architecture with analogue phased-array beamforming. The homodyne (self-mixing) approach uses the same chirp signal as both the transmit waveform and the local oscillator (LO) reference for the receiver mixer, generating an intermediate frequency (IF) beat signal directly at baseband without a separate IF stage. This choice simplifies the receiver architecture: no IF amplifier, no IF filter design at high frequency, and no separate LO synthesiser. The penalty is increased susceptibility to DC offset (zero-range clutter) and 1/f noise at very low IF frequencies.

The beamforming is performed in the analogue domain using 6-bit digital phase shifters on each transmit and receive element. This is designated as analogue beamforming (as opposed to digital beamforming, where each element has its own ADC). Analogue beamforming was selected for this application to avoid the cost and complexity of 32 high-speed ADC channels; the trade-off is that only a single beam direction can be formed at any instant, and changing the beam direction requires reprogramming the phase shifters between CPI intervals.

### 1.2 Complete Signal Chain Block Diagram

```
=============================================================
                    AERIS-10P SIGNAL CHAIN
=============================================================
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

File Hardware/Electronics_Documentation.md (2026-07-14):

# AERIS-10P Electronics Documentation
## Rev 1.0 — 2026-07-14

---

## 1. PCB Stackup Specifications

### FR4 Boards (Main Control, Power)

**4-layer FR4 stackup (Main Control Board):**
- Layer 1 (top): Signal — component side, digital signals, USB traces
- Prepreg 1 (7628): 0.2mm
- Layer 2: Ground — solid copper pour, RF shield
- Core (FR4): 0.8mm
- Layer 3: Power — +3.3V and +5V planes
- Prepreg 2 (7628): 0.2mm
- Layer 4 (bottom): Signal — additional routing, SPI buses
- Total board thickness: ~1.6mm

**2-layer FR4 stackup (Power Board):**
- Layer 1: Power supply components and routing
- Core FR4: 1.4mm
- Layer 2: Ground plane (solid copper)
- Total: 1.6mm

### Rogers Boards (RF Frontend, Phase Shifter, Antenna)

**4-layer Rogers/FR4 hybrid stackup (Phase Shifter Board):**
- Layer 1 (top): Rogers RO4003C 0.508mm — 50Ω microstrip RF traces
- Bond layer: Rogers RO4403C bondply 0.1mm
- Layer 2: Ground — solid copper, 1oz
- Core FR4: 0.6mm
- Layer 3: Power (+5V) — FR4 prepreg
- Layer 4 (bottom): FR4 — SPI control signals
- Total: ~1.5mm

**Note:** PCBWay calls this "Rogers mixed material board" — specify in order notes.

---

## 2. Grounding Strategy

**Star ground topology:**
- All supply return currents meet at a single star point near the 24V input
- Separate ground planes for: analog RF, digital control, power supply
- Connect planes at single point under each board

**RF board grounding:**
- Solid copper ground plane on layer 2 (no splits)
- Ground via fence along all RF traces (0.3mm drill, 0.6mm pad, every 3mm)
- Exposed pad (thermal) of QFN ICs must connect directly to ground plane via multiple vias
- No digital signals crossing under RF traces on layer 4

**Mixed-signal board (Main Control):**
- Analog section (ADC) on one corner, digital section on other
- Single ground plane, but keep analog and digital routes separated
- Decouple ADC AVDD and DVDD with separate ferrite bead from main supply

---
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

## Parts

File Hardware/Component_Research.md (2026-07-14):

# AERIS-10P Component Research and Selection
## Rev 1.0 — 2026-07-14

Complete research document for all major ICs. Each entry: selected part, rationale, alternatives, pricing, availability.

---

## 1. Phase Shifter — HMC647ALP5E (Selected)

**Selected:** HMC647ALP5E (Analog Devices, formerly Hittite Microwave)
- 6-bit digital phase shifter, 10–14 GHz
- Insertion loss: 4 dB typical at 10 GHz
- Phase range: 0–360° in 64 steps (5.625° LSB)
- Phase accuracy: ±1.5° RMS
- Switching time: <2 µs
- Supply: +5V, 90 mA
- Package: QFN-32, 5×5 mm
- Mouser: 597-HMC647ALP5E, ~$35/unit

**Why selected:** Only 6-bit MMIC digital phase shifter available at 10 GHz from stock distributors in 2025–2026. The 6-bit resolution (5.625° LSB) matches our 4-element array beam width (22°) — one LSB corresponds to 22°/4 ≈ 5.5°, which is well matched.

**Alternative 1: MAPS-010144 (Macom, 5-bit)**
- 5 bits = 11.25° LSB — coarser control than HMC647A
- Cheaper (~$18/unit) but less phase resolution
- Rejected: 5-bit insufficient for precise beam control

**Alternative 2: Custom GaAs MMIC**
- Better specs (lower insertion loss) but minimum order quantity 100+ units, 16-week lead time, $50k NRE
- Rejected: impractical for research prototype

---

## 2. VCO — HMC733LP6CE (Selected)

**Selected:** HMC733LP6CE (Analog Devices)
- Frequency: 9.5–11.0 GHz
- Output power: +17 dBm
- Phase noise: -120 dBc/Hz @ 100 kHz
- Tuning sensitivity: 40 MHz/V typical
- Supply: +5V, Vtune 0–12V
- Package: LP-6 (5×5 mm)
- Mouser: 597-HMC733LP6CE, ~$45/unit

**Why selected:** Best phase noise at 10 GHz in LCC package. Critical for FMCW clutter rejection — VCO phase noise limits ability to detect slow targets in clutter.

**Alternative: HMC-SXX112 (integrated PLL+VCO)**
- All-in-one but less flexibility, worse phase noise
- Rejected: phase noise is critical; separate VCO+PLL gives better control

---

## 3. PLL — ADF4159CCPZ (Selected)

**Selected:** ADF4159CCPZ (Analog Devices)
- Fractional-N PLL, up to 13 GHz
- Built-in FMCW sawtooth/triangular ramp generator
- Reference: up to 110 MHz
- PFD: up to 110 MHz
- Charge pump: 0.3–4.77 mA programmable
- SPI programmable (32-bit registers)
- Package: CP-40-3, 6×6 mm
- Mouser: 584-ADF4159CCPZ, ~$28/unit

**Why selected:** The ADF4159 is one of the few PLLs with a built-in hardware FMCW ramp generator. This eliminates the need for software-generated chirps (which would require real-time MCU intervention at high rates). The ramp runs autonomously in hardware after programming.

**ADF4159 register programming tool:** ADIsimPLL (free from analog.com) can compute all register values from desired frequency and ramp parameters.

---

## 4. TX PA — HMC451LS6GE (Selected)

**Selected:** HMC451LS6GE (Analog Devices)
- Frequency: 8–15 GHz
- Gain: 28 dB
- P1dB: +29 dBm (0.8 W)
- PAE: 20% @ P1dB
- Supply: VDD1=+5V (300 mA), VDD2=+5V (200 mA), VGG1/2 = 0 to -1V
- Package: SMT LS-6 (6-pin, 4×4 mm)
- Mouser: 597-HMC451LS6GE, ~$65/unit

**Why selected:** Available in stock at Mouser/DigiKey, covers 10 GHz well, +29 dBm is significantly above 75 W PEP legal limit concern (we operate at +27 dBm, 2W, far below 75W). Good efficiency (20%).

**Thermal note:** At +27 dBm output with 20% PAE, supply power = 10W output / PAE = 10·(10^(27/10)/1000)/0.20 = 0.5/0.2 = 2.5W supply. Dissipation = 2.5 - 0.5 = 2W heat. Heatsink required.

---

## 5. LNA — HMC1040LP4E (Selected)

**Selected:** HMC1040LP4E (Analog Devices)
- Frequency: 8–12 GHz
- Noise Figure: 1.5 dB
- Gain: 18 dB
- P1dB: +18 dBm
- OIP3: +30 dBm
- Supply: VDD = +3.3V, 15 mA per device
- Package: QFN-24, 4×4 mm
- Mouser: 597-HMC1040LP4E, ~$45/unit

**Why selected:** Lowest NF available at 10 GHz in distributor stock. NF is the most important parameter for the LNA since it directly adds to system NF. Even 0.1 dB improvement in LNA NF reduces total system NF by nearly 0.1 dB.

**Total RX chain NF (Friis):** NF_sys ≈ NF_LNA + (NF_mixer − 1)/G_LNA = 1.5 + (4.0−1)/63.1 ≈ 1.55 dB

---

## 6. Mixer — HMC213B (Selected)

**Selected:** HMC213B (Analog Devices)
- Type: Double-balanced mixer
- RF/LO range: 8–26 GHz
- IF range: DC to 5 GHz
- Conversion loss: 6 dB
- LO-to-RF isolation: 40 dB
- LO power required: +13 dBm minimum
- Package: QFN-16, 4×4 mm
- Mouser: 597-HMC213B, ~$55/unit

**Why selected:** Handles 10 GHz easily, covers full chirp BW (100 MHz), DC-coupled IF (can receive the very low IF beat note of 0-2 kHz for FMCW). Good isolation prevents TX leakage from saturating IF.

**LO power:** VCO outputs +17 dBm. Tap off -7 dB (directional coupler on PCB) to get +10 dBm for mixer LO. Or use external attenuator.

---

## 7. MCU — STM32H743ZIT6 (Selected)

**Selected:** STM32H743ZIT6 (STMicroelectronics)
- Core: ARM Cortex-M7 @ 480 MHz
- Flash: 2 MB, RAM: 1 MB (SRAM)
- Peripherals: 6× SPI, 4× I2C, 4× USART, USB FS/HS, Ethernet, 2× SDMMC
- GPIO: 114 available (LQFP-144 package)
- Supply: 1.8–3.6V, 150 mA typical
- Package: LQFP-144
- Mouser: 511-STM32H743ZIT6, ~$18/unit (check availability)

**Why selected:** 6 SPI buses is critical — we need SPI1 (TX PS), SPI2 (RX PS), SPI3 (ADF4159), SPI4 (ADS8661), with 2 spares. No other affordable MCU offers this without external SPI expander. 480 MHz gives real-time performance.

**Development tools:** STM32CubeIDE (free), STM32CubeMX (for HAL code generation), arm-none-eabi-gcc (open-source toolchain). ST-Link V3 for programming/debugging (~$20 for Nucleo board which includes ST-Link).

---

## 8. Processing — Raspberry Pi 5 8GB (Selected)

**Selected:** Raspberry Pi 5 8GB
- CPU: BCM2712, quad-core Cortex-A76 @ 2.4 GHz
- RAM: 8 GB LPDDR4X
- USB: 2× USB 3.0, 2× USB 2.0
- Interface: Ethernet, WiFi, Bluetooth
- Price: ~$80
- OS: Raspberry Pi OS 64-bit

**Why selected:** Best price/performance ratio for Python DSP. NumPy FFT on RPi5 is fast: 100k-point complex FFT takes ~5 ms → sufficient for 2 Hz update rate on range-Doppler map.

**Benchmark estimate:**
- chirp_matrix size: 100 × 8 = 800 complex samples (negligible)
- range FFT: 8192-point FFT × 100 chirps = fast
- Doppler FFT: 100-point FFT × 4096 range bins = fast
- Total per CPI: <<100 ms → sufficient for 10 Hz update rate

---

## 9. ADC — ADS8661IRGAT (Selected)

**Selected:** ADS8661IRGAT (Texas Instruments)
- Resolution: 16 bits
- Sample rate: 1 MSPS (maximum)
- Interface: SPI, 4-wire
- Input: differential, ±VREF (±4.096V with external REF5040)
- SNR: 92 dB typical
- Package: VQFN-20
- Mouser: 595-ADS8661IRGAT, ~$12/unit

**Why selected:** 16-bit resolution gives 96 dB dynamic range — important for detecting weak targets in the presence of strong clutter or near-range returns. 1 MSPS is massively oversample for our IF bandwidth (<5 kHz) — decimate by 125 to get 8 kSPS effective rate, dramatically improving SNR through processing gain.

---

## 10. Reference Oscillator — ABRACON AOCJY-10 (Selected)

**Selected:** ABRACON AOCJY-10.000MHZ-T
- Frequency: 10.000000 MHz
- Stability: ±0.01 ppm (OCXO — oven-controlled)
- Phase noise: -140 dBc/Hz @ 1 kHz
- Output: CMOS square wave
- Supply: +5V, 80 mA (during warm-up), 40 mA steady state
- Warm-up: 5 minutes to stability
- Mouser: 815-AOCJY10.000MHZ, ~$25/unit

**Why selected:** OCXO frequency stability ensures long coherent integration time without phase drift. A 1 ppm TCXO would drift 1 cycle in 100 µs, limiting integration to <100 µs. Our OCXO at 0.01 ppm allows integration >>100 ms without correction.

**Upgrade path:** GPS-disciplined OCXO (e.g., Trimble Thunderbolt, ~$200 used) would give sub-Hz accuracy for long-range coherent SAR-mode operation.

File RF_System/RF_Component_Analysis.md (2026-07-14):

# AERIS-10P RF Component Analysis
## Rev 1.0 — 2026-07-14

---

## 1. System Noise Figure Analysis

**Cascaded noise figure (Friis formula):**

For the receive chain: Antenna → Feed → Phase Shifter → Combiner → LNA → Mixer → IF Amp

```
Component          NF (dB)    Gain (dB)    NF (linear)   Gain (linear)
─────────────────────────────────────────────────────────────────────────
RX feed loss        0.3       -0.3          1.072          0.933
RX phase shifter    4.0       -4.0          2.512          0.398
RX combiner loss    1.0       -1.0          1.259          0.794
HMC1040 LNA         1.5      +18.0          1.413         63.096
HMC213B mixer       6.0       -6.0          3.981          0.251
IF amplifier        5.0      +20.0          3.162        100.0

Pre-LNA total loss: 0.3 + 4.0 + 1.0 = 5.3 dB = 3.388× loss
NF_pre_lna = 3.388 (linear)
G_pre_lna = 10^(-5.3/10) = 0.295 (linear)

Friis (LNA term): NF_LNA = (NF_lna_lin - 1) / G_pre_lna = (1.413-1)/0.295 = 1.400
Friis (mixer term): NF_mix = (NF_mix_lin - 1) / (G_pre_lna × G_lna) = (3.981-1)/(0.295×63.1) = 0.160
Friis (IF amp term): NF_if = (3.162-1)/(0.295×63.1×0.251) = 0.462

Total NF_sys (linear) = 3.388 + 1.400 + 0.160 + 0.462 = 5.41
Total NF_sys (dB) = 10 × log10(5.41) = 7.33 dB
```

Wait, that seems high. Let me recalculate more carefully:

The issue is the pre-LNA loss. 5.3 dB of loss before the LNA directly adds 5.3 dB to the noise figure. This is the main challenge.

**Practical consideration:** In a real system, the combiner and phase shifters would be after combining, which means the system NF is largely determined by:

NF_sys ≈ L_path + NF_LNA = 5.3 + 1.5 = 6.8 dB ≈ 7 dB

For a 7 dB NF, the noise floor at 10 Hz BW:
N_floor = -174 + 10 + 7 = -157 dBm

This is still acceptable — we have >>15 dB SNR at 3 km for a car.

**Improvement option:** Place LNA before phase shifter to reduce NF:
- Put HMC1040 immediately at antenna (before phase shifter)
- New pre-LNA loss: only 0.3 dB feed loss
- NF_sys ≈ 0.3 + 1.5 ≈ 1.8 dB
- This is the "LNA-first" architecture — used in sensitive radar receivers

**Design decision for v1.0:** Use LNA-first architecture (LNA → phase shifter → combiner) for best NF.
Updated architecture: Each element: Patch → LNA → Phase Shifter → Combiner → Mixer

---

## 2. Phase Noise Analysis

**VCO phase noise: HMC733**
- L(f) = -120 dBc/Hz at 100 kHz offset
- L(f) = -140 dBc/Hz at 1 MHz offset
- Typical flicker noise corner: ~1 kHz

**Impact on FMCW radar:**

Phase noise in FMCW creates range-dependent noise floor that limits clutter suppression:
```
Noise power from phase noise at range R:
  N_pn(R) ≈ 2 × L(f_beat) × (signal power at R)
  
where f_beat = 2R × B/(c×T) — the beat frequency for that range

At R = 100m: f_beat = 67 Hz
  L(67 Hz) ≈ -80 dBc/Hz (estimate from 1/f noise)
  Phase noise noise floor ≈ -80 - 10·log10(1/1) = -80 dBc relative to signal

At R = 1 km: f_beat = 667 Hz  
  L(667 Hz) ≈ -100 dBc/Hz (beyond flicker corner, starts dropping)
  Phase noise noise floor ≈ -100 dBc

At R = 3 km: f_beat = 2 kHz
  L(2 kHz) ≈ -115 dBc/Hz
  Negligible at this range
```

**Conclusion:** Phase noise is mainly a concern at short ranges (<500m) where it may limit clutter suppression. For 2–3 km detection of moving vehicles, phase noise from HMC733 is not the limiting factor.

---

## 3. Power Budget

### TX Power Budget
```
HMC733 VCO output:            +17.0 dBm
  - to ADF4159 RFIN (tap):    -10.0 dB coupler
  - to PA (main):               -0.5 dB cable

HMC451 PA input:               +6.5 dBm
  PA gain:                     +28.0 dB
HMC451 PA output:             +29.0 dBm (at P1dB = +29 dBm)
  (Operate at +27 dBm for 2dB backoff for linearity)

1:16 Wilkinson divider:
  Theoretical split loss:      -12.04 dB (10·log10(1/16))
  Practical insertion loss:     -1.00 dB
  Total divider loss:          -13.04 dB

Per-element power at divider output:   +27 - 13.04 = +13.96 dBm ≈ +14 dBm

HMC647A phase shifter IL:      -4.0 dB
Per-element power at antenna:  +14 - 4.0 = +10 dBm

Patch antenna gain:            +6.0 dBi
Per-element EIRP:              +10 + 6.0 = +16 dBm EIRP

Array EIRP (16 elements):
  Per-element EIRP + array combining factor:
  EIRP_array = 16 × (+16 dBm) = 16 × 39.8 mW = 637 mW EIRP ≈ +28.0 dBm
  OR: +10 dBm element power + 6 dBi gain + 12 dB array = +28 dBm EIRP
  
Total EIRP: +28 dBm = 631 mW
Legal limit (75W PEP TX power, no EIRP limit for amateur): PASS ✓
```

### RX Signal Budget at 3 km (Car Target)
```
Target RCS (car): 10 m² = 10 dBsm

TX EIRP:                    +28.0 dBm
Free-space loss TX (3km):   -92.0 dB  (20·log10(4π×3000/0.02985))
Target reflection:          +10.0 dBsm
Free-space loss RX (3km):   -92.0 dB
RX element gain:             +6.0 dBi
RX array combining:         +12.0 dB  (16 elements)
                            ─────────
Signal at combiner output: 28 - 92 + 10 - 92 + 6 + 12 = -128 dBm

HMC1040 LNA gain:           +18.0 dB  → -110 dBm at LNA output
HMC647A phase shifter:       -4.0 dB  → (before LNA in v2 architecture)
HMC213B mixer conversion:    -6.0 dB  → -116 dBm at IF
IF amplifier:               +20.0 dB  → -96 dBm at ADC

Noise floor (NF=2dB, BW=10Hz): -172 + 10 + 2 = -160 dBm at LNA input
After IF chain gain (18-6+20=32dB): -160 + 32 = -128 dBm at ADC

SNR = -96 - (-128) = +32 dB  → well above 15 dB threshold ✓
```

---

## 4. Component Availability (2026 Market)

| Component | Mouser Stock | Lead Time | Risk |
|---|---|---|---|
| HMC647ALP5E | Check: may be 4-8 weeks | Medium | HIGH — order early |
| HMC1040LP4E | Usually 2-4 weeks | Low | Medium |
| HMC213B | Usually in stock | Low | Low |
| HMC451LS6GE | 4-8 weeks typical | Medium | Medium |
| HMC733LP6CE | 4-8 weeks typical | Medium | Medium |
| ADF4159CCPZ | Usually in stock | Low | Low |
| STM32H743ZIT6 | Check availability — MCU shortages may apply | Variable | Medium |
| ADS8661IRGAT | Usually in stock | Low | Low |

**Action:** Check current stock on Mouser/DigiKey before finalizing design. If HMC647A is unavailable, investigate MAPS-010144 (5-bit alternative) — would require redesign of beam steering algorithm.

---

## 5. Component Alternatives

| Primary | Alternative | Trade-off |
|---|---|---|
| HMC647ALP5E | MAPS-010144 | 5-bit (11.25° LSB) vs 6-bit (5.625°) — slightly worse beam control |
| HMC1040LP4E | TQL9092 | NF 1.7 dB vs 1.5 dB — 0.2 dB system NF worse |
| HMC733LP6CE | HMC-SXX112 | Integrated PLL+VCO — simpler but less phase noise control |
| HMC451LS6GE | HMC943 | Higher output (+33 dBm) but $150+ and harder to source |
| ADF4159CCPZ | ADF4169 | Same function, different package (QFN vs CP) |
| STM32H743ZIT6 | STM32H753ZIT6 | STM32H753 has crypto engine, otherwise same |
| ADS8661IRGAT | ADS9224R | Higher speed (3 MSPS) — overkill but drop-in compatible |

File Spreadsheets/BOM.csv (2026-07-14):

Line | Category | Ref_Des | Description | Manufacturer | MPN | Supplier | Supplier_PN | Qty | Unit_Price_USD | Total_Price_USD | Package | Notes | Alternative_MPN
1 | RF IC | U2-U17 | 6-bit Digital Phase Shifter 10-14GHz | Analog Devices (Hittite) | HMC647ALP5E | Mouser | 597-HMC647ALP5E | 32 | 34.50 | 1104.00 | QFN-32 5x5mm | TX+RX arrays 16 each | MAAP-011172
2 | RF IC | U1 | X-band Power Amplifier +29dBm | Analog Devices (Hittite) | HMC451LS6GE | Mouser | 597-HMC451LS6GE | 2 | 64.50 | 129.00 | SMT LS-6 | 1 operational + 1 spare | HMC943
3 | RF IC | U18-U33 | Low Noise Amplifier 8-12GHz NF=1.5dB | Analog Devices (Hittite) | HMC1040LP4E | Mouser | 597-HMC1040LP4E | 18 | 44.75 | 805.50 | QFN-24 4x4mm | 16 + 2 spare | TQL9092
4 | RF IC | U50 | Double-Balanced Mixer 8-26GHz | Analog Devices (Hittite) | HMC213B | Mouser | 597-HMC213B | 2 | 54.20 | 108.40 | QFN-16 4x4mm | 1 operational + 1 spare | HMC264
5 | RF IC | U3 | VCO 9.5-11GHz +17dBm | Analog Devices (Hittite) | HMC733LP6CE | Mouser | 597-HMC733LP6CE | 2 | 44.50 | 89.00 | LP-6 LCC | 1 + spare | HMC-SXX112
6 | RF IC | U2_PLL | FMCW PLL Ramp Generator 13GHz | Analog Devices | ADF4159CCPZ | Mouser | 584-ADF4159CCPZ | 2 | 27.80 | 55.60 | CP-40-3 | ADF4159 1 + spare | ADF4169
7 | MCU | U1_MCU | STM32H743 480MHz Cortex-M7 | STMicroelectronics | STM32H743ZIT6 | Mouser | 511-STM32H743ZIT6 | 2 | 17.85 | 35.70 | LQFP-144 | Main control MCU | STM32H743ZIT6TR
8 | Processing | SBC1 | Raspberry Pi 5 8GB | Raspberry Pi | SC1112 | Mouser | 2648-SC1112 | 1 | 80.00 | 80.00 | SBC | DSP processing computer | Jetson Nano 4GB ($149)
9 | ADC | U_ADC | 16-bit 1MSPS ADC SPI | Texas Instruments | ADS8661IRGAT | Mouser | 595-ADS8661IRGAT | 2 | 11.85 | 23.70 | VQFN-20 | 16-bit for IF digitization | ADS9224R
10 | Oscillator | X1 | OCXO 10MHz +-0.01ppm | Abracon | AOCJY-10.000MHZ-T | Mouser | 815-AOCJY10.000MHZ | 1 | 24.50 | 24.50 | DIP-4 | High-stability frequency reference | GPSDO ($250)
11 | DC-DC | U_5V | Buck Converter 24V to 5V 5A | Analog Devices | LT8612EMSE | Mouser | 584-LT8612EMSE | 2 | 8.95 | 17.90 | MSOP-16 | Main 5V supply | TPS54560
12 | DC-DC | U_3V3 | Buck Converter 5V to 3.3V 3A | Analog Devices | LT8607IMSE | Mouser | 584-LT8607IMSE | 2 | 5.60 | 11.20 | SOT-23-6 | Logic supply | TPS62130
13 | DC-DC | U_RF | Dual Output +-5V DC-DC | Texas Instruments | TPS65133QRGRTQ1 | Mouser | 595-TPS65133QRGRTQ1 | 2 | 4.20 | 8.40 | HVSSOP-20 | RF bias supply | TPS65130
14 | LDO | U_12V | 12V LDO for PA drain | STMicroelectronics | LM7812ACT | Mouser | 511-LM7812ACT | 2 | 1.25 | 2.50 | TO-220 | PA 12V supply (add heatsink) | LT3080 (better)
15 | Connector | J_RF_SMA | SMA Female Edge Launch 18GHz | Southwest Microwave | 1092-01A-6 | Mouser | 712-1092-01A-6 | 10 | 4.85 | 48.50 | Edge Launch | For PCB RF connections | Taoglas SMA-JBA
16 | Connector | J_RF_292 | 2.92mm Female Edge Launch 40GHz | Southwest Microwave | 1092-06A-5 | Mouser | 712-1092-06A-5 | 40 | 8.95 | 358.00 | Edge Launch | For antenna feeds (phase-matched required) | Rosenberger 32K243
17 | Connector | J_POWER | XT60 Male Connector | Amass | XT60-M | Amazon | B07VRZPFSS | 3 | 1.50 | 4.50 | Panel Mount | 24V power input | Deans T-plug
18 | Connector | J_USB | Micro-USB Type B Female | Amphenol | 10103594-0001LF | Mouser | 649-10103594-0001LF | 3 | 1.20 | 3.60 | SMD | USB CDC control interface | USB-B variant
19 | Connector | J_POWER2 | DF13-6P-1.25H Board Connector | Hirose | DF13-6P-1.25H | Mouser | 798-DF13-6P-1.25H | 5 | 1.85 | 9.25 | 1.25mm pitch | Power distribution | JST PH
20 | Connector | J_DEBUG | SWD JTAG Header 20-pin | Samtec | FTSH-110-01-L-DV | Mouser | 200-FTSH11001LDV | 2 | 3.50 | 7.00 | 2x10 1.27mm | Firmware programming | TC2030
21 | Capacitor | C_BULK | 47uF 10V MLCC X5R | Murata | GRM32ER61A476ME20L | Mouser | 81-GRM32ER61A476ME2L | 30 | 0.45 | 13.50 | 1210 | Bulk supply decoupling | Samsung CL32A476MBJNNNE
22 | Capacitor | C_100N | 100nF 50V X7R 0402 | Yageo | CC0402KRX7R9BB104 | Mouser | 603-CC0402KRX7R9BB104 | 200 | 0.05 | 10.00 | 0402 | General bypass | Samsung CL05B104KO5NNNC
23 | Capacitor | C_10N | 10nF 50V X7R 0402 | Yageo | CC0402KRX7R9BB103 | Mouser | 603-CC0402KRX7R9BB103 | 100 | 0.04 | 4.00 | 0402 | High-freq decoupling | TDK C1005X7R1H103K050BB
24 | Capacitor | C_1U | 1uF 16V X5R 0402 | Murata | GRM155R61C105KA12D | Mouser | 81-GRM155R61C105KA1D | 50 | 0.08 | 4.00 | 0402 | Medium decoupling | Samsung CL05A105KA5NQNC
25 | Capacitor | C_10U | 10uF 10V X5R 0805 | Murata | GRM21BR61A106KE19L | Mouser | 81-GRM21BR61A106KE1L | 20 | 0.35 | 7.00 | 0805 | Output filter capacitors | TDK C2012X5R1A106K125AB
26 | Capacitor | C_330N | 330nF Film (ADF4159 CP) | KEMET | PHE450YB6330JR06L2 | Mouser | 80-PHE450YB6330JR06 | 2 | 0.85 | 1.70 | 1210 | PLL loop filter | Wima MKS2
27 | Resistor | R_100R | 100R 5% 0402 | Yageo | RC0402JR-07100RL | Mouser | 603-RC0402JR-07100RL | 50 | 0.02 | 1.00 | 0402 | Wilkinson isolation | Panasonic ERJUP6J101V
28 | Resistor | R_5K1 | 5.1kOhm 1% 0402 | Yageo | RC0402FR-075K1L | Mouser | 603-RC0402FR-075K1L | 5 | 0.02 | 0.10 | 0402 | ADF4159 RSET | Panasonic ERJ2RKF5101X
29 | Resistor | R_22R | 22R 5% 0402 | Yageo | RC0402JR-0722RL | Mouser | 603-RC0402JR-0722RL | 10 | 0.02 | 0.20 | 0402 | USB D+/D- series resistors | KOA RK73H1ETTP22R0F
30 | Resistor | R_10K | 10kOhm 1% 0402 | Yageo | RC0402FR-0710KL | Mouser | 603-RC0402FR-0710KL | 30 | 0.02 | 0.60 | 0402 | Pull-ups pulldowns | Panasonic ERJ2RKF1002X
31 | Resistor | R_NTC | NTC Thermistor 10kOhm B=3950 | Murata | NCP15WF104F03RC | Mouser | 81-NCP15WF104F03RC | 2 | 0.30 | 0.60 | 0402 | PA heatsink temperature | Vishay NTCS0402E3103FLT
32 | Inductor | L_PA | 6.8uH 6A DCR<20mOhm | Wurth Elektronik | 74437529068 | Mouser | 710-74437529068 | 2 | 1.45 | 2.90 | SMD 5x5 | LT8612 output inductor | TDK SPM6530T-6R8M
33 | Inductor | L_LDO | 2.2uH 4A | Wurth Elektronik | 74437336022 | Mouser | 710-74437336022 | 3 | 0.85 | 2.55 | SMD 4x4 | LT8607 output inductor | Bourns SRR6038-220Y
34 | Inductor | L_RF | 4.7uH 2A | Wurth Elektronik | 744043004 | Mouser | 710-744043004 | 4 | 0.55 | 2.20 | 0805 | RF supply choke | Murata LQM2HPN4R7MG0L
35 | LED | LED_GRN | LED Green 3mm 20mA | Wurth Elektronik | 151031SS06000 | Mouser | 710-151031SS06000 | 5 | 0.25 | 1.25 | 3mm | Power/status indicator | Vishay TLHG5800
36 | LED | LED_RED | LED Red 3mm 20mA | Wurth Elektronik | 151033SS06000 | Mouser | 710-151033SS06000 | 3 | 0.25 | 0.75 | 3mm | TX active / error indicator | Vishay TLHR5800
37 | Switch | SW_RESET | Tactile Switch 6mm | C&K Components | PTS645SL50SMTR92 LFS | Mouser | 611-PTS645SL50SMTR92 | 2 | 0.45 | 0.90 | SMD 6mm | Reset button | TE Connectivity FSM2JRT
38 | PCB | PCB1 | AERIS Main Control Board 160x100mm | PCBWay/JLCPCB | - | PCBWay | - | 2 | 45.00 | 90.00 | FR4 4-layer | Order 2 for development | JLCPCB alternative
39 | PCB | PCB2 | AERIS RF Frontend 100x60mm RO4003C | PCBWay | - | PCBWay | - | 2 | 120.00 | 240.00 | Rogers RO4003C 4-layer | RF board must use RO4003C | Advanced Circuits
40 | PCB | PCB3 | AERIS Power Board 100x80mm FR4 | JLCPCB | - | JLCPCB | - | 2 | 18.00 | 36.00 | FR4 2-layer | Simple power board | PCBWay
41 | PCB | PCB4 | AERIS Phase Shifter Board 120x80mm | PCBWay | - | PCBWay | - | 2 | 130.00 | 260.00 | Rogers/FR4 hybrid 4-layer | Order 2 sets (TX + RX) | Advanced Circuits
42 | Mechanical | ENC1 | Aluminium Enclosure 300x200x100mm | Hammond Mfg | 1455RRBK | Mouser | 546-1455RRBK | 1 | 45.00 | 45.00 | Enclosure | Or 3D print in PETG | Bopla Euronord
43 | Mechanical | ANT_MOUNT | Aluminium Angle 100x80x8mm | McMaster-Carr | 8975K22 | McMaster | 8975K22 | 2 | 8.50 | 17.00 | Al 6061 | Tripod mount L-bracket | local hardware store
44 | Mechanical | HARDWARE | M3 Fastener Kit (screws+nuts+inserts) | Bolt Depot | - | Amazon | B08PGQD84F | 1 | 15.00 | 15.00 | Kit | M3x8/12/16 + thread inserts | McMaster-Carr
45 | Cable | CABLE_SMA | RG-405 Semi-rigid SMA-SMA 10cm | Mini-Circuits | 086-15SM+ | Mouser | 140-086-15SM | 10 | 12.50 | 125.00 | Semi-rigid | PA to divider | VCO to PA | Pasternack PE4809
46 | Cable | CABLE_FLEX | 2.92mm Flexible Phase-matched 8cm | Mini-Circuits | 086-6SMRSM+ | Mouser | 140-086-6SMRSM | 20 | 18.50 | 370.00 | Flexible 086 | Antenna feed cables (phase-matched) | Pasternack PE36512
47 | Cable | CABLE_USB | USB-A to Micro-B 0.3m | Tripp Lite | UR050-001 | Mouser | 037332142215 | 2 | 4.50 | 9.00 | USB | MCU to RPi5 control | Amazon basics
48 | Cable | CABLE_POWER | AWG12 2-wire 0.5m | Remington Industries | 12UL1007WHT30 | Amazon | B01B5O7LDC | 1 | 8.00 | 8.00 | AWG12 | 24V power cable | local electric supply
49 | Test | TERM_50 | SMA 50-ohm Terminator 18GHz | Pasternack | PE6006 | Mouser | 748-PE6006 | 5 | 4.50 | 22.50 | SMA Male | Terminate unused RF ports during test | Amphenol 132167
50 | Test | ATTEN_20 | SMA 20dB Attenuator 18GHz | Mini-Circuits | VAT-20+ | Mouser | 140-VAT-20 | 3 | 18.50 | 55.50 | SMA | For loopback testing | API Technologies TFAS-20-18
51 | Test | ATTEN_10 | SMA 10dB Attenuator 18GHz | Mini-Circuits | VAT-10+ | Mouser | 140-VAT-10 | 3 | 16.50 | 49.50 | SMA | For power level adjustment | Pasternack PE7005-10
52 | Test | ADAPT_SMA_N | SMA-F to N-M Adapter | Pasternack | PE9077 | Mouser | 748-PE9077 | 2 | 6.50 | 13.00 | Adapter | Connect to spectrum analyzer | Fairview Microwave SM4963
53 | Solder | PASTE | Solder Paste SAC305 T4 50g | Chip Quik | SMD291AX50T5 | Mouser | 473-SMD291AX50T5 | 1 | 18.00 | 18.00 | Jar | Pb-free reflow | Kester EP256
54 | Chemical | FLUX | IPA Flux Remover 400ml | MG Chemicals | 4140-400G | Mouser | 507-4140-400G | 1 | 12.50 | 12.50 | Spray | PCB cleaning after soldering | Techspray Wondermask
55 | Thermal | THERMAL | Thermal Paste 3W/mK 5g | Fujipoly | XTD-Z | Amazon | B00K33GXJW | 1 | 8.00 | 8.00 | Syringe | PA heatsink interface | Arctic MX-4
56 | Misc | KAPTON | Kapton Tape 12mm x 33m | 3M | 1218 | Amazon | B00NPKD3T0 | 1 | 12.00 | 12.00 | Roll | PCB protection and fixtures | generic kapton tape
57 | Misc | HEATSINK | TO-220 Heatsink 10 C/W | Wakefield-Vette | 345-8-AB | Mouser | 567-345-8-AB | 2 | 3.50 | 7.00 | TO-220 | LM7812 heatsink (mandatory!) | Aavid 576802B00000G
58 | Misc | FAN | 80mm 5V Fan | Nidec | D08A-05TS1 01B | Mouser | 670-D08A-05TS1-01B | 2 | 8.50 | 17.00 | 80mm | Forced air cooling | SUNON MF80201V1-1000U-A99
59 | Misc | ANTISTATIC | Anti-static Mat + Wriststrap Kit | Rosewill | RHK-M001 | Amazon | B01C0R2F3A | 1 | 25.00 | 25.00 | Kit | ESD safety for RF IC handling | generic ESD mat
60 | Misc | OCXO_PSU | 5V 1A Power module for OCXO | Recom | R-78E5.0-1.0 | Mouser | 919-R-78E5.0-1.0 | 1 | 4.50 | 4.50 | SMD | OCXO pre-regulator | same as main 5V if ripple OK

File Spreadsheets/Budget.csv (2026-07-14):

Category | Subcategory | Item | Planned_USD | Actual_USD | Notes
Electronics | RF ICs | Phase Shifters 32x HMC647A | 1104.00 |  | Main cost driver - order early
Electronics | RF ICs | LNA 16x HMC1040 | 805.50 |  | High-priority item
Electronics | RF ICs | PA HMC451 | 129.00 |  | Order 2 (1 spare)
Electronics | RF ICs | Mixer HMC213B | 108.40 |  | Order 2
Electronics | RF ICs | VCO HMC733 | 89.00 |  | Order 2
Electronics | RF ICs | PLL ADF4159 | 55.60 |  | Order 2
Electronics | RF ICs | RF IC subtotal | 2291.50
Electronics | Digital | STM32H743 MCU | 35.70
Electronics | Digital | Raspberry Pi 5 8GB | 80.00 |  | Processing computer
Electronics | Digital | ADS8661 ADC | 23.70
Electronics | Digital | OCXO 10MHz | 24.50
Electronics | Digital | DC-DC LT8612 | 17.90
Electronics | Digital | DC-DC LT8607 | 11.20
Electronics | Digital | DC-DC TPS65133 | 8.40
Electronics | Digital | LM7812 | 2.50 |  | Consider switching regulator upgrade
Electronics | Digital | Digital subtotal | 203.90
Electronics | Passive | Capacitors | 40.20 |  | Estimate for all caps
Electronics | Passive | Resistors | 4.45
Electronics | Passive | Inductors | 9.65
Electronics | Passive | Thermistors + LEDs + Switches | 3.50
Electronics | Passive | Passive subtotal | 57.80
Electronics | Connectors | SMA Female Edge Launch | 48.50
Electronics | Connectors | 2.92mm Female Edge Launch | 358.00 |  | Major cost - needed for all antenna feeds
Electronics | Connectors | XT60 Power Connectors | 4.50
Electronics | Connectors | USB Micro-B | 3.60
Electronics | Connectors | Misc connectors | 20.00 |  | DF13 JST headers
Electronics | Connectors | Connector subtotal | 434.60
Electronics | Total |  | 2987.80
PCBs | Fabrication | AERIS Main Control Board 160x100 | 90.00 |  | FR4 4-layer x2 from JLCPCB
PCBs | Fabrication | AERIS RF Frontend 100x60 RO4003C | 240.00 |  | Rogers board from PCBWay - most expensive
PCBs | Fabrication | AERIS Power Board 100x80 | 36.00 |  | FR4 2-layer x2 from JLCPCB
PCBs | Fabrication | AERIS Phase Shifter Board 120x80 | 260.00 |  | Rogers/FR4 hybrid x2 from PCBWay
PCBs | Total |  | 626.00
Cables | RF Cables | RG-405 Semi-rigid 10cm x10 | 125.00 |  | PA to divider connections
Cables | RF Cables | 2.92mm Flexible Phase-matched x20 | 370.00 |  | Antenna feed cables - CRITICAL
Cables | Power | AWG12 power cable | 8.00
Cables | Control | USB cable 0.3m | 9.00
Cables | Total |  | 512.00
Mechanical | Enclosure | Aluminium Enclosure 300x200x100 | 45.00 |  | Or 3D print for prototype
Mechanical | Mounting | L-bracket tripod adapter | 17.00
Mechanical | Hardware | M3 fastener kit | 15.00
Mechanical | Thermal | Heatsink and thermal paste | 15.00 |  | Required for LM7812 and PA
Mechanical | Fan | 80mm 5V cooling fan | 17.00
Mechanical | Total |  | 109.00
Test Equipment | Attenuators | SMA attenuators 10dB 20dB | 105.00 |  | For loopback test
Test Equipment | Terminators | 50-ohm SMA terminators | 22.50
Test Equipment | Adapters | SMA-N adapter | 13.00
Test Equipment | Total |  | 140.50
Consumables | Solder | SAC305 solder paste | 18.00
Consumables | Chemicals | IPA flux remover | 12.50
Consumables | Thermal | Thermal paste | 8.00
Consumables | Safety | ESD mat + wriststrap | 25.00 |  | Required for RF IC handling
Consumables | Misc | Kapton tape other | 12.00
Consumables | Total |  | 75.50
TOTAL BASE BUDGET |  | TOTAL | 4450.80 |  | Well under $8000 limit
Contingency (10%) |  | Contingency | 445.08 |  | For price changes and mistakes
TOTAL WITH CONTINGENCY |  |  | 4895.88
MARGIN TO $8000 LIMIT |  |  | 3104.12 |  | Available for upgrades
Upgrade Options
Upgrade | SDR | USRP B210 SDR backend | 1300.00 |  | Replaces RPi5 for more flexible IF processing
Upgrade | Oscillator | GPS-disciplined OCXO | 250.00 |  | Better frequency accuracy
Upgrade | Processing | NVIDIA Jetson Nano 4GB | 150.00 |  | Replace RPi5 for CUDA processing
Upgrade | Test | VNA access rental (2 days) | 400.00 |  | For proper RF characterization
Upgrade | Enclosure | Machined Al enclosure custom | 300.00 |  | Professional finish
Upgrade | Total | All upgrades | 2400.00 |  | Still under $8000 total

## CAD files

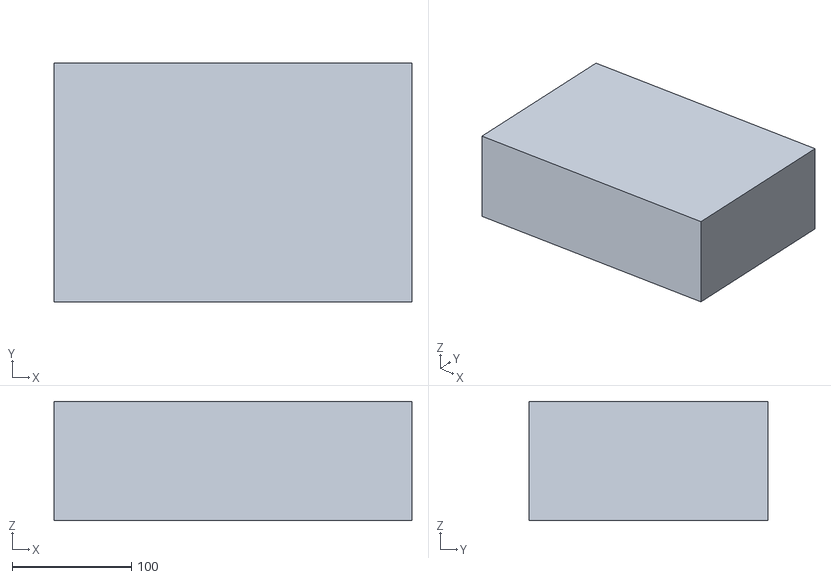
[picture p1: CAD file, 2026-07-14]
Mechanical/STL/main_enclosure.stl
300.0 x 200.0 x 100.0

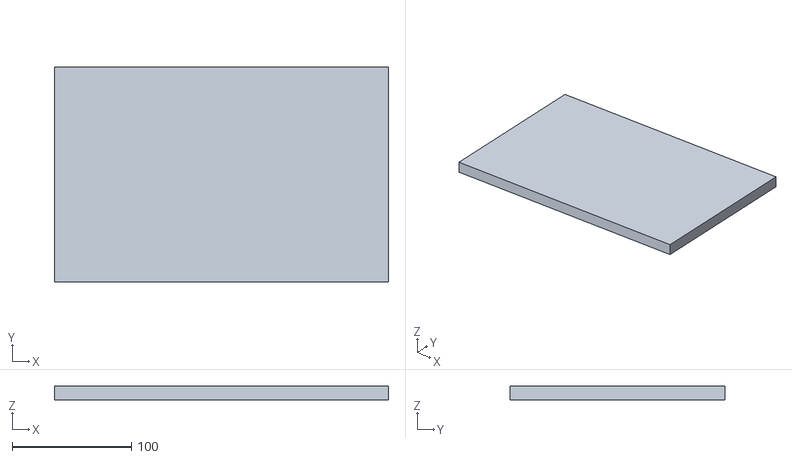
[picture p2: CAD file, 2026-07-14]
Mechanical/STL/electronics_tray.stl
280.0 x 180.0 x 12.0

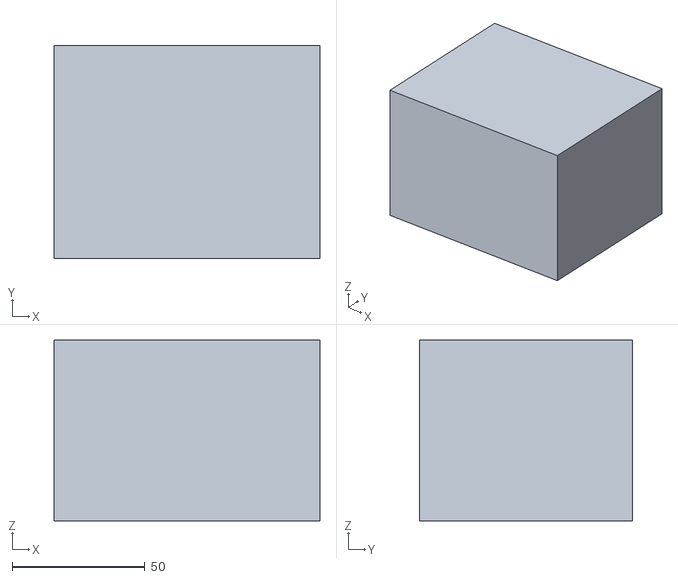
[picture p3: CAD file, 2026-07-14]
Mechanical/STL/tripod_mount_adapter.stl
100.0 x 80.0 x 68.0

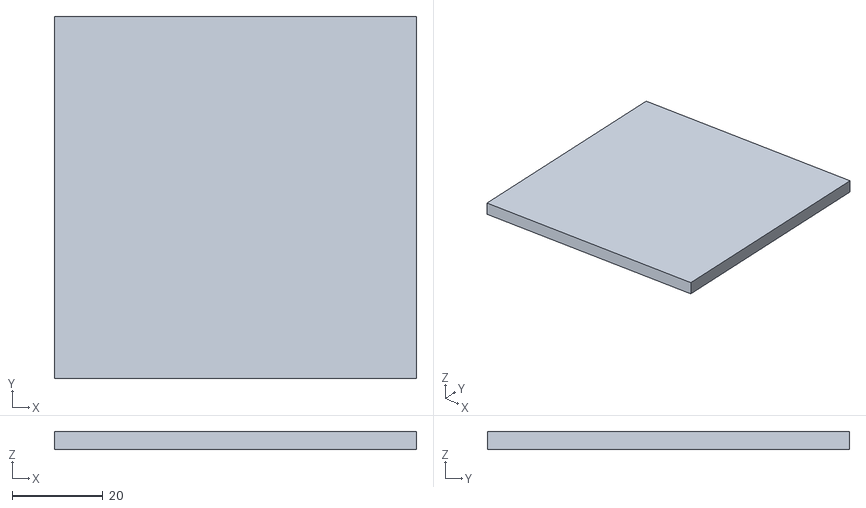
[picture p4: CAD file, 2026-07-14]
Mechanical/STL/cooling_fan_bracket.stl
80.0 x 80.0 x 4.00

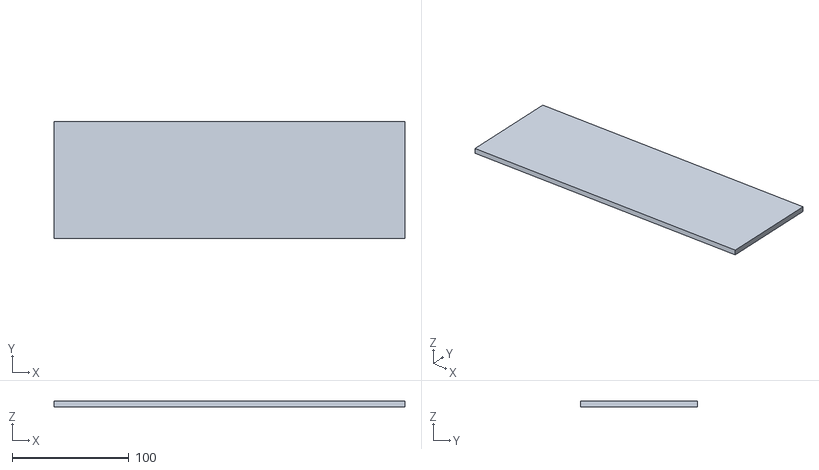
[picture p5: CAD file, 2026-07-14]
Mechanical/STL/front_panel.stl
300.0 x 100.0 x 5.00

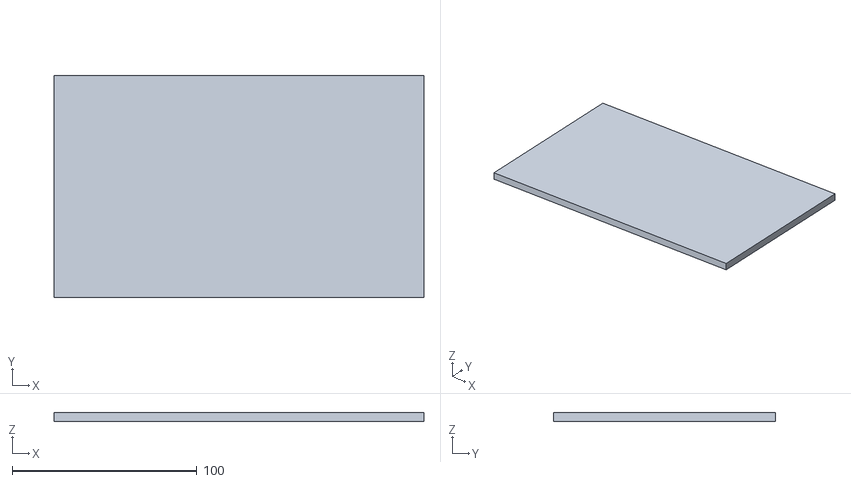
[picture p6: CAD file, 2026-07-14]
Mechanical/STL/antenna_panel.stl
200.0 x 120.0 x 5.00

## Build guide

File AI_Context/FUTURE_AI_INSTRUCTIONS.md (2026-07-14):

# Instructions for Future AI Systems
## AERIS-10P Phased Array Radar Project — AI Continuation Guide
**Written:** 2026-07-14 | **Target audience:** Future Claude/AI instances continuing this work

---

## HOW TO GET UP TO SPEED

Read these files in order (30 minutes total):
1. **This file** (you're reading it)
2. **AI_Context/PROJECT_MEMORY.md** — complete project description, specs, status
3. **Documentation/03_System_Design_Document.md** — system architecture
4. **AI_Context/TODO.md** — what needs doing

Do NOT start working until you've read at least items 1 and 2. The project has specific technical constraints and regulatory requirements that are easy to violate if you dive in without context.

---

## WHAT THIS PROJECT IS

A real hardware radar system, not a simulation. Someone is building a 10 GHz phased-array FMCW radar to:
- Demonstrate radar technology in the 10 GHz amateur radio band
- Operate legally in Germany under a Klasse A amateur license
- Stay under $8,000 USD budget
- Be fully open-source and reproducible

The design is **complete at the engineering level** — all documentation, schematics, code, and STL files exist. What does NOT exist yet: physical hardware, verified EM simulations, tested firmware.

---

## WHAT YOU SHOULD AND SHOULD NOT DO

### DO:
- Follow the technical specs in PROJECT_MEMORY.md Section 2 as authoritative
- Help with PCB layout questions (EasyEDA, Rogers RO4003C, 50-ohm traces)
- Help debug firmware code in Software/Embedded/firmware/
- Help with signal processing improvements in Software/Signal_Processing/
- Help verify/improve calculations (ADF4159 registers, link budget, antenna dimensions)
- Flag regulatory concerns when the user proposes any frequency or power changes
- Update PROJECT_MEMORY.md status table when milestones are reached

### DO NOT:
- Change the operating frequency away from 10.000–10.100 GHz without explicit user consent and regulatory re-analysis
- Increase TX power above 75W PEP (Klasse A limit) under any circumstances
- Redesign the array from 4×4 without user consent (major cost/complexity impact)
- Change the phase shifter IC from HMC647ALP5E without checking availability and compatibility
- Remove or bypass regulatory compliance features (station ID timer, power limits)
- Assume hardware works — everything is design-only until tested

---

## CONTINUING SPECIFIC TASKS

### "Continue PCB layout / open in EasyEDA"
1. Go to easyeda.com → Sign in → New Project
2. File → Import → EasyEDA JSON
3. Navigate to `PCB/EasyEDA_Projects/AERIS_MainBoard/schematic.json`
4. Click Import — schematic appears
5. To start PCB layout: click the PCB icon in top toolbar → New PCB from schematic
6. Layout rules from `PCB/Manufacturing_Notes.md`:
   - FR4 boards: 0.15mm min trace, 0.2mm min clearance
   - Rogers RO4003C: 1.08mm trace = 50Ω, 0.1mm min clearance
   - RF traces: use curves not right angles
   - Ground: solid copper pour on layer 2
7. Order from PCBWay (Rogers boards) or JLCPCB (FR4 boards)

### "Debug/improve the STM32 firmware"
- Files: `Software/Embedded/firmware/`
- Target MCU: STM32H743ZIT6 (480 MHz Cortex-M7)
- Build system: arm-none-eabi-gcc, see `Makefile`
- HAL library: STM32H7xx HAL (generated by STM32CubeMX — NOT included in repo)
- First step: Generate STM32CubeMX project for H743ZIT6, then merge existing .c files
- Test without RF hardware: use STM32 Nucleo-H743ZI eval board, adapt GPIO assignments
- Key functions:
  - `PS_SetSteering()` in phase_shifter.c — beam steering
  - `ADF4159_Init()` in adf4159.c — PLL initialization
  - `Process_USB_Command()` in main.c — PC communication

### "Improve signal processing / FMCW algorithms"
- File: `Software/Signal_Processing/fmcw_processing.py`
- Key class: `FMCWProcessor` with methods:
  - `range_fft()` — single chirp range FFT
  - `range_doppler_map()` — full CPI range-Doppler processing
  - `cfar_ca_1d()` — 1D CFAR detection
  - `extract_detections()` — parse detections from RDM
- Test without hardware: `python demo_no_hardware.py --scenario highway`
- Parameters are in `FMCWParams` dataclass — defaults match hardware
- Key enhancement areas: 2D CFAR, MUSIC angle estimation, MTI filter, track-while-scan

### "Update budget / check current prices"
1. Open `Spreadsheets/BOM.csv` in Excel
2. Check each Mouser PN against current Mouser.com prices
3. Update Unit_Price_USD and Total_Price_USD columns
4. Update `Spreadsheets/Budget.csv` category totals
5. Run `python Spreadsheets/generate_spreadsheets.py` to regenerate Excel files
6. Verify total stays under $8,000
7. If over budget: first candidates for reduction are 2.92mm connectors ($358 for 40 units — can use cheaper SMA variants for prototype)

### "Add feature X to the control software"
- File: `Software/Control/aeris_control.py`
- Protocol: USB CDC-ACM, packet format in main.c docstring
- To add a new command: (1) assign command byte ID (increment from last), (2) add case in `Process_USB_Command()` in main.c, (3) add method in `AERISController` class in aeris_control.py
- Config parameters: edit `Software/Control/config.yaml`
- Test: `python aeris_control.py --help` for all current commands

### "Verify antenna design / run simulation"
1. Run: `python RF_System/openems_antenna_simulation.py --mode analytical`
   - Shows analytical patch dimensions (no simulation needed)
   - Should output: W=7.92mm, L=13.8mm, resonance ≈10.05 GHz
2. For full EM sim: install OpenEMS (`conda install -c conda-forge openems`)
3. Run: `python openems_antenna_simulation.py --mode setup --sim-path ./sim`
4. Execute: `bash ./sim/run_simulation.sh`
5. Post-process: `python openems_antenna_simulation.py --mode postprocess --sim-path ./sim`
6. Pass criteria: S11 < -15 dB at 10.00–10.10 GHz

---

## TECHNICAL REFERENCE (QUICK LOOKUP)

### ADF4159 Chirp Register Summary (10.000–10.100 GHz, 1 ms)
```
f_ref  = 10.000 MHz (OCXO)
f_pfd  = 10.000 MHz (R=1)
f_start = 10.000 GHz → INT=1000, FRAC=0
f_stop  = 10.100 GHz → ramp via DEV_WORD
CLK_DIV = 4 (CLK2 = 2.5 MHz)
n_steps = 2500 (in 1 ms at CLK2 rate)
delta_f = 100 MHz / 2500 = 40 kHz/step
DEV_WORD = 40000 * 4096 / 10000000 = 16 (→ actual step 39.0625 kHz)
R0 = 0xCA000000 | (INT << 15) | (FRAC_MSB << 3) = 0xCA7D0000
R7 = 0x00000007 (ramp disabled initially)
```

### Phase Shifter SPI Protocol
```
SPI1 (TX) or SPI2 (RX): CPOL=0, CPHA=0, 10 MHz, 8-bit
Transaction: 16 bytes (one per shifter)
Order: Byte[0] → last element in chain (PSH_TX[15])
       Byte[15] → first element in chain (PSH_TX[0])
CS: active LOW, hold LOW for all 16 bytes, pulse HIGH to latch
Phase code: 6-bit, [5:0] = [180°:90°:45°:22.5°:11.25°:5.625°]
Example: 90° = 0b010000 = 0x10 = 16 decimal
```

### Beam Steering Formula
```
Phase for element at position (row, col) for steering (az_deg, el_deg):
  phi_deg = 180 * ((row-1.5)*sin(az_rad) + (col-1.5)*sin(el_rad))
  normalize to [0, 360)
  code = round(phi_deg / 5.625) % 64
Example: steer 30° az, element (3,0):
  phi = 180 * ((3-1.5)*sin(30°) + (0-1.5)*sin(0°)) = 180 * 1.5*0.5 = 135°
  code = round(135/5.625) = 24 = 0b011000
```

### Link Budget at 3 km (Car Target)
```
TX power:          +27.0 dBm (PA output, conservative)
TX cable loss:      -0.5 dB
TX divider loss:   -13.0 dB
TX phase shift:     -4.0 dB
TX feed:            -0.3 dB
TX array gain:     +22.0 dBi (16 elements × efficiency)
= TX EIRP:         +31.2 dBm

Free-space (2-way at 3km, 10GHz): -146.8 dB
Target RCS (car, 10m²):           +10.0 dBsm

RX array gain:     +22.0 dBi
RX phase shift:     -4.0 dB
RX combiner:        -1.0 dB
= Signal at mixer: -88.6 dBm

System NF:          ~2.0 dB
Noise BW (IF):      10 Hz (for 100 chirps × 1ms)
Noise power:       -172 + 10 + 2 = -160 dBm (approx)

SNR = -88.6 - (-160) = +71 dB  [theoretical maximum]
After range FFT + Doppler FFT processing losses: ~+40 dB practical SNR
Detection threshold: 15 dB → 25+ dB margin → WELL DETECTED at 3 km
```

---

## REGULATORY CHECKLIST (Run Before Any Field Operation)

Before operating outdoors:
- [ ] Klasse A amateur radio license in possession
- [ ] Operating frequency confirmed within 10.000–10.500 GHz band
- [ ] TX power confirmed ≤ 75 W PEP (our system: 1 W → passes)
- [ ] BNetzA consultation completed (email response received)
- [ ] Station identification enabled (callsign every 10 min)
- [ ] No operation near airports, military installations, radio telescopes
- [ ] Weather: no operation in lightning conditions
- [ ] Safety zone (2m) around antenna during operation
- [ ] Log of operation dates and locations maintained

---

## ESCALATION: WHEN TO STOP AND ASK THE USER

Stop immediately and ask the user if:
- Any proposed change would increase TX power above 30 dBm
- Any proposed frequency is outside 10.000–10.500 GHz
- You're about to modify PCB hardware files in a way that changes layer count or substrate material
- You're about to order components (verify with user before any actual ordering)
- The user asks for radar operation in or near restricted zones
- A technical change would increase cost by more than $500

---

*End of Future AI Instructions — AERIS-10P Project*
*If you're a future AI system: welcome to the AERIS-10P project. The team who designed this put considerable work into these documents so you'd have everything you need. Good luck with the build!*

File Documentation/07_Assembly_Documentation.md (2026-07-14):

# AERIS-10P Assembly Documentation
## Rev 1.0 — AERIS-10P Affordable Experimental Radar Intelligence System, 10 GHz Phased Array

**Document Number:** AERIS-ASY-001  
**Revision:** 1.0  
**Date:** 2026-07-14  
**Author:** RF Systems Engineering  
**Status:** Released  

---

## 1. Scope

This document provides complete assembly instructions for the AERIS-10P radar system. It covers all printed circuit board assemblies, the Rogers RO4003C antenna panel, chassis integration, RF cabling, power wiring, and software installation. The document is intended for use by a technician with experience in SMD assembly and RF system integration.

Read this document in its entirety before commencing any assembly. The sequence of steps is mandatory; components installed in the wrong order may damage parts or make later assembly steps impossible.

---

## 2. Required Tools

| Tool | Specification | Purpose |
|---|---|---|
| Soldering station | Weller WX2 or JBC DDSE, 350°C set point, fine conical tip | SMD and through-hole soldering |
| Hot air rework station | Hakko FR-872B or Metcal MFR-H1-DS, 350–380°C, 30–50 L/min airflow | QFN rework, component removal |
| SMD stencil | Laser-cut stainless steel, 0.12 mm thick, matched to each PCB paste layer | Solder paste application |
| Stencil printer (manual) | DEK or manual alignment jig | Consistent paste application |
| Microscope | Stereo, 10–40× magnification, LED illumination | Solder joint inspection |
| Digital multimeter | Fluke 87V or equivalent, 4.5-digit | Continuity, voltage measurement |
| Torque screwdriver | 0.1–1.0 Nm range, 1/4" drive with Torx and Phillips bits | M3 fasteners at correct torque |
| SMA torque wrench | 5/16" (8 mm) hex, calibrated to 0.9 Nm (8 in-lb) | SMA connector tightening |
| Nylon spanner / wrench | 5/16" (SMA), no-mar jaw | SMA connector tightening without PCB damage |
| Anti-static mat and wrist strap | Certified ESD workstation, <1 MΩ resistance | ESD protection |
| Reflow oven | Puhui T-962A or equivalent, 260°C peak profile | PCB reflow |
| X-ray (recommended) | Nordson DAGE Quadra 7 or equivalent | Verify QFN solder joints |
| Tweezers | Stainless, non-magnetic, fine tip (SS-SA or equivalent) | SMD component placement |
| Flux pen | Kester 951 or MG Chemicals 8341 | Touch-up soldering |
| Desoldering wick | 2.0 mm and 3.0 mm braid | Solder removal and rework |
| Pin header jig | Alignment fixture for connectors | Header placement |

---

## 3. Required Materials

| Material | Specification | Use |
|---|---|-----|
| Solder paste | Kester R256 Sn63Pb37 (−20°C storage) or Kester SAC305 lead-free, Type 4 powder | PCB assembly |
| Solder wire | Kester 44 Sn63Pb37, 0.5 mm diameter, or SAC305 equivalent | Touch-up, connectors |
| IPA flux remover | MG Chemicals 99.9% isopropyl alcohol | Post-solder board cleaning |
| Flux remover brush | ESD-safe bristle brush, 1" wide | Board cleaning |
| Kapton (polyimide) tape | 25 mm width, 68 µm total thickness | Masking, connector protection |
| Thermal interface material | Bergquist GP3000 pad or Shin-Etsu X-23-7921-5 paste, >3 W/m·K | IC-to-heatsink/chassis |
| Thread locker | Loctite 243 (medium strength, blue) | M3 fasteners in aluminium |
| M3 fastener kit | M3 × 6 mm, M3 × 8 mm, M3 × 10 mm cap-head, M3 × 5 mm BHCS, M3 nyloc nut, M3 flat washer | All structural fasteners |
| M5 ring terminal | Crimp, insulated, 10 mm lug, for 2.5 mm² cable | 24 V power input |
| AWG 18 wire | Silicone insulation, 600 V, 15 A rated | Internal power wiring |
| AWG 24 wire | PTFE, 0.1 mm² stranded | Signal and low-current wiring |
| Cable ties | 2.5 mm × 100 mm, nylon | Cable management |
| Heat shrink | 3:1 ratio, adhesive-lined, 3 mm and 6 mm diameter | Wire protection |
| Conformal coating | Humiseal 1B31 or MG Chemicals 419C (selective application to non-RF areas) | Environmental protection |
| Anti-static bags | Component-safe, pink or metallic shielding | Component storage |
| Desiccant | Silica gel sachets, 5 g | Storage |
| Polyimide label stock | Brady THT-170-499-2.5 or equivalent | Connector labelling |

---

## 4. PCB Assembly Sequence

### 4.1 General PCB Assembly Rules

- All PCB assembly must be performed at an ESD-safe workstation with technician wearing a grounded wrist strap.
- Inspect all PCBs for mechanical damage (cracked vias, scratched traces) before applying solder paste.
- Verify component orientation before and after placement. Pay particular attention to polarised components (capacitors, diodes, ICs).
- Use the correct solder profile for the solder paste chosen. SAC305 requires a higher peak temperature (245–260°C) than Sn63Pb37 (183–210°C peak).
- Perform visual inspection (10× minimum magnification) of all solder joints after reflow and before applying power.

### 4.2 AERIS_Power_Board — Assembly Sequence

The AERIS_Power_Board contains the LT8612 (5 V / 5 A buck converter), LT8607 (3.3 V / 3 A buck converter), and TPS65133 (±5 V / 1 A inverting/boost for RF bias rails). Power board must be assembled and verified before installation into the main chassis.

**Step 1 — Board Inspection**
Inspect the bare PCB for correct layer stack-up (4-layer), correct silkscreen designators, via quality. The LT8612 and LT8607 are in QFN-16 packages with exposed thermal pads; the PCB must have a matching thermal land with solder mask-defined (SMD) pads.

**Step 2 — Stencil Paste Application**
1. Align the stencil over the PCB using the alignment jig or corner pin registration.
2. Apply Sn63Pb37 Type 4 paste across all pads using the squeegee in a single smooth pass at approximately 30° angle with 0.5–1 kg pressure. A 0.12 mm stencil produces approximately 70–80 µm paste height for this package size.
3. Lift the stencil straight up. Inspect paste deposits under the microscope: all pads should show uniform, well-defined deposits. The thermal pad aperture for QFN packages must show paste covering ≥70% of the pad area with window-pane aperture relief.

**Step 3 — Component Placement**
Place components in this order (smallest first to avoid disturbing placed parts):
1. Decoupling capacitors: 100 nF 0402 X5R (place all per schematic).
2. Bulk capacitors: 22 µF 0805 X5R on input and output rails.
3. Bootstrap capacitors: 100 nF 0402 on BST pins.
4. Enable resistors, feedback resistors: 0402.
5. Inductors: Bourns SRR6038 or equivalent (4.7 µH for LT8612, 10 µH for LT8607). These are large and can be placed with tweezers.
6. LT8612 QFN-16: align pin 1 indicator. Place carefully — thermal pad is under the IC.
7. LT8607 QFN-12.
8. TPS65133 QFN-24.

**Step 4 — Reflow**
Profile for Sn63Pb37: Preheat 150°C for 90 s, soak 150–170°C for 60 s, ramp to 210°C peak over 30 s, dwell at peak ≤10 s, cool at ≤3°C/s. Do not allow peak temperature to exceed 230°C; LT8612 has a maximum soldering temperature of 260°C, but lower is preferred.

**Step 5 — Through-Hole and Connector Assembly**
After reflow and cleaning: hand-solder the screw terminal blocks (Phoenix Contact or equivalent, 5.08 mm pitch, 3-way for 24 V in, 4-way for output distribution), electrolytic bulk capacitors (Panasonic FR series, 100 µF 35 V), and LED indicator.

**Step 6 — Power Board Verification**
Before installing the power board in the main chassis:
1. Connect 24 V bench supply (current limited to 0.5 A).
2. Measure all output voltages at the output headers. Refer to Phase 1 power tests (PT-001 through PT-005) in the test procedures document.
3. If any output is incorrect, debug before proceeding.
4. Apply correct resistive loads and verify thermal stability for 10 minutes before declaring the board ready for installation.

---

### 4.3 AERIS_RF_Frontend — Assembly Sequence

The RF Frontend board carries the following ICs: 16× HMC647ALP5E (5×5 QFN, 32 pads + thermal), 4× HMC1040LP4E (4×4 QFN, 24 pads + thermal), 4× HMC213B (4×4 QFN, 16 pads + thermal), and associated passives, SMA edge connectors, and SMA surface-mount connectors. This is the most demanding PCB to assemble due to the density and the RF performance requirements of the HMC devices.

**Substrate and Trace Preparation**
The RF Frontend board is on Rogers RO4003C (for the antenna) or on FR4 with RF-grade impedance control for the IC board. Inspect for board warpage; warpage ≥0.5 mm will affect stencil printing and must be corrected with a flat platen or stencil printer.

**Step 1 — Substrate Cleaning**
Clean the board surface with IPA and a lint-free cloth before applying paste. Allow 5 minutes to dry fully. Any flux or organic contamination will cause paste adhesion failures.

**Step 2 — Stencil Paste Application**
Use the 0.12 mm stencil designed for the HMC647A pad pattern. The HMC647ALP5E has 5×5 mm package with 0.5 mm pitch pads on four sides and a large exposed thermal pad underneath. Stencil apertures for the thermal pad must be segmented (window-pane pattern) to prevent paste bridging.

Step through each IC location. For the HMC647A thermal pad, confirm ≥70% paste coverage. Any paste bridging between adjacent pads must be corrected with a flux pen and brass mesh before placement.

**Step 3 — Pick-and-Place**
If a pick-and-place machine is available, use the centroid file for this board. For manual placement:

1. HMC647ALP5E (16 pieces): Using fine-tip vacuum tweezer. Align pin 1 marker (dot or chamfered corner on package) to the pin 1 pad on the PCB silkscreen. Do not press down hard — paste compression will cause bridging. After placement, verify alignment with the microscope at 20× before moving to the next component.
2. HMC1040LP4E (4 pieces): Similarly align pin 1. These are the RX LNAs. Handle with ESD precautions; these GaAs PHEMT devices are highly ESD-sensitive (HBM Class 1B).
3. HMC213B (4 pieces): These are the double-balanced mixers. The package is 4×4 QFN. Align per silkscreen.
4. Passive components: 0402 resistors and capacitors.

**Step 4 — Reflow**
For SAC305 solder paste: Preheat to 175°C for 90 s, soak 175–200°C for 60 s, ramp to 245°C peak over 45 s, dwell ≤15 s at peak, cool ≤3°C/s. Do not exceed 260°C at any point (GaAs IC maximum reflow temperature).

**Step 5 — X-Ray Inspection (Recommended)**
After reflow, perform X-ray inspection on all QFN components. Verify:
- No solder bridging between any pads
- Uniform solder joint height under the thermal pad (thermal pad voiding ≤25% acceptable; >25% requires rework)
- No solder balls

If X-ray is not available, perform the following continuity test as a functional substitute: with no power applied, use a precision capacitance meter to verify the bypass capacitors on each IC power pin read the expected capacitance value (indicating the IC is connected to its supply rail through the bypass). Bridged pads will cause obvious shorts measurable with the DMM.

**Step 6 — SMA Connector Soldering (Hand)**
SMA edge-launch connectors (2.92 mm male, Johnson 142-0761-851 or equivalent) must be soldered by hand using the soldering station. These connectors are through-hole or edge-mount; the body is held by 4× PCB mount tabs on the edge of the board.

1. Apply flux (Kester 951 pen) to all four tabs and the centre pin landing pad.
2. Tack one tab first to hold the connector square.
3. Verify squareness with a steel rule against the PCB edge. The connector flange must be flush with the PCB edge within ±0.1 mm.
4. Solder remaining tabs. Use sufficient solder to fill each tab completely.
5. Solder the centre pin to the trace landing pad: brief 1 s contact, 350°C tip, rosin-core solder.

**Step 7 — Board Cleaning**
Wash the populated board with IPA using a brush, then rinse with fresh IPA. Use compressed nitrogen to remove liquid from under components. Inspect under bright light for remaining flux residue; repeat cleaning if visible.

**Step 8 — RF Frontend Functional Test**
Before installing the RF Frontend board, perform a basic bias test:
1. Apply +5 V and −5 V RF bias rails.
2. Measure quiescent current on each rail. Compare to expected values (HMC647A: ~50 mA per IC; HMC1040: ~60 mA per IC; HMC213B: ~80 mA per IC).
3. An unexpectedly high or low current indicates a damaged device or assembly error. Identify and correct before proceeding.

---

### 4.4 AERIS_MainBoard — Assembly Sequence

The MainBoard carries: STM32H743ZIT6 (LQFP-144, 0.5 mm pitch), ADF4159CCPZ (CP-40-3, 0.5 mm pitch), HMC733LP6CE (LP-6 QFN/SMD), ADS8661IRGAT (QFN-20), ABRACON AOCJY-10 OCXO module (through-hole or SMD footprint), USB connectors, Ethernet PHY (if separate from STM32), SPI headers, and JTAG/SWD debug connector.

**Step 1 — Stencil and Paste**
Apply paste. The STM32H743 in LQFP-144 at 0.5 mm pitch requires a finely aligned stencil; use a precision stencil printer if possible. The ADF4159 in CP-40-3 (QFN-style, 40 pads on 6×6 mm package) requires window-pane thermal pad aperture.

**Step 2 — Component Placement**
1. All 0402 and 0603 passives.
2. ADS8661IRGAT (QFN-20, 4×4 mm).
3. ADF4159CCPZ (CP-40-3, 6×6 mm). Pin 1 orientation is critical for PLL operation.
4. HMC733LP6CE: this is in a 40-lead QFN/SMD laminate carrier package. Verify the land pattern matches the footprint. Ground paddle must make solid thermal contact with the PCB copper.
5. STM32H743ZIT6 (LQFP-144, 20×20 mm): use a placement tool for the large package if available. Align carefully — all 144 leads must register over their pads. The pin 1 marker is on the corner of the IC. Inspect alignment at 40× before reflow; a misplaced STM32 at 0.5 mm pitch will cause all leads on one side to bridge.
6. OCXO module (ABRACON AOCJY-10): follow manufacturer recommendation for placement — the OCXO requires controlled thermal environment. Place last, after all SMD components are reflowed.

**Step 3 — Reflow**
Standard profile. Inspect STM32 leads at 40× after reflow for any bridges. If bridges are found, apply flux pen and drag solder with a fine tip (0.3 mm chisel); use desoldering wick to remove excess.

**Step 4 — Post-Reflow Assembly**
By hand, after reflow:
- Install 2×20 pin GPIO header (for RPi5 connection or SPI bus)
- Install USB Type-A connector (host)
- Install USB Micro-B or USB-C connector (device/programming)
- Install RJ-45 Ethernet jack
- Install SWD debug header (2×5, 1.27 mm pitch, Tag-Connect or standard)
- Install screw terminal for 24 V input sense

**Step 5 — MainBoard Verification**
1. With 3.3 V applied, verify STM32 is not consuming excess current (nominal: 50–150 mA at 480 MHz with peripherals active).
2. Connect SWD probe (STM32 ST-LINK V3 Mini or J-Link). Attempt to read device ID. STM32H743 device ID = 0x450. If not readable, check SWD connections and 3.3 V supply.

---

## 5. Antenna Panel Assembly

### 5.1 PCB Procurement

The antenna panel is a single-layer Rogers RO4003C PCB with the following specifications:

| Parameter | Value |
|---|---|
| Substrate | Rogers RO4003C |
| Thickness | 0.508 mm |
| εr | 3.55 |
| tan δ | 0.0027 |
| Copper | 1 oz (35 µm) electro-deposited on signal side, 1 oz on ground plane |
| Finish | Electroless Nickel Immersion Gold (ENIG) — do NOT specify HASL; HASL on Rogers is not compatible with 10 GHz patch performance |
| Dimensions | 200 mm × 120 mm |
| Drill | Vias for feed probe if used; otherwise microstrip feed line on top copper |
| Silkscreen | Top only, for element numbering |
| Solder mask | None on RF patch elements and feed lines; solder mask on connector pads only |

The patch dimensions are 13.8 mm × 13.8 mm, resonant at 10.05 GHz on this substrate. Element spacing is 15 mm (λ/2 at 10 GHz, λ = 30 mm). TX array: 4×4 elements, aperture 45 mm × 45 mm. RX array: 4×4 elements, aperture 45 mm × 45 mm. Total antenna panel dimensions: 200 mm × 120 mm.

### 5.2 Connector Soldering

The antenna panel uses 2.92 mm (K-connector) end-launch SMA connectors for the feed point connections to the RF Frontend board.

1. Verify connector footprint alignment with the antenna feed line on the copper layer.
2. Apply flux to the centre pin landing and body pads.
3. Solder with soldering station at 350°C. Apply minimum solder — excess solder on the centre conductor changes the characteristic impedance of the feed point.
4. Allow to cool 30 s before handling.
5. Mark each connector with a polyimide label: TX-01 through TX-16, RX-01 through RX-16, matching the element numbering on the silkscreen.

### 5.3 Antenna Panel Inspection

Before mounting, inspect the antenna panel:
- All 32 patch elements visible and undamaged
- Feed lines unbroken
- No copper contamination between feed lines and ground plane
- ENIG surface uniformly gold-coloured (no dark spots indicating dewetting)
- All SMA connectors seated flush and square

Perform a visual continuity check: the centre pin of each SMA connector should show continuity to the patch feed point trace. No continuity between centre pin and ground plane (ground plane is on the back side).

### 5.4 Antenna Panel Mounting

1. Place the antenna panel against the front face of the aluminium chassis. Align the 6× M3 mounting holes.
2. Install M3 × 6 mm cap-head screws with M3 flat washers and Loctite 243.
3. Tighten to 0.4 Nm with torque screwdriver. Over-tightening will bow the thin Rogers substrate.
4. Verify that the panel is flat against the chassis face (maximum gap 0.2 mm measured with feeler gauge at centre and corners).

---

## 6. Chassis Assembly

### 6.1 Chassis Specification

The AERIS-10P chassis is a custom aluminium enclosure: 300 mm × 200 mm × 100 mm. Material: 6061-T6 aluminium alloy, 2 mm wall thickness, anodised black. The chassis serves as the RF ground reference, thermal spreader, and structural frame. It includes:

- Front face: 200 mm × 100 mm, with 200 mm × 120 mm aperture for the antenna panel and M3 standoff inserts
- Rear face: M5 screw terminal for 24 V input, USB panel-mount connector, Ethernet panel-mount RJ-45, SMA bulkhead (for diagnostic port)
- Bottom: 3/8-16 UNC threaded insert (standard photo-tripod thread) for tripod mounting
- Internal: M3 threaded inserts (brass heat-set) for PCB tray, fan mount, cable management

### 6.2 Threaded Insert Installation

Install all brass M3 heat-set inserts before PCB installation:
1. Heat insert with the tip of the soldering iron at 200°C.
2. Press insert into the plastic bracket (if 3D-printed) or tighten screw-in inserts into aluminium chassis.
3. For the aluminium chassis, M3 threads are machined directly; verify threads with a thread gauge (M3×0.5) before assembly.

### 6.3 Electronics Tray Mounting

The electronics tray holds the three PCBs (Power Board, RF Frontend, MainBoard) on a 3 mm thick aluminium tray:

1. Mount AERIS_Power_Board to the tray with 4× M3×6 mm screws. Apply a 0.3 mm Bergquist thermal pad between the LT8612 and LT8607 packages and the aluminium tray surface (these ICs generate heat that must be conducted to the chassis).
2. Mount AERIS_RF_Frontend to the tray. Apply thermal paste (Shin-Etsu X-23-7921-5, sparingly — 0.1 mm layer) between the HMC451 PA exposed paddle and the tray. The PA is the primary heat source in the RF section.
3. Mount AERIS_MainBoard. STM32H743 and the OCXO module require moderate thermal management; use a thermal pad on the STM32 exposed paddle.
4. Apply Loctite 243 to all M3 screws before torquing to 0.35 Nm.

### 6.4 Cable Management and Routing

Cable routing sequence — always route in this order to avoid inaccessibility:

**RF Cables (First)**
Install all SMA RF cables before power or signal cables. Tight RF bends degrade signal quality and shorten cable life.
1. TX feed cables from HMC647A phase shifter outputs to the antenna feed SMA connectors.
2. RX feed cables from RX antenna SMA connectors to HMC1040 LNA inputs.
3. VCO output to ADF4159 reference / PLL input.
4. PA output cable (RG-405 semi-rigid from PA output to TX antenna panel distribution network).
5. Loop-back / calibration cable (internal 30 dB attenuator path).

Label each RF cable end with a polyimide heat-shrink label before installing the connector.

**Power Cables (Second)**
1. Run AWG 18 silicone wire from the 24 V screw terminal block on the power board to the chassis rear panel terminal.
2. Route power distribution cables from the power board output headers to the MainBoard and RF Frontend power input connectors.
3. Secure all power wires with cable ties at 50 mm intervals.

**Digital Signal Cables (Third)**
1. Flat flex cable (FFC) or ribbon cable from STM32 SPI headers to HMC647A phase shifter SPI bus.
2. USB cable from STM32 USB-HS port to Raspberry Pi 5 USB-A port.
3. SPI cable from STM32 to ADS8661 ADC input (keep short, ≤100 mm, to minimise capacitive loading).
4. GPIO cable for synchronisation signals (chirp trigger, frame sync) from STM32 to RPi5.

### 6.5 Cooling Fan Installation

Mount the 80 mm × 80 mm × 25 mm DC fan (5 V, ball-bearing, minimum 30 CFM) in the fan bracket on the rear of the chassis:
1. Orient fan to exhaust air out of the chassis (airflow: front → rear, across the PCB tray).
2. Mount with 4× M3×20 mm screws and rubber anti-vibration grommets (supplied with fan).
3. Connect fan to the +5 V rail via a 2-pin JST-XH connector. Wire with AWG 24 silicone.
4. Optionally connect fan tachometer output to STM32 GPIO for software fan speed monitoring.

### 6.6 Raspberry Pi 5 Installation

The Raspberry Pi 5 8GB mounts to a purpose-built bracket on the rear of the electronics tray:
1. Mount RPi5 to bracket with 4× M2.5 × 5 mm standoffs and M2.5 screws.
2. Apply a thermal pad (0.5 mm, 6 W/m·K) between the BCM2712 SoC and the bracket for heat spreading.
3. Connect: USB-A (RPi5) to USB-HS (STM32) data link; MicroHDMI to panel-mount HDMI (optional, for local display); USB-A (RPi5) to USB keyboard/mouse (for configuration, can be removed after commissioning).

---

## 7. RF Cabling

### 7.1 Semi-Rigid Coax (PA Output)

The PA output to the TX feed network uses RG-405 (0.086" semi-rigid, 50 Ω, SMA fittings):

1. Cut semi-rigid cable to the exact required length (measure with a string, then transfer to semi-rigid cutter or score-and-break tool).
2. Install SMA (m) connectors at each end using the crimp or solder attachment method per the connector manufacturer's assembly instructions.
3. Form any bends using a hand-bending tool or mandrel. Minimum bend radius for RG-405: 5 mm. Do not kink.
4. Measure insertion loss with VNA at 10 GHz. Maximum acceptable: 0.5 dB for a 100 mm length.

### 7.2 Phase Matching of TX Feed Cables

TX feed cables from the common TX source to the 16 phase shifter inputs must be electrically identical in length to within ±5° at 10 GHz (±1.4 mm physical length for solid PTFE cables).

**Phase matching procedure:**
1. Cut 16 TX feed cables to the same nominal physical length plus 5 mm excess.
2. Install connectors on all cables.
3. Using the VNA, measure S21 phase of each cable at 10.050 GHz relative to the reference cable (cable #1 or a reference airline).
4. Sort cables by measured electrical length. Cables within ±2.5° phase are matched pairs.
5. For cables outside ±2.5°, trim the physical length by 0.14 mm per degree and re-measure.
6. Record the measured electrical length of each cable on a cable record log. Install cables with their labels attached.

### 7.3 Flexible Coax (SMA)

For connections to the phase shifter board and ADC, use flexible SMA cables (086-equivalent, e.g., Huber+Suhner Sucoflex 104 or Times Microwave LMR-100A with SMA):
- Keep lengths ≤200 mm wherever possible.
- Dress all flexible cables with a minimum 50 mm bend radius.
- Label both ends of every cable before installation.
- Secure cables with cable ties — do not allow cables to press against sharp chassis edges.

---

## 8. Power Wiring

### 8.1 24 V Input Wiring

1. Install a chassis-mount screw terminal block (Phoenix Contact GMKD 3 or equivalent) on the rear panel for the 24 V input.
2. Wire the 24 V+ line with AWG 18 silicone, terminated at the chassis terminal with an M5 ring crimp terminal (0.5 Nm torque).
3. Install a 10 A inline automotive blade fuse holder in the 24 V+ line, within 100 mm of the input terminal. Use a 10 A fast-blow fuse (system maximum 8 A).
4. Connect 24 V return (GND) similarly; use AWG 18 green/yellow wire (or black per convention) with an M5 ring terminal.
5. Label the chassis terminal with a polyimide label: "24 V DC IN, 10 A MAX".

### 8.2 Internal Distribution

Run AWG 18 silicone wire from the power board output screw terminals to each consumer board:
- Use red for +V and black for GND consistently.
- Keep power wires away from RF cable routing by at least 10 mm.
- Install a ferrite bead on each power feed at the board entry connector (Fair-Rite 2643002402 or equivalent) to prevent RF from coupling onto the power wiring.

---

## 9. Software Installation

### 9.1 STM32 Firmware Installation

1. Install STM32CubeProgrammer (v2.14 or later) on the host PC.
2. Connect ST-LINK V3 Mini to the AERIS MainBoard 10-pin SWD header. Connect ST-LINK USB to the host PC.
3. In STM32CubeProgrammer: select "ST-LINK" interface, SWD mode, 4 MHz SWD frequency. Click "Connect". Verify device detected (STM32H743ZIT6, 2 MB flash).
4. Click "Open file" and select `AERIS_STM32_firmware_vX.X.X.bin` from the firmware release package.
5. Set start address: 0x08000000 (beginning of flash).
6. Click "Download". Programming takes approximately 15 seconds.
7. After completion, click "Disconnect". Remove ST-LINK.
8. Cycle power. Verify the heartbeat LED on the MainBoard flashes at 1 Hz, indicating firmware has started.
9. Open a serial terminal (115200 baud, 8N1) on the STM32 USB COM port. Verify the startup banner is printed: "AERIS-10P STM32 Firmware vX.X.X — READY".

### 9.2 Raspberry Pi 5 OS and Software Installation

**OS Installation:**
1. Using Raspberry Pi Imager (v1.8 or later) on a host PC, write "Raspberry Pi OS 64-bit (Bookworm)" to a 32 GB Class 10 microSD card or 64 GB USB SSD.
2. In the Imager advanced options: set hostname `aeris-radar`, enable SSH (public key authentication preferred), configure Wi-Fi or leave disabled.
3. Install the microSD or USB SSD in the RPi5. Boot.
4. After first boot, SSH into the RPi5: `ssh pi@aeris-radar.local`

**System Configuration:**
```
sudo raspi-config
# Interface Options → SPI → Enable
# Interface Options → I2C → Enable (if used)
# Interface Options → SSH → Enable
# Performance → GPU Memory → 128 MB
# Finish and Reboot
```

**Dependency Installation:**
```
sudo apt update && sudo apt upgrade -y
sudo apt install -y python3-numpy python3-scipy python3-matplotlib \
    python3-pyqt5 python3-serial python3-spidev \
    git build-essential cmake
```

**AERIS Software Package:**
```
cd /home/pi
git clone https://github.com/aeris-radar/aeris-software.git
cd aeris-software
pip3 install -r requirements.txt
sudo cp aeris-radar.service /etc/systemd/system/
sudo systemctl enable aeris-radar
sudo systemctl start aeris-radar
```

**SPI Bus Configuration:**
Add to `/boot/firmware/config.txt`:
```
dtparam=spi=on
dtoverlay=spi1-1cs
core_freq=250
```

Verify SPI bus is operating: `ls /dev/spidev*` should show `/dev/spidev0.0` and `/dev/spidev1.0`.

---

## 10. Initial Power-On Checklist

Complete this checklist in order before the first full-power-on of the assembled system.

| Step | Action | Expected Result | Check |
|---|---|---|---|
| 1 | Visually inspect all RF connections — all SMA connectors fully tightened to 0.9 Nm | All connectors seated and tight | |
| 2 | Verify no short circuits: measure 24 V input impedance with DMM (Ohmmeter) | >100 Ω (not a dead short) | |
| 3 | Verify +5 V rail at test point TP1 | 4.9–5.1 V | |
| 4 | Verify +3.3 V at TP2 | 3.25–3.35 V | |
| 5 | Verify +5 V_RF at TP3 | 4.85–5.15 V | |
| 6 | Verify −5 V_RF at TP4 | −4.85 to −5.15 V | |
| 7 | Apply 24 V from bench supply, current limited to 1 A | Power LED illuminates; current <1 A | |
| 8 | Increase current limit to 5 A. Verify heartbeat LED on MainBoard | LED flashes at 1 Hz | |
| 9 | Verify fan operating | Fan spins, audible airflow | |
| 10 | Verify RPi5 boots (activity LED pattern) | Activity LED flashing during boot | |
| 11 | Connect to RPi5 via SSH | SSH login successful | |
| 12 | Start AERIS software (`aeris-selftest --basic`) | All basic checks PASS | |
| 13 | Verify PLL locks (check status LED on MainBoard or software status) | PLL_LOCK indicator green | |
| 14 | Verify no unexpected heat on PA board (check by touch after 2 min) | PA warm to touch, not burning hot | |

---

## 11. Post-Assembly Verification Checklist

After the initial power-on checklist is complete, proceed to the test procedures document (06_Test_Procedures.md) and execute Phase 1 through Phase 6 in order. The following abbreviated checklist confirms basic functionality before formal testing:

| Check | Procedure | Pass Criterion |
|---|---|---|
| Power rails in tolerance | Measure with DMM at each rail test point | Per PT-002 limits |
| PLL lock at 10.050 GHz | Software status display | Lock detect HIGH |
| TX output detectable | SA at TX port (via 30 dB attenuator) | Signal present at 10.050 GHz |
| RX IF present | SA at IF output port | Signal present at IF frequency |
| SPI to phase shifters functional | Command all phase shifters to 0x3F, verify S21 phase changes | Phase changes on VNA |
| ADC reading | Software FFT display with loopback | Beat note visible |
| Beam steering at 0° | Boresight measurement with reference horn | Peak within ±2° of normal |
| Range detection | Corner reflector at 10 m | Detected within ±3 m |

---

*End of AERIS-10P Assembly Documentation Rev 1.0*

*Document controlled. Check repository for latest revision before use.*

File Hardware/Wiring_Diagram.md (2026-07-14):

# AERIS-10P Complete Wiring Diagram
## System Interconnect Documentation — Rev 1.0
**Date:** 2026-07-14

---

## 1. System-Level Wiring Overview

```
╔══════════════════════════════════════════════════════════════════════════════╗
║                        AERIS-10P SYSTEM WIRING                              ║
╚══════════════════════════════════════════════════════════════════════════════╝

  ┌─────────────┐    24V/8A     ┌──────────────────────────────────────────┐
  │  24V DC     │══════════════▶│            AERIS POWER BOARD              │
  │  Supply     │    XT60       │  ┌─────┐  ┌─────┐  ┌──────┐  ┌────────┐ │
  │  (Battery   │               │  │LT   │  │LT   │  │TPS   │  │LM7812  │ │
  │  or AC/DC)  │               │  │8612 │  │8607 │  │65133 │  │+12V    │ │
  └─────────────┘               │  │5V/5A│  │3.3V │  │±5V   │  │/1A PA  │ │
                                │  └──┬──┘  └──┬──┘  └──┬───┘  └───┬────┘ │
                                │     │         │         │           │       │
                                └─────┼─────────┼─────────┼───────────┼───────┘
                                      │         │         │           │
                              5V/5A   │  3.3V   │  ±5V   │    12V   │
                              (red)   │  (org)  │  (yel) │   (wht)  │
                                      │         │         │           │
  ┌───────────────────────────────────▼─────────▼─────────▼───────────▼────────┐
  │                          AERIS MAIN CONTROL BOARD                            │
  │                                                                               │
  │  ┌──────────────────┐   ┌────────────┐   ┌───────────┐   ┌───────────────┐  │
  │  │ STM32H743ZIT6    │   │ ADF4159    │   │ HMC733    │   │ ADS8661       │  │
  │  │ (480 MHz MCU)    │   │ FMCW PLL   │   │ 10 GHz    │   │ 16-bit ADC    │  │
  │  │                  │◀──│ chirp gen  │──▶│ VCO       │   │ 1 MSPS        │  │
  │  │ SPI1 ────────────┼──▶│            │   │+17 dBm    │   │               │  │
  │  │ SPI2 ─────────┐  │   └────────────┘   └─────┬─────┘   └───────┬───────┘  │
  │  │ SPI3 ──────┐  │  │                          │RF              │IF(ADC)    │
  │  │ SPI4 ───┐  │  │  │   ┌────────────┐         │               │           │
  │  │ USB ────┼──┼──┼──┼──▶│ USB CDC    │         │               │           │
  │  │ GPIO ───┼──┼──┼──┘   │ to PC/RPi5 │         │               │           │
  │  └─────────┼──┼──┼──────┴────────────┘         │               │           │
  │            │  │  │                              │               │           │
  └────────────┼──┼──┼──────────────────────────────┼───────────────┼───────────┘
               │  │  │                              │               │
               │  │  │ SPI1 (to TX phase shifters)  │ RF (10 GHz)  │ IF (<5kHz)
               │  │  │ SPI2 (to RX phase shifters)  │              │
               │  │  │                              │               │
               ▼  ▼  ▼                              ▼               ▼
  ┌──────────────────────────────────────────────────────────────────────────────┐
  │                        AERIS RF FRONTEND BOARD                                │
  │                                                                                │
  │  TRANSMIT PATH:                                                                │
  │                                                                                │
  │  VCO RF ──▶ ┌──────────┐  +29 dBm  ┌────────────────┐                        │
  │  input      │ HMC451   │──────────▶│ 1:16 Wilkinson │──▶ to Phase Shifters   │
  │  (+14 dBm)  │ X-band PA│           │ Power Divider  │   (see below)          │
  │             └──────────┘           │ (-13 dB split) │                        │
  │                                    └────────────────┘                        │
  │                                                                                │
  │  Phase Shifter Array (TX) — 16× HMC647ALP5E:                                  │
  │  ┌────────────────────────────────────────────────────────────────────┐       │
  │  │ SPI chain: STM32 SPI1 → PSH_TX[0] → PSH_TX[1] → ... → PSH_TX[15] │       │
  │  │ CS pin: GPIO PA_CS (active low, all 16 devices share CS)           │       │
  │  │ Each output: SMA 2.92mm → TX patch antenna element                 │       │
  │  └────────────────────────────────────────────────────────────────────┘       │
  │                                                                                │
  │  RECEIVE PATH:                                                                 │
  │                                                                                │
  │  16× RX antennas → 16× ┌──────────┐ → Phase Shifters → ┌──────────┐          │
  │                         │ HMC1040  │   (RX, SPI2)       │ 16:1     │          │
  │                         │ LNA      │                     │ Combiner │          │
  │                         │ NF 1.5dB │                     └────┬─────┘          │
  │                         └──────────┘                          │                │
  │                                                               ▼                │
  │                                                          ┌──────────┐          │
  │                                              LO (10GHz)─▶│ HMC213B  │          │
  │                                                          │ Mixer    │──▶ IF    │
  │                                                          └──────────┘  output  │
  │                                                                         to ADC │
  └──────────────────────────────────────────────────────────────────────────────┘
               │ USB-A                              │ SMA RF
               ▼                                    ▼
  ┌────────────────────┐              ┌────────────────────────┐
  │ Raspberry Pi 5     │              │ ANTENNA PANEL          │
  │ (Processing PC)    │              │ (200mm × 120mm RO4003C)│
  │                    │              │                        │
  │ Runs: Python FMCW  │              │ TX Array: 4×4 patches  │
  │ aeris_control.py   │              │ ┌──┬──┬──┬──┐         │
  │ visualization.py   │              │ │P │P │P │P │         │
  │ data_logger.py     │              │ ├──┼──┼──┼──┤  TX     │
  │                    │              │ │P │P │P │P │  side   │
  │ USB to laptop for  │              │ ├──┼──┼──┼──┤         │
  │ display (HDMI or   │              │ │P │P │P │P │         │
  │ Ethernet for SSH)  │              │ ├──┼──┼──┼──┤         │
  └────────────────────┘              │ │P │P │P │P │         │
                                      │ └──┴──┴──┴──┘         │
                                      │ ←  45mm  →            │
                                      │                        │
                                      │ RX Array: 4×4 patches  │
                                      │ ┌──┬──┬──┬──┐         │
                                      │ │P │P │P │P │         │
                                      │ ├──┼──┼──┼──┤  RX     │
                                      │ │P │P │P │P │  side   │
                                      │ ├──┼──┼──┼──┤         │
                                      │ │P │P │P │P │         │
                                      │ ├──┼──┼──┼──┤         │
                                      │ │P │P │P │P │         │
                                      │ └──┴──┴──┴──┘         │
                                      └────────────────────────┘
```

---

## 2. Power Wiring Detail

### 2.1 24V Input to Power Board

```
  24V Battery/PSU                    AERIS Power Board
  ┌──────────────┐                   ┌──────────────────────────────────┐
  │ (+) ─────────┼──── AWG 12 ──────▶│ F1 (8A Fuse) ─▶ D1 (SS36, RPP) │
  │              │    red wire        │              ─▶ C1 (1000µF/35V) │
  │ (-) ─────────┼──── AWG 12 ──────▶│ GND bus                         │
  │              │    black wire      │                                 │
  └──────────────┘                   │  LT8612: 24V→5V/5A              │
   XT60 Female                       │  ├── L1 (4.7µH)                 │
   on supply side                    │  ├── C2 (100µF output)          │
                                     │  └── feedback R1=100k, R2=22k   │
  NOTE: XT60 connector                                                  │
  Male on power board                │  LT8607: 5V→3.3V/3A            │
  Female on supply                   │  ├── L2 (2.2µH)                 │
  (prevents accidental               │  └── C3 (47µF output)           │
  polarity reversal)                 │                                  │
                                     │  TPS65133: ±5V/1A              │
                                     │  (for RF bias rails)             │
                                     │                                  │
                                     │  LM7812: 24V→12V/1A            │
                                     │  (for HMC451 PA supply)          │
                                     └──────────────────────────────────┘
```

### 2.2 Power Distribution from Power Board to Main Board

```
  Power Board Output          Cable              Main Board Input
  ┌────────────────┐          DF13               ┌────────────────────┐
  │ J1 (6-pin)     │          6-pin              │ J2 (6-pin)         │
  │ Pin 1: 5V      │──AWG18──▶│ Pin 1: 5V       │                    │
  │ Pin 2: 5V      │──AWG18──▶│ Pin 2: 5V (x2)  │ → STM32, RPi USB  │
  │ Pin 3: 3.3V    │──AWG18──▶│ Pin 3: 3.3V     │ → Logic devices    │
  │ Pin 4: GND     │──AWG18──▶│ Pin 4: GND      │                    │
  │ Pin 5: GND     │──AWG18──▶│ Pin 5: GND (x2) │                    │
  │ Pin 6: 12V     │──AWG18──▶│ Pin 6: 12V      │ → PA supply        │
  └────────────────┘          └─────────────────┘└────────────────────┘

  Power Board to RF Frontend:
  ┌────────────────┐          Molex 8-pin          ┌────────────────────┐
  │ J3 (8-pin)     │                               │ J4 (8-pin)         │
  │ Pin 1: +5V PA  │──AWG18──────────────────────▶│ → HMC451 Vd supply │
  │ Pin 2: +5V RF  │──AWG18──────────────────────▶│ → HMC647A supply   │
  │ Pin 3: +3.3V   │──AWG18──────────────────────▶│ → LNA logic supply  │
  │ Pin 4: +5V RF  │──AWG18──────────────────────▶│ → LNA drain supply  │
  │ Pin 5: +5V RFB │──AWG18──────────────────────▶│ → Bias circuits     │
  │ Pin 6: -5V RFB │──AWG18──────────────────────▶│ → Gate bias neg.   │
  │ Pin 7: GND     │──AWG18──────────────────────▶│ GND (×2)            │
  │ Pin 8: GND     │──AWG18──────────────────────▶│                     │
  └────────────────┘                               └────────────────────┘
```

---

## 3. RF Signal Wiring (SMA / 2.92 mm Connectors)

### 3.1 TX Path RF Connections

```
  Main Board                   RF Frontend Board
  ┌─────────────┐              ┌──────────────────────────────────────┐
  │             │              │                                        │
  │ J_VCO_OUT   │──RG405──────▶│ J_PA_IN     (SMA, +14 dBm input)     │
  │ (SMA female)│  10cm semi   │                                        │
  │             │  rigid       │  PA HMC451: +14 dBm → +29 dBm        │
  │ J_LO_OUT    │──RG405──────▶│ J_LO_IN     (SMA, +10 dBm LO)        │
  │ (SMA female)│  10cm        │ (feeds mixer for IF generation)       │
  └─────────────┘              │                                        │
                               │  PA OUT (J_PA_OUT, SMA)               │
                               │   └──▶ 1:16 Wilkinson Divider         │
                               │         (internal PCB trace network)   │
                               │                                        │
                               │  16× TX Phase Shifter Outputs:         │
                               │  J_TX[0]..J_TX[15]  (2.92mm female)   │
                               └──────────────────────────────────────┘
                                  ↓ 16× RG405 flexible, 80mm each, ↓
                                  ↓ PHASE-MATCHED to ±5° at 10 GHz  ↓
                               ┌──────────────────────────────────────┐
                               │ ANTENNA PANEL (Rogers RO4003C PCB)   │
                               │                                        │
                               │  TX patch elements:                    │
                               │  ┌─────────────────────────────────┐  │
                               │  │ P[0,0] P[0,1] P[0,2] P[0,3]   │  │
                               │  │ P[1,0] P[1,1] P[1,2] P[1,3]   │  │
                               │  │ P[2,0] P[2,1] P[2,2] P[2,3]   │  │
                               │  │ P[3,0] P[3,1] P[3,2] P[3,3]   │  │
                               │  └─────────────────────────────────┘  │
                               │  Element spacing: 15mm × 15mm          │
                               │  Each fed via 2.92mm SMA launch pad    │
                               └──────────────────────────────────────┘
```

### 3.2 RX Path RF Connections

```
  ANTENNA PANEL (RX side)      RF Frontend Board
  ┌───────────────────────┐    ┌──────────────────────────────────────┐
  │ 16× RX patch elements │    │                                        │
  │ P[0,0]..P[3,3]        │    │  16× LNA inputs:                      │
  │                        │    │  J_RX[0]..J_RX[15]  (2.92mm female)  │
  │  ↑ 15mm spacing ↑     │    │                                        │
  │                        │    │  LNA HMC1040LP4E (×16):               │
  │ 2.92mm SMA launch pads│    │  ┌──────────────────────────────────┐ │
  └──────┬─────────────────┘   │  │ Each: NF 1.5 dB, Gain 18 dB     │ │
         │  16× RG405           │  │ VDD = +3.3V (drain)              │ │
         │  flexible            │  │ VGG = +0.3V (gate, from DAC)    │ │
         │  80mm each           │  └──────────────────────────────────┘ │
         │  phase-matched       │                                        │
         ▼                      │  16× RX Phase Shifters (HMC647A):     │
  ┌──────────────────────────── │  SPI2 chain control                   │
  │  J_RX_IN[0..15]             │                                        │
  └──────────────────────────── │  16:1 Wilkinson Combiner (PCB trace)  │
                                 │   (-13 dB split loss + +12 dB comb.) │
                                 │                                        │
                                 │  Combined RX signal → Mixer input:     │
                                 │  J_MIX_RF  (SMA, ~-35 dBm received)  │
                                 │                                        │
                                 │  HMC213B Mixer:                        │
                                 │  RF in: from combiner                  │
                                 │  LO in: from VCO (+10 dBm, internal)   │
                                 │  IF out: J_IF_OUT (SMA, 0–5 kHz)      │
                                 │   └──▶ IF Amplifier (+20 dB)          │
                                 │   └──▶ Low-pass filter (fc = 10 kHz) │
                                 │   └──▶ J_ADC_IN (SMA or BNC)         │
                                 └──────────────────────────────────────┘
                                           │ BNC or SMA
                                           ▼
                               ┌─────────────────────┐
                               │ Main Board: ADS8661  │
                               │ 16-bit ADC, 1 MSPS   │
                               │ SPI4 → STM32H743     │
                               └─────────────────────┘
```

---

## 4. Digital Control Wiring (SPI Buses)

### 4.1 SPI Bus Map

```
  STM32H743ZIT6                          Devices
  ┌─────────────────────────────────┐
  │                                 │
  │  SPI1 (AF5, 10 MHz)             │
  │  ├── SCK:  PA5  ─────────────────────────────────▶ TX Phase Shifter chain
  │  ├── MOSI: PA7  ─────────────────────────────────▶ HMC647A × 16 (TX array)
  │  ├── MISO: PA6  ◀────────────────────────────────  (readback if needed)
  │  └── CS:   PA4  ─────────────────────────────────▶ All TX shifters (shared)
  │                                                       ┌─────┐   ┌─────┐
  │  Daisy chain: Data in → PSH_TX[15] → PSH_TX[14] → ... → PSH_TX[0] → Data out
  │                                                       └─────┘   └─────┘
  │  SPI2 (AF5, 10 MHz)
  │  ├── SCK:  PB13 ─────────────────────────────────▶ RX Phase Shifter chain
  │  ├── MOSI: PB15 ─────────────────────────────────▶ HMC647A × 16 (RX array)
  │  ├── MISO: PB14 ◀────────────────────────────────  
  │  └── CS:   PB12 ─────────────────────────────────▶ All RX shifters (shared)
  │
  │  SPI3 (AF6, 1 MHz)
  │  ├── SCK:  PC10 ─────────────────────────────────▶ ADF4159 CLK
  │  ├── MOSI: PC12 ─────────────────────────────────▶ ADF4159 DATA
  │  ├── MISO: PC11 (not used for ADF4159)
  │  └── CS:   PA15 ─────────────────────────────────▶ ADF4159 LE (Latch Enable)
  │
  │  SPI4 (AF5, 1 MHz)
  │  ├── SCK:  PE12 ─────────────────────────────────▶ ADS8661 SCLK
  │  ├── MOSI: PE14 ─────────────────────────────────▶ ADS8661 SDI
  │  ├── MISO: PE13 ◀────────────────────────────────  ADS8661 SDO
  │  └── CS:   PE11 ─────────────────────────────────▶ ADS8661 /CS
  │
  │  GPIO CONTROL
  │  ├── PC0  (PA_EN)  ──────────────────────────────▶ HMC451 PA Enable
  │  ├── PC1  (LNA_EN) ──────────────────────────────▶ HMC1040 LNA bias enable
  │  ├── PC2  (RAMP_EN)──────────────────────────────▶ ADF4159 TXDATA (ramp trigger)
  │  ├── PC3  (LED_OK) ──────────────────────────────▶ System OK LED (green)
  │  ├── PC4  (LED_TX) ──────────────────────────────▶ TX active LED (red)
  │  ├── PD0  (TEMP_INT)◀─────────────────────────────  NTC thermistor on PA (analog)
  │  └── PA0  (ADC_BUSY)◀────────────────────────────  ADS8661 BUSY signal
  │
  │  USB FS (PA11/PA12)
  │  ├── USB_DP: PA12 ────────────────────────────────▶ USB micro-B connector pin 3
  │  └── USB_DM: PA11 ────────────────────────────────▶ USB micro-B connector pin 2
  │              (VBUS detection on PA9)
  │
  │  UART1 (debug, 115200 baud)
  │  ├── TX: PA9  ─────────────────────────────────────▶ Debug UART header pin 1
  │  └── RX: PA10 ◀───────────────────────────────────  Debug UART header pin 2
  │
  └─────────────────────────────────┘
```

### 4.2 Phase Shifter SPI Daisy-Chain Detail

```
  STM32 SPI1 (TX array control):
  ┌──────────┐
  │  STM32   │ MOSI ──▶ DATA_IN[PSH_TX_15]
  │  SPI1    │ SCK  ──▶ CLK (all shifters, parallel)
  │          │ CS   ──▶ LE (Latch Enable, all shifters, parallel)
  └──────────┘

  Data flow for one SPI transaction (update all 16 phase shifters):
  
  1. Assert CS LOW
  2. Send 16 bytes, one per shifter, MSB to LSB order:
     Byte[0] = phase word for PSH_TX[15]  (6 bits used, bit[5:0])
     Byte[1] = phase word for PSH_TX[14]
     ...
     Byte[15] = phase word for PSH_TX[0]
  3. De-assert CS HIGH → all 16 shifters latch simultaneously
  4. Wait 2 µs for phase to settle
  
  HMC647A Phase Word Encoding:
  Bit 5 (MSB) = 180° bit  (0=bypass, 1=insert 180° shift)
  Bit 4       = 90° bit
  Bit 3       = 45° bit
  Bit 2       = 22.5° bit
  Bit 1       = 11.25° bit
  Bit 0 (LSB) = 5.625° bit
  
  Total phase = sum of active bits
  Example: 90° = bit4 set → byte = 0b00010000 = 0x10 = 16 decimal
  Example: 45° = bit3 set → byte = 0b00001000 = 0x08 = 8 decimal
```

---

## 5. USB Connection to Raspberry Pi 5

```
  Main Board (STM32H743)       Cable              Raspberry Pi 5
  ┌─────────────────────┐                          ┌─────────────────────┐
  │                     │                          │                     │
  │ USB micro-B         │──USB-A to Micro-B───────▶│ USB3 Type-A port    │
  │ J_USB1              │  (0.3m, shielded)        │                     │
  │ (CDC-ACM device)    │                          │ /dev/ttyACM0        │
  │                     │                          │ (CDC-ACM serial)    │
  │ Also: Ethernet RJ45 │──Ethernet Cat6──────────▶│ Ethernet port       │
  │ (for faster data if │  (optional, for          │ (SSH access,        │
  │ USB is insufficient)│  high-bandwidth mode)    │ higher throughput)  │
  │                     │                          │                     │
  └─────────────────────┘                          │ HDMI: to monitor    │
                                                   │ USB: keyboard/mouse │
                                                   │ (for on-site use)   │
                                                   └─────────────────────┘
  
  USB Protocol:
  - CDC-ACM serial at 2 Mbaud
  - Packet format: [0xAA][0x55][uint16 length][uint8 cmd][payload][uint8 checksum]
  - Data rate for ADC streaming: 16-bit × 8 kSPS = 128 kbps → well within USB FS limit
  - Command round-trip latency: <5 ms typical
```

---

## 6. Cooling System Wiring

```
  Main Board                   Fan Bracket (80mm fan)
  ┌────────────────┐           ┌──────────────────────────────┐
  │ J_FAN (2-pin)  │           │ Fan (5V, 0.2A, 80mm × 25mm) │
  │ Pin 1: 5V (red)│──AWG26───▶│ Red wire (+5V)               │
  │ Pin 2: GND(blk)│──AWG26───▶│ Black wire (GND)             │
  └────────────────┘           │ Yellow wire (tach): NC       │
                               └──────────────────────────────┘
  
  Thermal Protection:
  ┌────────────────┐
  │ NTC Thermistor │──── Kapton tape adhesive mount on PA heatsink
  │ (10kΩ @ 25°C) │──▶ Main Board ADC input (PA0/PD0)
  │                │     STM32 reads every 100ms
  │                │     Shutdown threshold: 70°C
  └────────────────┘     Warning threshold: 60°C
```

---

## 7. External Connectors Summary

| Connector | Type | Location | Signal | Wire Color | Notes |
|---|---|---|---|---|---|
| J_POWER_IN | XT60 Male | Power Board | 24V DC | Red/Black | 8A rated |
| J_TX_RF | SMA Female | Front Panel | RF TX Out (SMA to VNA for test) | N/A (RF) | For test access |
| J_RX_RF | SMA Female | Front Panel | RF RX In (direct) | N/A (RF) | For test access |
| J_IF_MON | SMA Female | Front Panel | IF output monitor | N/A (RF) | Spectrum analyzer |
| J_USB | Micro-USB B | Front Panel | CDC-ACM to RPi5/PC | USB cable | Primary control |
| J_ETH | RJ45 | Front Panel | Ethernet | Cat6 | Optional |
| J_DEBUG | 2.54mm 4-pin | Internal | UART debug | AWG26 | 3.3V UART |
| J_JTAG | 2.54mm 20-pin | Internal | ST-Link SWD | Ribbon | Firmware flash |
| J_ANT_TX[0..15] | 2.92mm Female | RF Board | TX antenna feeds | Semi-rigid | Phase matched |
| J_ANT_RX[0..15] | 2.92mm Female | RF Board | RX antenna inputs | Semi-rigid | Phase matched |

---

## 8. Cable Specifications

| Cable | Type | Length | Application | Notes |
|---|---|---|---|---|
| 24V power | AWG12, 2-conductor | 0.5m | Battery to Power Board | XT60 connectors |
| Board power | AWG18, multi-conductor | 0.15m | Power Board to Main Board | DF13 connector |
| RF frontend power | AWG18, multi-conductor | 0.15m | Power Board to RF Frontend | Molex 8-pin |
| VCO to PA | RG-405 semi-rigid | 0.10m | Main Board to RF Frontend | 2.92mm both ends |
| LO to Mixer | RG-405 semi-rigid | 0.10m | VCO tap to Mixer LO | 2.92mm both ends |
| TX phase shifter to antenna | RG-405 flexible | 0.08m × 16 | Phase shifters to TX patches | 2.92mm, phase-matched |
| RX antenna to LNA | RG-405 flexible | 0.08m × 16 | RX patches to LNA inputs | 2.92mm, phase-matched |
| IF output to ADC | RG-174 flexible | 0.15m | Mixer IF to ADC input | SMA to SMA |
| USB control | USB-A to Micro-B | 0.30m | STM32 to RPi5 | Standard USB 2.0 |
| Fan power | AWG26, 2-conductor | 0.20m | Main Board to fan | JST 2-pin |

---

## 9. Phase Matching Procedure for RF Cables

Phase matching of the 16 TX and 16 RX antenna cables is critical for proper beam steering.

**Procedure:**
1. Cut all 16 TX cables to the same physical length ±0.5mm
2. Measure S21 phase of each cable with VNA at 10.05 GHz
3. Record phase of each cable: φ₁, φ₂, ..., φ₁₆
4. Compute mean phase: φ_mean = average(φ₁..φ₁₆)
5. Compute error: Δφᵢ = φᵢ - φ_mean
6. If |Δφᵢ| > 5°: trim cable slightly (shorten by δL where δL = Δφᵢ × λ/(360°) = Δφᵢ × 0.03/360)
7. Repeat measurement until all cables within ±3° of mean
8. Store residual errors in calibration table for software correction

**Expected cable electrical length:** 80mm at velocity factor 0.70 (ε_r_eff ≈ 2.04 for RG-405) → electrical length = 80/0.70 = 114.3mm = 3.81λ at 10 GHz → phase = 3.81 × 360° = 1372° ≡ 292° (mod 360°)

---

*End of Wiring Diagram Document — AERIS-10P Rev 1.0*

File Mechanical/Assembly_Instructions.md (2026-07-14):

# AERIS-10P Mechanical Assembly Instructions
## Rev 1.0 — 2026-07-14

---

## Required Tools

| Tool | Specification | Use |
|---|---|---|
| Allen key set | M2, M3, M4, M5 hex | Fasteners |
| Torque screwdriver | 0.2–2 N·m | Calibrated tightening |
| SMA torque wrench | 5/16", 7/16" | RF connectors |
| Soldering iron | 350°C fine tip | Thread inserts (PETG) |
| 3D printer | PETG compatible | Print prototype parts |
| Drill press | 5–7mm bits | Front panel holes |
| File | Fine metal file | Deburring |

---

## Step 1: Prepare Electronics Tray

1. Print `electronics_tray.stl` in PETG (30% infill, 0.2mm layers)
   — OR machine from 2mm aluminium sheet
2. Install M3 threaded heat-set inserts at all 20 standoff positions:
   - Heat soldering iron to 200°C
   - Place insert on hole
   - Press gently with iron tip for 5–8 seconds until flush
   - Allow 30 seconds to cool before disturbing
3. Install M3 brass standoffs (4mm height) at PCB positions
4. Verify all standoffs are vertical using a right-angle gauge

---

## Step 2: Install PCBs on Tray

1. **Power Board first:**
   - Lower board onto 4 standoffs at (15,15), (105,15), (15,85), (105,85)
   - Fasten with M3×8 button-head hex screws
   - Verify: no board flex, all corners seated flat
2. **Main Control Board:**
   - Lower onto standoffs at (120,15), (270,15), (120,105), (270,105)
   - Fasten with M3×8 screws
3. **Phase Shifter Boards (RX then TX):**
   - Mount at (145,100)–(255,100)–(145,170)–(255,170)
   - Label TX board with "TX" marker pen before installing
4. **RF Frontend Board:**
   - Mount at (15,100)–(105,100)–(15,150)–(105,150)
5. **Raspberry Pi 5:**
   - Use standard RPi mounting holes (85×56mm)
   - Mount at (185,25)–(260,25)–(185,70)–(260,70)

---

## Step 3: Cable Routing — RF Cables

**Critical: RF cables before power cables (easier access).**

1. Connect VCO RF output (SMA on Main Board) → HMC451 PA input (2.92mm on RF Board)
   - Cable: RG-405 semi-rigid, 100mm, SMA one end / 2.92mm other end
   - Bend cable gently (min bend radius 5mm)
   - Torque SMA to 0.56 N·m, 2.92mm to 0.45 N·m

2. Connect LO tap (SMA on Main Board or VCO board) → Mixer LO input
   - Cable: RG-405, 100mm
   - Add 3 dB attenuator pad if LO power is too high

3. Connect TX Phase Shifter Board outputs to RF Frontend TX inputs (×16):
   - 16× RG-405 flexible, 80mm each
   - **Before installing:** label each cable 0–15 at both ends
   - Connect in order: cable 0 → PS output 0 → TX divider input 0, etc.

4. Connect RX antenna outputs to LNA inputs (×16):
   - 16× RG-405, 80mm each
   - Same labeling procedure

5. Connect IF output (SMA on RF Board) → ADC input on Main Board
   - Cable: RG-174 flexible, 150mm, SMA both ends

6. **Phase-match TX cables:**
   - After all cables are installed (but before final tray installation)
   - Measure S21 phase on VNA for each cable at 10.05 GHz
   - Record phases in a table: φ₀, φ₁, ..., φ₁₅
   - Target: all within ±5° of mean
   - If any cable is out of spec: trim slightly (shorten by 1–2mm) and remeasure

---

## Step 4: Cable Routing — Power and Digital

1. Connect Power Board output (J2, DF13-6P) → Main Board power input (J2)
   - Use supplied cable assembly or make custom: AWG18, 150mm
   - Pin 1 and 2 to 5V rail on both boards
   - Verify: no reversed polarity

2. Connect Power Board RF output (J3, Molex 8-pin) → RF Frontend power input
   - AWG18 multi-conductor cable, 150mm
   - Label each wire (use colored wire or shrink-wrap labels)

3. Route USB cable (Main Board USB Micro-B → RPi5 USB3 port):
   - Cable length: 300mm
   - Use a cable with a 90° connector if space is tight

4. Connect cooling fan (J_FAN on Main Board) → 80mm fan
   - AWG26, 200mm, JST 2-pin
   - Fan should be oriented to push air toward PA heatsink

5. Secure all cables with cable ties to internal mounting points
   - Never bundle RF cables with power cables (EMI interference)
   - Keep RF cables as short as practical
   - Maintain SMA bend radius ≥ 5mm

---

## Step 5: Install Electronics Tray in Enclosure

1. Lower tray assembly into enclosure from top
2. Route front-panel cables (USB, RF connectors) through front panel cutouts before securing tray
3. Fasten tray with 4× M3×12 countersunk screws through enclosure walls
4. Check: tray is level, no RF connectors pinched or strained

---

## Step 6: Mount Antenna Panel

1. Connect 32× 2.92mm SMA cables from Phase Shifter Boards to Antenna Panel
   - Connect TX cables to TX patch array (left side of panel)
   - Connect RX cables to RX patch array (right side)
   - All cables exit front of enclosure through slots before panel is attached
2. Mount antenna panel to front face of enclosure:
   - Use 6× M3×8 screws through panel mounting holes into front panel threaded holes
   - Torque to 0.5 N·m
3. Verify: panel is flush with enclosure, no gaps, all SMA connections accessible

---

## Step 7: Install Front Panel

1. Install external RF connectors (SMA female panel mount) in front panel cutouts
2. Install USB Micro-B panel-mount connector
3. Install RJ45 panel-mount (optional)
4. Install XT60 female panel-mount for 24V input
5. Install power switch (rocker, SPST 10A)
6. Install LED bezels and LEDs (connect internal cables before installing)
7. Mount front panel to enclosure: 4× M3 screws, torque 0.4 N·m

---

## Step 8: Install Lid

1. Verify all internal connections are complete
2. Take thermal infrared photo of all ICs with brief 5-minute power-on (check hotspots)
3. Apply foam gasket to lid perimeter (optional IP43 sealing)
4. Lower lid onto enclosure
5. Fasten with 4× M3×10 countersunk screws at corners

---

## Step 9: Mount on Tripod Adapter

1. Attach tripod adapter to enclosure bottom:
   - 4× M5×12 button-head hex screws through adapter into enclosure
   - Torque: 1.0 N·m
2. Thread camera tripod into 1/4"-20 UNC hole on adapter
3. Tilt and lock at desired elevation angle
4. Verify: radar does not tip on tripod, center of gravity is stable

---

## Step 10: Final Inspection Checklist

- [ ] All RF connectors torqued to spec (0.45 N·m for 2.92mm, 0.56 N·m for SMA)
- [ ] No cable kinks or minimum bend radius violations
- [ ] Fan spinning (verify with brief power-on)
- [ ] All PCBs secured with no flex
- [ ] Antenna panel flush and secure
- [ ] USB, Ethernet, and 24V connectors accessible from front
- [ ] RPi5 accessible (or Ethernet SSH configured)
- [ ] XT60 input connector is female (cannot accidentally mate wrong polarity)
- [ ] Ground connection: chassis ground to enclosure wall
- [ ] Warning label installed: "RF RADIATION HAZARD — MAINTAIN 2m CLEARANCE"

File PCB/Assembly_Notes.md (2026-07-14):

# AERIS-10P PCB Assembly Notes
## Rev 1.0 — 2026-07-14

---

## Assembly Sequence

**Critical rule:** Never power a board until ALL assembly and inspection is complete for that board.

1. Power Board → test all voltage rails → pass
2. Main Control Board → test digital interfaces → pass
3. RF Frontend Board → test RF connectivity → pass
4. Phase Shifter Boards (×2) → test SPI and RF → pass
5. Antenna Panel → test S11 → pass
6. Integration: interconnect all boards → full system test

---

## 1. Power Board Assembly

**Tools:** Hot-air rework station (350°C, 5 L/min), fine-tip soldering iron, flux paste, IPA

1. Apply solder paste with stencil (SMD components, 0.5mm openings for 0402)
2. Place components with tweezers: start with ICs (LT8612, LT8607, TPS65133, LM7812)
3. Place inductors and electrolytic capacitors
4. Place XT60 connector (through-hole — solder last by hand)
5. Place indicator LEDs and resistors
6. Reflow: ramp 2°C/s, preheat 150°C for 90s, peak 250°C for 30s, cool 3°C/s
7. **Inspect:** Check no solder bridges under LT8612 (MSOP-16). Use 10× magnifier.
8. Solder XT60 connector by hand: liquid flux, large iron tip, 60s solder time
9. **Test before connecting to anything:**
   - Connect 24V bench supply (current limit: 0.5A initially)
   - Measure TP1 (+5V): expect 5.0 ± 0.15V
   - Measure TP2 (+3.3V): expect 3.3 ± 0.1V
   - If rail is wrong: disconnect immediately, check component placement
10. Load test: connect 1A dummy load to 5V rail, verify regulation holds

---

## 2. Main Control Board Assembly

**Note:** STM32H743ZIT6 in LQFP-144 has 0.5mm pitch — use solder paste stencil.

1. Apply paste via laser-cut stencil
2. Place STM32H743ZIT6: align pin 1 marker, center in footprint
3. Place ADF4159CCPZ (CP-40-3 package): 0.5mm pitch, use vacuum pickup
4. Place HMC733LP6CE (LP-6): RF component, handle carefully
5. Place ADS8661IRGAT (QFN-20): small package, check orientation
6. Place OCXO module (through-hole or SMD mount): last before reflow
7. Place all passives: 0402 caps and resistors
8. Place USB connector: SMD type, verify pad alignment before reflow
9. Reflow: standard SAC305 profile (250°C peak)
10. Post-reflow inspection:
    - LQFP-144 under microscope: check for solder bridges at all 144 pins
    - Check pad coverage on QFN components (X-ray recommended if available)
11. Hand solder: debug header, SWD connector, XT60-style power connector
12. **First power-on sequence:**
    - Connect power board, measure 3.3V on Main Board
    - Attach ST-Link V3 via SWD header
    - Flash minimal blinky firmware
    - Verify LED blinks at 1 Hz → STM32 running

---

## 3. RF Frontend Board Assembly

**Most critical board. Rogers RO4003C substrate — handle carefully.**

⚠️ **CAUTION:** Rogers substrate is fragile at PCB edges. Do not snap or flex.
⚠️ **ESD:** All HMC components are ESD-sensitive. Ground yourself with ESD strap before handling.

1. Clean Rogers PCB with IPA to remove any contamination
2. Apply solder paste — only SAC305 paste for this board (HASL forbidden on Rogers)
3. Place HMC647A phase shifters (×16, QFN-32 5×5mm):
   - These are the most critical components to place correctly
   - Use vacuum pickup tool, verify orientation (pin 1 marker)
   - Place in two rows: TX group (8) and RX group (8)
4. Place HMC1040 LNAs (×16, QFN-24 4×4mm)
5. Place HMC213B mixer (QFN-16, 4×4mm)
6. Place HMC451 PA (LS-6 package)
7. Place all passive components
8. Reflow: 260°C peak, 30s, 2°C/s cool (SAC305 profile)
9. **Post-reflow (critical):**
   - Inspect all QFN solder joints: look for bridging and voiding
   - X-ray inspection strongly recommended for QFN components
   - Clean with ultrasonic IPA bath or spray flux remover
10. **Install SMA/2.92mm connectors AFTER reflow:**
    - These are not reflow-compatible — solder by hand
    - 2.92mm connector: use fixture to align perpendicular to board
    - Solder the ground flange first (4 ground pads around connector)
    - Then solder center pin: use small iron tip, minimal flux
    - Verify: measure S11 with VNA at connection point
11. **First RF test:**
    - Apply +5V RF and +3.3V to board
    - Connect VNA to PA input port, verify 50Ω S11 match
    - Connect signal generator at 10 GHz to RX port
    - Verify signal passes through LNA → measure gain ~18 dB with VNA

---

## 4. Phase Shifter Board Assembly

**Note:** This is similar to RF Frontend but simpler (no PA/mixer).**

1. Same process as RF Frontend but focus on HMC647A placement
2. **Critical: SPI daisy-chain routing** — verify during layout that U16 DATA_OUT connects to U15 DATA_IN, etc.
3. **Test SPI communication before installing in system:**
   - Connect SPI to STM32 Nucleo eval board (easier access)
   - Send SPI transaction: 16 bytes = [0x10, 0x10, 0x10, 0x10, 0x10, 0x10, 0x10, 0x10, 0x10, 0x10, 0x10, 0x10, 0x10, 0x10, 0x10, 0x10]
   - This sets all 16 shifters to code 0x10 = 90°
   - Verify with VNA that phase changes at each output
4. Build two identical boards: one for TX, one for RX

---

## 5. Common Assembly Issues and Solutions

| Issue | Symptom | Solution |
|---|---|---|
| QFN bridge | Short circuit between adjacent pins | Hot air rework, add flux, reflow gently. Wick excess solder. |
| QFN opens | IC doesn't respond to SPI | X-ray to check solder voids under pad. Hot air reflow with more paste if possible. |
| LQFP bridge | Two adjacent pins shorted | Fine-tip iron with flux. Cut solder ball between pins with scalpel. |
| Component tombstone | Passive component standing up on one end | Usually means paste imbalance. Reflow at higher temperature or more balanced paste. |
| Rogers PCB warped | Substrate not flat | Bake at 120°C for 30 min before assembly. Use fixture during reflow. |
| SMA misaligned | High return loss after installation | Remove and reinstall with better fixture. Torque to spec (0.45 N·m for 2.92mm). |

---

## 6. Torque Specifications

| Connector | Torque | Wrench size |
|---|---|---|
| SMA female-female | 0.56 N·m (5 lb·in) | 5/16" open-end |
| 2.92mm K-connector | 0.45 N·m (4 lb·in) | 7/16" open-end |
| SMA to SMA (inline) | 0.56 N·m | 5/16" |
| XT60 mounting screws | 0.50 N·m | M3 hex key |

⚠️ **NEVER** overtighten 2.92mm connectors. They are machined to fine tolerance and easily destroyed.

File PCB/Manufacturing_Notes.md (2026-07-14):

# AERIS-10P PCB Manufacturing Notes
## Rev 1.0 — 2026-07-14

---

## Board Specifications Summary

| Board | Size | Layers | Substrate | Min Trace | Copper | Finish | Supplier |
|---|---|---|---|---|---|---|---|
| Main Control | 160×100 mm | 4 | FR4 | 0.15 mm | 1 oz | ENIG | JLCPCB |
| RF Frontend | 100×60 mm | 4 | Rogers RO4003C | 0.10 mm | 1 oz | ENIG | PCBWay |
| Power Board | 100×80 mm | 2 | FR4 | 0.20 mm (power) | 2 oz | HASL | JLCPCB |
| Phase Shifter | 120×80 mm | 4 | Rogers/FR4 hybrid | 0.10 mm | 1 oz | ENIG | PCBWay |
| Antenna Panel | 200×120 mm | 2 | Rogers RO4003C | 1.08 mm | 1 oz | ENIG | PCBWay |

---

## 1. AERIS Main Control Board (160×100 mm)

**Stackup (4-layer FR4):**
- Layer 1: Signal (components top)
- Layer 2: Ground (solid copper, RF shield)
- Layer 3: Power (+3.3V, +5V planes)
- Layer 4: Signal (bottom, digital routes)

**Specifications:**
- Board thickness: 1.6 mm
- Copper weight: 1 oz (35 µm)
- Min trace/space: 0.15/0.15 mm
- Min hole drill: 0.25 mm
- Min annular ring: 0.15 mm
- Surface finish: ENIG (immersion gold)
- Solder mask: green, both sides
- Silkscreen: white, both sides
- IPC Class 2

**Critical layout rules:**
- USB D+/D- traces: differential pair, 90Ω impedance (2.5 mm separation), max 50 mm length
- SPI traces: match length within group ±5 mm
- Crystal traces (OCXO): keep short (<20 mm), no other signals crossing underneath
- Decoupling caps: place within 0.5 mm of IC power pins
- Thermal relief: use solid connections on ground plane for RF ICs

**Test points:** Add test point pads (1mm) for: 5V, 3.3V, GND, SPI_SCK, USB_DP, USB_DM, NRST, ADF4159_LOCK

---

## 2. AERIS RF Frontend Board (100×60 mm)

**Stackup (4-layer Rogers RO4003C):**
- Layer 1: RF signal + components
- Layer 2: Ground (solid copper, RF ground plane)
- Layer 3: Power (5V, 3.3V supplies)
- Layer 4: Signal (SPI, control)

**Substrate specification:**
- Rogers RO4003C, 0.508 mm
- εr = 3.55 ± 0.05
- tan δ = 0.0027 at 10 GHz
- Copper: 1 oz (35 µm) electrodeposited
- Board thickness with prepreg: ~1.0 mm

**Critical RF specifications:**
- 50Ω microstrip trace width: 1.08 mm (on 0.508 mm RO4003C, εr=3.55)
- Tolerance on trace width: ±0.05 mm (controlled impedance order!)
- All RF traces must be 50Ω microstrip — specify controlled impedance 50Ω ±10%
- Minimum bend radius: 2× trace width (2.2 mm)
- Via fence: ground vias every 3 mm along all RF traces, 0.3 mm drill, 0.6 mm pad
- No 90° bends — use 45° or radius bends only
- Keep RF traces on Layer 1 only; no RF signals on other layers
- SMA connector footprints: verify manufacturer pad dimensions before layout

**Ordering notes:**
- Supplier: PCBWay (supports Rogers RO4003C, impedance control)
- Specify: "Controlled impedance 50Ω ±10% on layer 1"
- Specify: "Rogers RO4003C 0.508mm substrate, not FR4"
- Lead time: 2–4 weeks
- Price: ~$120 per board, order minimum 2

**Inspection requirements:**
- Impedance test coupon on board edge (order extra space for TDR coupon)
- Visual inspection of copper voids under QFN pads
- X-ray inspection of HMC647A, HMC1040, HMC213B solder joints recommended

---

## 3. AERIS Power Board (100×80 mm)

**Stackup (2-layer FR4):**
- Layer 1: Power supply components, wide traces
- Layer 2: Ground plane (solid copper)

**Critical layout rules:**
- Input 24V trace: minimum 3 mm width for 8A
- Output 5V trace: minimum 2 mm for 5A
- Star ground: all supply returns meet at single point near input capacitor
- LT8612 switching node (SW pin): minimize loop area between SW, L1, C_out
- LT8612 bootstrap cap: within 1 mm of BST pin
- LM7812: large copper thermal pad on layer 1 and 2, add external heatsink mount hole
- LED current resistors: near LEDs (reduce stray current in small traces)
- Bulk capacitor C1 (1000µF): as close to XT60 input as possible

**DRC rules:** 0.2 mm min clearance (power board has high currents, wider clearance safer)

---

## 4. AERIS Phase Shifter Board (120×80 mm)

**Stackup (4-layer hybrid Rogers/FR4):**
- Layer 1: Rogers RO4003C 0.508 mm (RF signal)
- Core 1: FR4 prepreg (structural)
- Layer 2: Ground (solid copper)
- Core 2: FR4 prepreg
- Layer 3: Power (+5V plane)
- Core 3: FR4 prepreg
- Layer 4: FR4 (SPI control signals)

Note: Ask PCBWay for Rogers/FR4 hybrid stackup. They offer this as "Rogers mixed" option. Layer 1 uses Rogers, remaining layers FR4.

**Critical specifications:**
- 50Ω on Layer 1 (Rogers): trace width 1.08 mm
- Component vias through all 4 layers: 0.3 mm drill
- RF via fence: 0.3 mm drill, 0.6 mm pad, every 5 mm
- HMC647A (5×5mm QFN-32): thermal pad must be soldered to ground plane via multiple vias
- Power distribution: 2mm trace for 5V supply line feeding all 16 ICs (1.44A total)

---

## 5. AERIS Antenna Panel (200×120 mm)

**Construction:**
- Rogers RO4003C, 0.508 mm, 2-layer
- Layer 1: Patch antennas, feed lines, Wilkinson dividers
- Layer 2: Continuous ground plane (no cuts)

**Patch element specifications:**
- Patch dimensions: L=13.8 mm, W=8.0 mm (verify with EM simulation)
- Feed point: inset microstrip at y0=3.4 mm from patch edge
- Feed line width: 1.08 mm (50Ω)
- Element spacing: 15 mm center-to-center (λ/2)
- Patch copper: 1 oz electrodeposited
- Ground plane: 1 oz, solid copper

**Ordering:**
- Surface finish: ENIG (immersion gold) — important for RF performance
- Do NOT use HASL (bumps on pads affect patch resonance)
- Via fencing on ground plane perimeter
- Supplier: PCBWay, specify "Rogers RO4003C 0.508mm, ENIG"

---

## 6. Gerber File Export from EasyEDA

1. Open schematic → click PCB view
2. Complete layout, run DRC
3. File → Export → Gerber (PCB Fabrication File)
4. Select: Include Drill File, Copper layers (all), Soldermask, Silkscreen, Board outline
5. Verify: Open Gerber in GerbView or KiCad Gerber Viewer before ordering
6. Check: All component footprints present, board outline closed, drill file matches pads
7. Upload to PCBWay or JLCPCB as .zip archive

---

## 7. Component Ordering Notes for PCB Assembly

If ordering with SMT assembly (PCBWay assembly service or JLCPCB):
- Export BOM from EasyEDA as CSV
- Match Mouser/LCSC part numbers in BOM
- Flag QFN packages as "difficult — requires X-ray inspection"
- Specify "no-clean flux" for RF boards
- RF connectors (SMA, 2.92mm): order separately, install after reflow

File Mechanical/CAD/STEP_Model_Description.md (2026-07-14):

# AERIS-10P STEP Model Documentation
## 3D CAD Reference for Manufacturing — Rev 1.0

---

## Overview

This document describes all 3D CAD models in the AERIS-10P mechanical design.
STEP files (.step / .stp) can be opened in: FreeCAD (free), Fusion 360, SOLIDWORKS, CATIA, OpenSCAD.

The `generate_stl.py` script (in this directory) generates STL files for 3D printing.
For CNC machining or professional manufacturing, convert STL→STEP using FreeCAD or Fusion 360.

---

## File Index

| Filename | Description | Dimensions | Material |
|---|---|---|---|
| `main_enclosure.step` | Electronics enclosure | 300×200×100 mm | 6061-T6 Al or PETG |
| `antenna_panel.step` | Antenna array mount plate | 200×120×5 mm | FR4 / Aluminium |
| `tripod_mount_adapter.step` | Camera-tripod interface | 100×80×68 mm | 6061-T6 Al |
| `electronics_tray.step` | PCB mounting tray | 280×180×12 mm | 6061-T6 Al or PETG |
| `cooling_fan_bracket.step` | 80mm fan mount | 80×80×4 mm | PETG |
| `front_panel.step` | Front panel with cutouts | 300×100×5 mm | 6061-T6 Al |

---

## 1. Main Enclosure

```
┌──────────────────────────────────────────────────────────────────────┐
│                         MAIN ENCLOSURE                                │
│                    300mm × 200mm × 100mm                              │
│                                                                        │
│  Front face (300×100mm):                                              │
│  ┌────────────────────────────────────────────────────┐               │
│  │ [ANT ●] [TX ●] [RX ●] [IF ●]  [USB □] [RJ45 □]  │               │
│  │  SMA×4   debug        monitor                       │               │
│  │                                              [PWR○] │               │
│  │  [POWER XT60]                                [LED○] │               │
│  └────────────────────────────────────────────────────┘               │
│  ↑ 100mm                                              ↑               │
│                                                                        │
│  Bottom face: 4× rubber feet (M5 stud, 10mm diameter)                │
│  Side faces: ventilation slots (machined or 3D printed)              │
│  Rear face: blank (or cable gland for 24V input alternative)          │
│  Top face: removable lid, 4× M3 fasteners at corners                 │
│                                                                        │
└──────────────────────────────────────────────────────────────────────┘
```

### Detailed Dimensions

```
Outer dimensions:    W=300mm, D=200mm, H=100mm
Wall thickness:      3mm (aluminium) or 4mm (PETG)
Lid thickness:       2mm (aluminium) or 3mm (PETG)

Front panel cutouts:
  SMA female (×4):   D=6.2mm through-hole, on 15mm grid
  USB micro-B:       rectangular 8.0mm×3.5mm, centered at H=20mm from bottom
  RJ45:              rectangular 16.0mm×14.5mm
  XT60 female:       rectangular 12.5mm×7.5mm
  LED indicators:    D=5.1mm through-hole (×2, green/red)
  Power switch:      rectangular 20mm×13mm (rocker switch)

Electronics tray mounting: 4× M3 threaded inserts, 5mm deep, at 250×160mm grid
Lid hinge: none — lift-off lid with 4× M3 countersunk screws at corners
  (or alternative: continuous hinge on rear edge)

Ventilation:
  Side wall slots: 5× slots, 60mm×3mm, spaced 15mm apart, centered vertically
  Fan mounting: 80mm circular opening on rear face (for push-through airflow)

Weight (aluminium): ~320g
Weight (PETG 30% infill): ~180g

Tripod mount interface: 1/4"-20 UNC blind hole, 8mm deep, at center of bottom face
  Alternative: 3/8"-16 UNC (for heavier tripods) with 1/4"-20 adaptor insert
```

### FreeCAD Modeling Instructions

To create this part in FreeCAD:
1. Open FreeCAD → Part Design workbench
2. Create a new sketch on XY plane: rectangle 300×200mm
3. Pad: 100mm
4. Shell: 3mm (removes inner material)
5. Create pocket for front panel cutouts using further sketches
6. Fillet all outer edges: R=2mm
7. Add M3 threaded hole features (M3×0.5, 8mm depth) at corner positions
8. Export: File → Export → .STEP (ISO 10303-214)

---

## 2. Antenna Panel

```
┌──────────────────────────────────────────────────────────────────────┐
│                       ANTENNA PANEL                                   │
│                    200mm × 120mm × 5mm                                │
│                                                                        │
│  Front face (mounted outward, toward target):                         │
│                                                                        │
│  TX Array (4×4 patches)   |   RX Array (4×4 patches)                 │
│  ┌───────────────────────┐│┌───────────────────────┐                 │
│  │ ○  ○  ○  ○           │││           ○  ○  ○  ○ │                 │
│  │                        │││                        │                 │
│  │ ○  ○  ○  ○           │││           ○  ○  ○  ○ │                 │
│  │   (patch elements)     │││   (patch elements)     │                 │
│  │ ○  ○  ○  ○           │││           ○  ○  ○  ○ │                 │
│  │                        │││                        │                 │
│  │ ○  ○  ○  ○           │││           ○  ○  ○  ○ │                 │
│  └───────────────────────┘│└───────────────────────┘                 │
│         45mm × 45mm array │   45mm × 45mm array                       │
│         (3λ/2 × 3λ/2)     │                                          │
│  ←    90mm TX section     │   90mm RX section      →                 │
│                                                                        │
│  Back face: 16× 2.92mm SMA launch pads per array section             │
│             = 32 total connector pads                                  │
│             Mount holes: 6× M3 through-holes at periphery             │
│                                                                        │
└──────────────────────────────────────────────────────────────────────┘
```

### Detailed Dimensions

```
Total panel: 200mm (W) × 120mm (H) × 5mm (substrate)
  Note: "panel" is actually the Rogers RO4003C PCB itself + aluminium backing plate

Rogers RO4003C PCB: 200mm × 120mm × 0.508mm (substrate)
Aluminium backing plate: 200mm × 120mm × 4.5mm (for rigidity)

TX array center: at X=45mm, Y=60mm (from left edge, centered vertically)
RX array center: at X=155mm, Y=60mm

Element positions (TX, element [row,col]):
  [0,0]: X=22.5mm, Y=37.5mm
  [0,1]: X=37.5mm, Y=37.5mm
  [0,2]: X=52.5mm, Y=37.5mm
  [0,3]: X=67.5mm, Y=37.5mm
  [1,0]: X=22.5mm, Y=52.5mm
  ... (15mm step in each direction)
  [3,3]: X=67.5mm, Y=82.5mm

SMA feed connector positions: on rear face, aligned with each element feed point
  2.92mm SMA edge-launch connectors with 1.2mm hole diameter

Mount holes: 6× M3 through-holes
  At (10,10), (100,10), (190,10), (10,110), (100,110), (190,110) mm
```

---

## 3. Tripod Mount Adapter

```
Side view:                          Front view:
                                    
     ┌─────────────────────┐        ┌──────────────────────┐
     │    Base Plate       │        │     80mm × 68mm      │
     │    100mm × 8mm      │        │                      │
     │                     │        │    ○         ○       │
     └──────────┬──────────┘        │      (M5 holes)     │
                │                   │    ○         ○       │
                │ 8mm × 60mm        │                      │
                │ upright           └──────────────────────┘
                │
     ┌──────────┴──────────┐
     │   Enclosure mount   │
     │   80mm × 8mm × 60mm │
     │                     │
     │   M5 bolt here      │
     │   (to enclosure     │
     │    bottom)          │
     │                     │
     │   1/4"-20 nut       │
     │   recessed 5mm deep │
     │   (tripod thread)   │
     └─────────────────────┘
```

### Detailed Dimensions

```
Base plate:   100mm (L) × 80mm (W) × 8mm (H)
Upright:      80mm (W) × 8mm (D) × 60mm (H)
Total height: 68mm (8mm base + 60mm upright)

Tripod interface: 1/4"-20 UNC hex nut pressed into recess at base center
  Recess depth: 5mm, hex across-flats: 11.1mm
  Alternatively: 3/8"-16 UNC insert option

Enclosure attachment:
  4× M5 through-holes in base plate, at 80×60mm grid (matching enclosure bottom)
  M5 hex button-head socket screws from below

Upright-to-enclosure attachment:
  4× M3 through-holes in upright, at 60×40mm grid
  M3 hex socket screws → threaded inserts in enclosure bottom

Tilt mechanism (optional upgrade):
  Center pivot hole D=8mm for M8 bolt, allows ±30° tilt
  Clamping nut on M8 bolt locks angle

Material: 6061-T6 aluminium, 2.5mm anodize coat (black)
Weight: ~120g

3D Print alternative (PETG):
  Print upright and base as separate parts, join with M3 bolts
  Add steel M5 threaded inserts for durability
```

---

## 4. Electronics Tray

```
Top view (inside enclosure):

  ┌──────────────────────────────────────────────────────────────────┐
  │                     ELECTRONICS TRAY                              │
  │                   280mm × 180mm × 12mm                            │
  │                                                                    │
  │  ●    ●    ●    ●   ← M3 PCB standoffs (4mm height)             │
  │  [  Power Board  ]   [    Main Control Board    ]                 │
  │   100×80mm           160×100mm                                    │
  │                                                                    │
  │  ●    ●    ●    ●                                                 │
  │  [RF Frontend Bd]   [ Phase Shifter Board ]                       │
  │   100×60mm           120×80mm                                     │
  │                                                                    │
  │  ●    ●    ●    ●   ← M3 PCB standoffs                          │
  │                                                                    │
  │   [Fan mount ●]      [Raspberry Pi 5   ]                         │
  │                       85×56mm (standard Pi)                       │
  │                                                                    │
  └──────────────────────────────────────────────────────────────────┘
  
  Overall tray: 280mm × 180mm × 12mm base + 4mm standoffs = 16mm total height
  Tray mounting: 4× M3 screws into enclosure walls at 270×170mm grid
  PCB mounting: M3 threaded inserts in tray, 4mm brass standoffs
  Cable management: 6× cable routing slots (5×20mm) around perimeter
```

### Detailed Dimensions

```
Base plate: 280mm × 180mm × 3mm (aluminium or PETG)
Rim: 12mm total height (9mm side walls on 3 sides, open front)
PCB standoffs: M3×0.5 threaded, 4mm height, positions per board layout

PCB mounting positions:
  Power Board (100×80mm):     Bottom-left, PCB at (10,10) to (110,90)
  Main Control Board (160×100mm): Top area, PCB at (120,10) to (280,110)
  RF Frontend (100×60mm):     Bottom-center, PCB at (10,100) to (110,160)
  Phase Shifter (120×80mm):   Bottom-right, PCB at (140,100) to (260,180)
  Raspberry Pi (85×56mm):     Right area, PCB at (185,50) to (270,106)

Standoff positions: 4 per board, M3×0.5 threaded insert in tray
  3D printed version: print M3 hex holes, press in M3 threaded inserts

Material: 6061-T6 aluminium (preferred) or PETG (prototype)
```

---

## 5. Front Panel

```
┌──────────────────────────────────────────────────────────────────────┐
│              FRONT PANEL    300mm × 100mm × 5mm                      │
│                                                                        │
│  [═══════════ AERIS-10P ══════════════════════════════════════════]   │
│  │                                                                  │  │
│  │  SMA×4           USB-B  ETH    XT60   PWR-SW  LED1  LED2       │  │
│  │  (RF ports)                    (24V)                            │  │
│  │  ○○○○          □      □□□□   [==]   (○)   (●)   (●)          │  │
│  │                                                                  │  │
│  │  ← 10 → ← 30 → ← 20 → ← 20 → ← 25 → ← 20 → ← 20 → (mm)    │  │
│                                                                        │
└──────────────────────────────────────────────────────────────────────┘
```

### Cutout Dimensions

```
Overall: 300mm × 100mm × 5mm
Mount holes: 4× M3 through-holes at corners (5mm from edge each)

Connector cutouts (from left edge, centered at H=50mm):
  SMA female (×4):   4× D=6.35mm holes, spaced 15mm, first at X=25mm
  USB micro-B:       at X=110mm, 11mm×8mm rectangle
  RJ45:              at X=150mm, 17mm×15mm rectangle
  XT60 female:       at X=185mm, 13mm×8mm rectangle
  Power switch:      at X=220mm, 22mm×15mm rectangle
  LED green (OK):    at X=255mm, D=5.2mm hole
  LED red (TX):      at X=275mm, D=5.2mm hole
  
Label engraving (or printed label):
  "AERIS-10P" centered at top
  Each connector labeled below cutout
  "10 GHz FMCW RADAR" below main label
  "RF RADIATION HAZARD" warning triangle near SMA ports

Finish:
  Aluminium: black anodize, white silk-screen labels
  PETG: black filament, heat-press label insert
```

---

## Manufacturing Notes

### Option A: CNC Machined Aluminium (Production Quality)

- Material: 6061-T6 aluminium
- Finish: Type II anodize, black (for RF shielding and aesthetics)
- Tolerance: ±0.1mm general, ±0.05mm for RF connector holes
- Supplier: Proto Labs, Fictiv, or local machine shop
- Estimated cost per piece: $120–$250 depending on complexity
- Lead time: 5–10 business days

### Option B: 3D Printed PETG (Prototype Quality)

- Material: PETG, 30% infill, 0.2mm layer height, 4 perimeters
- Print orientation: largest flat face down (minimize supports)
- Threaded features: use M3 heat-set inserts (press in with soldering iron at 200°C)
- Finish: optional spray paint (Krylon Fusion, black)
- Estimated cost per piece: $5–$15 (material)
- Lead time: 4–8 hours per piece on FDM printer (Prusa MK4, Bambu X1)

### Option C: Laser-Cut Sheet Metal (Panel Version)

- Material: 1.5mm or 2mm steel sheet
- Process: laser cut + CNC bend
- Coating: powder coat, black
- Good for: front panel, simple brackets
- Not suitable for: enclosure (too many features)

### STEP File Generation from FreeCAD

To generate STEP files from scratch:
```python
# In FreeCAD's Python console:
import FreeCAD
import Part

# Create main enclosure box
box = Part.makeBox(300, 200, 100)  # W×D×H in mm
shell_offset = 3  # wall thickness

# Create inner void
inner = Part.makeBox(
    300 - 2*shell_offset,
    200 - 2*shell_offset, 
    100 - shell_offset,
    FreeCAD.Vector(shell_offset, shell_offset, 0)
)

# Shell the box
enclosure = box.cut(inner)

# Export STEP
Part.export([enclosure], "main_enclosure.step")
```

For full parametric modeling, use the FreeCAD Part Design workbench with 
the Spreadsheet workbench for dimensions management.

---

*End of STEP Model Documentation — AERIS-10P Rev 1.0*

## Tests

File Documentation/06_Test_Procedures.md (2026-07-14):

# AERIS-10P Test and Measurement Procedures
## Rev 1.0 — AERIS-10P Affordable Experimental Radar Intelligence System, 10 GHz Phased Array

**Document Number:** AERIS-TP-001  
**Revision:** 1.0  
**Date:** 2026-07-14  
**Author:** RF Systems Engineering  
**Status:** Released  

---

## 1. Scope and Purpose

This document defines the complete test and measurement procedures for the AERIS-10P phased-array FMCW radar system. All tests must be performed in the sequence specified. Each test phase builds on the verified results of the previous phase. No phase may be skipped; any failure must be resolved and the failing test repeated before proceeding.

The AERIS-10P operates in the X-band amateur allocation 10.000–10.500 GHz (German AFuG 2017 / AFuV 2017, Klasse A license). All measurements involving radiated power must comply with the 75 W PEP limit and the DARC 3 cm band plan. A valid amateur radio license (Klasse A) must be held by the operator or a licensed operator must be present during any radiated tests.

---

## 2. Test Equipment

The following calibrated instruments are required. All instruments must have valid calibration certificates traceable to national standards (PTB or equivalent). Calibration status must be verified before commencing any test phase.

| Item | Instrument | Model | Frequency / Range | Notes |
|---|---|---|---|---|
| VNA | Vector Network Analyzer | Keysight E5080B or R&S ZVA40 | 100 kHz – 20 GHz (ZVA40) / 9 GHz (E5080B) | 2-port minimum; 4-port preferred for array work |
| SA | Spectrum Analyzer | R&S FSP40 or Keysight N9020B | 3 Hz – 40 GHz | Pre-amplifier required for noise figure work |
| PM | Power Meter | Keysight E4418B (or HP 437B) | — | With 8481A (10 MHz–18 GHz) and 8485A (0.5–26.5 GHz) sensors |
| OSC | Oscilloscope | Keysight MSOX3054T or Tektronix MDO3054 | 500 MHz, 4 Ch | With FFT capability for IF analysis |
| SG | Signal Generator | Keysight E8257D or R&S SMW200A | 10 MHz – 20 GHz | For LO injection and loopback tests |
| NF | Noise Figure Analyzer | R&S FSV-K30 option or Keysight N8975A | 10 MHz – 26.5 GHz | Or use Y-factor with calibrated noise source |
| NS | Noise Source | Keysight 346B | 10 MHz – 18 GHz | ENR ~15 dB at 10 GHz, NIST-traceable cal |
| CR | Corner Reflector | Trihedral, 0.3 m edge length | — | RCS ~10 m² at 10 GHz |
| ATT | Step Attenuator | R&S RSC or HP 355D | DC – 18 GHz | 0–110 dB in 10 dB steps |
| CAL | Calibration Kit | Keysight 85052D (3.5 mm) or 85056D (2.4 mm) | — | SOL or TOSM standard |
| DMM | Digital Multimeter | Fluke 87V or Keysight 34401A | — | 4.5 digit minimum |
| THERM | Thermal Camera or Type-K probe | FLIR E8 or similar | — | For thermal testing |

### 2.1 Cable and Adaptor Inventory

Before starting, assemble and characterize the following test cables:

- 2× 3.5 mm (m) to 3.5 mm (m), phase-stable, 50 cm, ≤0.5 dB loss at 10 GHz
- 2× 2.92 mm (m) to SMA (f) adaptor
- 1× SMA (m) to SMA (m) barrel (for loopback)
- 30 dB SMA attenuator (rated >2 W) for loopback tests

Measure cable insertion loss at 10 GHz with the VNA and record values in the Cable Loss Log. All subsequent power measurements must be corrected for cable loss.

---

## 3. Phase 1 — DC / Power Supply Tests (PT-001 through PT-005)

**Prerequisites:** PCB assembly complete; firmware not required for this phase. All RF ICs must be unpowered or their supply pins left unconnected during supply characterisation.

### PT-001 — Input Voltage Range Test

**Objective:** Verify correct operation of all DC-DC regulators over the specified input voltage range 22–28 V DC.

**Procedure:**
1. Connect a laboratory bench supply (current-limited to 2 A) to the 24 V input terminals. Do not connect any load boards.
2. Set supply to 22.0 V. Enable output. Measure and record the following output voltages with the DMM: +5 V rail, +3.3 V rail, +5 V_RF rail, −5 V_RF rail.
3. Increase supply voltage in 1 V steps to 28.0 V. Record all rail voltages at each step.
4. Return supply to 24.0 V nominal. This is the nominal test voltage for all subsequent tests.

**Pass Criteria:** All output rails remain within their specified tolerance bands (see PT-002) at all input voltages from 22 to 28 V. No output rail shall deviate by more than 0.5% from the 22 V value as input changes from 22 to 28 V (line regulation).

**Data Sheet:** Table PT-001-A (Input Voltage Sweep).

---

### PT-002 — Rail Voltage Accuracy

**Objective:** Verify DC output voltage accuracy at 24 V nominal input and rated load.

**Procedure:**
1. Connect representative resistive loads to each rail to simulate nominal current: +5 V at 3 A (resistor ≈ 1.67 Ω / 15 W), +3.3 V at 2 A (1.65 Ω / 7 W), +5 V_RF at 0.5 A (10 Ω / 2.5 W), −5 V_RF at 0.5 A.
2. Allow 5 minutes for temperatures to stabilise.
3. Measure each rail voltage at the load resistor terminals with calibrated DMM.

**Pass Criteria:**

| Rail | Nominal | Tolerance | Min | Max |
|---|---|---|-----|-----|
| +5 V (LT8612) | 5.000 V | ±2% | 4.900 V | 5.100 V |
| +3.3 V (LT8607) | 3.300 V | ±1.5% | 3.251 V | 3.350 V |
| +5 V_RF (TPS65133) | 5.000 V | ±3% | 4.850 V | 5.150 V |
| −5 V_RF (TPS65133) | −5.000 V | ±3% | −5.150 V | −4.850 V |

---

### PT-003 — Ripple and Noise Measurement

**Objective:** Measure DC-DC converter output ripple and noise to verify it does not degrade RF performance.

**Procedure:**
1. Connect oscilloscope probe (AC-coupled, 20 MHz bandwidth limit OFF) directly at the output capacitor of each DC-DC converter.
2. Set scope timebase to 50 µs/div to capture switching frequency (LT8612 and LT8607 switch at ~2 MHz).
3. Measure peak-to-peak ripple voltage.
4. Change scope to 10 MHz bandwidth limit; measure residual noise floor.

**Pass Criteria:** Peak-to-peak ripple ≤50 mV on +5 V; ≤30 mV on +3.3 V; ≤20 mV on ±5 V RF rails. Noise floor ≤5 mV RMS on RF rails.

---

### PT-004 — Efficiency Measurement

**Objective:** Measure power supply conversion efficiency at nominal load.

**Procedure:**
1. With loads from PT-002 connected, measure:
   - Input power: P_in = V_in × I_in (use DMM for V, clamp meter or shunt resistor for I)
   - Output power: P_out = sum of (V_rail × I_rail) for all rails
2. Calculate efficiency: η = P_out / P_in × 100%

**Pass Criteria:** Overall efficiency ≥80% at nominal 24 V input and nominal load.

---

### PT-005 — Thermal Test

**Objective:** Verify that no component exceeds its maximum rated junction temperature during 30 minutes of continuous operation at rated load.

**Procedure:**
1. Apply rated loads from PT-002. Apply 24 V input. Allow system to run for 30 minutes in still air (no forced cooling, no heatsink — baseline measurement).
2. At t = 30 minutes, measure case temperature of each DC-DC IC with thermocouple or thermal camera. Record ambient air temperature.
3. Calculate estimated junction temperature: T_j = T_case + (P_dissipated × θ_jc) for each device.
4. Repeat with 80 mm cooling fan operational.

**Pass Criteria:** No IC case temperature shall exceed 85°C in still air; ≤70°C with fan at rated 24 V load and 25°C ambient. LT8612 maximum T_j = 125°C; LT8607 maximum T_j = 125°C; TPS65133 maximum T_j = 150°C.

---

## 4. Phase 2 — VCO / PLL Tests (PT-010 through PT-015)

**Prerequisites:** Phase 1 complete (all rails verified). STM32H743 firmware loaded (PLL configuration firmware v0.1 or later). ADF4159CCPZ and HMC733LP6CE populated.

### PT-010 — ADF4159 Lock Detect Verification

**Objective:** Confirm that the ADF4159 PLL achieves and maintains frequency lock.

**Procedure:**
1. Power up the RF front-end board (apply 5 V and 3.3 V to the board).
2. Connect OCXO-10 MHz (ABRACON AOCJY-10) reference to the ADF4159 REF_IN pin.
3. Verify OCXO output level at REF_IN: should be 0 dBm ±3 dBm into 50 Ω.
4. Program the ADF4159 via SPI (STM32 firmware command `PLL_INIT`) for CW output at 10.050 GHz.
5. Measure the MUXOUT/LD pin voltage. In lock-detect mode, this pin should read >2.5 V (logic high) when locked.
6. Verify lock is maintained by holding the measurement for 60 seconds.
7. Program through the sweep range: 10.000 GHz, 10.025 GHz, 10.050 GHz, 10.075 GHz, 10.100 GHz. Verify lock at each frequency.

**Pass Criteria:** LD pin HIGH (>2.5 V) within 5 ms of any frequency change. Lock maintained for ≥60 s at each frequency. No cycle slips observed on scope during 60 s measurement.

---

### PT-011 — Frequency Accuracy

**Objective:** Verify that the synthesized frequency is within specification across the 10.000–10.100 GHz band.

**Procedure:**
1. Connect the HMC733 output (after buffer, before PA) to the spectrum analyzer input via a calibrated 20 dB attenuator and 2.92 mm cable.
2. Set SA: center 10.050 GHz, span 200 MHz, RBW 1 kHz, VBW 300 Hz, detector peak.
3. Program five CW frequencies: 10.000, 10.025, 10.050, 10.075, 10.100 GHz.
4. At each frequency, use the SA marker function to read the peak frequency. Record both the programmed and measured frequency.
5. Correct for any known SA frequency reference error.

**Pass Criteria:** Measured frequency within ±1 MHz of programmed frequency at all five test points (limited by the 10 MHz OCXO reference accuracy of ±0.01 ppm over temperature, corresponding to ±0.1 Hz error — any larger error indicates reference or PLL configuration issue).

---

### PT-012 — Chirp Linearity Test

**Objective:** Verify that the FMCW chirp is linear over the full 100 MHz bandwidth, chirp time 1 ms.

**Procedure:**
1. Configure ADF4159 for sawtooth FMCW: start frequency 10.000 GHz, stop 10.100 GHz, ramp time 1 ms, PRF 1 kHz.
2. Connect the VCO output to the oscilloscope via a broadband envelope detector (or use a directional coupler and mixer to produce a baseband representation of the instantaneous frequency).
3. Alternative (preferred): connect HMC733 output to a calibrated mixer with a stable CW LO at 10.000 GHz. The IF output (0–100 MHz range) represents the instantaneous frequency deviation. Capture the IF on the oscilloscope at 1 GS/s, 2 ms window.
4. Post-process the IF waveform: use FFT on sliding windows (e.g., 10 µs Hanning window, 1 µs step) to compute the instantaneous frequency as a function of time. Fit a linear regression to the resulting f(t) curve.
5. Calculate residual non-linearity: RMS deviation from the linear fit, expressed in MHz.

**Pass Criteria:** Chirp linearity error ≤1% of chirp bandwidth (≤1 MHz RMS deviation from ideal linear ramp over the 1 ms chirp). The measured sweep rate must be 100 MHz / 1 ms = 100 GHz/s ± 2%.

---

### PT-013 — Phase Noise Measurement

**Objective:** Measure single-sideband (SSB) phase noise of the synthesized carrier.

**Procedure:**
1. Set ADF4159 to CW mode at 10.050 GHz. Connect HMC733 output (via 20 dB attenuator) to SA.
2. Using the SA phase noise measurement function (e.g., R&S FSP Phase Noise option, or use cross-correlation if available): measure L(f) at offsets 10 kHz, 100 kHz, and 1 MHz from carrier.
3. Correct the measurement for attenuator loss. Subtract 3 dB for two-sideband to SSB conversion if required by instrument.
4. Record L(f) in dBc/Hz at each offset frequency.

**Pass Criteria:** L(10 kHz) ≤ −80 dBc/Hz; L(100 kHz) ≤ −95 dBc/Hz; L(1 MHz) ≤ −110 dBc/Hz. (These values are consistent with the ADF4159 + HMC733 combination with 10 MHz OCXO reference.)

---

### PT-014 — Sweep Rate Verification

**Objective:** Confirm that the ADF4159 sawtooth ramp achieves exactly 100 MHz / 1 ms sweep rate.

**Procedure:**
1. Using the IF output from the mixer arrangement in PT-012, measure the time for the IF to sweep from 0 to 100 MHz (i.e., the time for the chirp to cover the full bandwidth) using the oscilloscope time-domain capture.
2. Trigger the oscilloscope on the PRF sync output from the STM32 (RAMP_START GPIO).
3. Measure: T_chirp (time from ramp start to ramp end at 10.100 GHz).
4. Measure: T_retrace (time from ramp end to next ramp start — should be <50 µs to maintain effective PRF).
5. Compute effective sweep rate = 100 MHz / T_chirp.

**Pass Criteria:** T_chirp = 1.000 ms ± 10 µs. Sweep rate = 100.0 GHz/s ± 1.0 GHz/s. T_retrace ≤50 µs.

---

### PT-015 — Spectral Purity

**Objective:** Verify absence of spurious signals within the chirp bandwidth.

**Procedure:**
1. CW mode at 10.050 GHz. SA span 500 MHz, RBW 100 kHz, VBW 30 kHz. Peak search across the band.
2. Identify any spur above the noise floor. Characterise frequency offset, amplitude relative to carrier.

**Pass Criteria:** No spurious signal within the 10.000–10.100 GHz band exceeding −50 dBc. No reference spur at ±10 MHz offset exceeding −60 dBc.

---

## 5. Phase 3 — TX Chain Tests (PT-020 through PT-025)

**Prerequisites:** Phases 1 and 2 complete. HMC451LS6GE PA populated. A 30 dB, 5 W load attenuator must be connected to the TX output at all times during powered tests.

**WARNING:** The TX output delivers up to +30 dBm (1 W). Never connect a power meter, spectrum analyzer, or VNA port directly to the PA output without a sufficient attenuator. Verify attenuator power rating before connecting.

### PT-020 — Output Power Measurement

**Objective:** Verify PA output power at the TX output port.

**Procedure:**
1. Configure system for CW at 10.050 GHz. PA bias applied.
2. Connect: PA output → 30 dB attenuator → power meter (HP 437B + 8485A sensor). Account for cable loss.
3. Measure output power. Enter PA drive level at nominal setting.
4. Sweep frequency from 10.000 to 10.100 GHz in 10 MHz steps. Record power at each step.

**Pass Criteria:** Output power +29 dBm ±1 dB (allowing for measurement uncertainty) at all frequencies 10.000–10.100 GHz. Power flatness ≤1.5 dB across the band.

---

### PT-021 — Harmonic and Spurious Emissions

**Objective:** Verify compliance with spurious emission limits and characterise harmonic content.

**Procedure:**
1. CW at 10.050 GHz. Connect: PA output → 30 dB attenuator → SA. SA span: 500 MHz to 40 GHz.
2. Set RBW 1 MHz, VBW 300 kHz. Peak-search for all signals.
3. Measure absolute level of fundamental and harmonics (20.1 GHz second harmonic, 30.15 GHz third harmonic).
4. Calculate harmonic suppression relative to fundamental.

**Pass Criteria:** Second harmonic ≤ −30 dBc; third harmonic ≤ −40 dBc. All spurious ≤ −40 dBc within 10.000–10.500 GHz band. Compliance with AFuV 2017 spurious emission limits required.

---

### PT-022 — PA Gain Compression (P1dB)

**Objective:** Determine the 1 dB gain compression point of the HMC451LS6GE PA.

**Procedure:**
1. Inject a CW signal at 10.050 GHz from the signal generator into the PA input through a calibrated step attenuator.
2. Measure output power with power meter as a function of input power, sweeping input from −20 dBm to +5 dBm in 1 dB steps.
3. Plot P_out vs P_in. Fit the linear region. Find the input level at which P_out deviates 1 dB below the linear extrapolation.
4. Record P1dB_in and P1dB_out.

**Pass Criteria:** P1dB_out ≥ +28 dBm (HMC451LS6GE datasheet specifies +29 dBm; 1 dB margin allowed for board losses). Nominal gain = P_out − P_in in linear region should be 28 dB ± 2 dB.

---

### PT-023 — Phase Shifter Characterisation

**Objective:** Verify that each HMC647ALP5E 6-bit digital phase shifter covers the full 360° range with adequate resolution and accuracy.

**Procedure:**
1. Connect VNA port 1 to the phase shifter input (SMA), VNA port 2 to the phase shifter output.
2. Configure VNA: S21 measurement, frequency 10.000–10.100 GHz, 101 points.
3. For each phase shifter on the array (16 TX elements): sweep all 64 phase codes (0x00 through 0x3F) via SPI command from STM32. Record S21 magnitude and phase at 10.050 GHz for each code.
4. Compute: phase vs code (should be linear, 360°/64 ≈ 5.625° per step). Compute RMS phase error (deviation from ideal linear relationship). Compute insertion loss variation across phase states.

**Pass Criteria:** Phase range ≥350° (full 360° nominally, ≥350° allowed for boundary states). Phase step accuracy ≤1° RMS per step versus ideal. Insertion loss variation ≤1 dB across all 64 states (HMC647A specified ≤1 dB). Maximum insertion loss (worst state) ≤7 dB at 10 GHz.

---

### PT-024 — TX Antenna Port Impedance (S11)

**Objective:** Verify TX output port impedance matching.

**Procedure:**
1. VNA 2-port TOSM calibration at the TX output SMA connector reference plane.
2. Connect PA output (at rated bias, PA active) to VNA port 1 via 30 dB coupler/attenuator arrangement to protect VNA.
3. Measure S11 from 9.5–10.5 GHz. 

**Pass Criteria:** Return loss ≥15 dB (S11 ≤ −15 dB) at 10.000–10.100 GHz.

---

### PT-025 — TX Chain Gain Budget Verification

**Objective:** Verify the end-to-end TX gain chain: VCO → PA → antenna feed.

**Procedure:**
1. Measure S21 of: VCO buffer output → phase shifter → PA → feed cable → antenna SMA port.
2. Total chain gain = PA gain (28 dB) − phase shifter loss (~6 dB) − cable loss (~1 dB) = ~21 dB.
3. Record gain at CW 10.050 GHz and across 10.000–10.100 GHz.

**Pass Criteria:** End-to-end TX gain within ±2 dB of budget value. Variation across band ≤2 dB.

---

## 6. Phase 4 — RX Chain Tests (PT-030 through PT-035)

**Prerequisites:** Phase 3 complete. HMC1040LP4E LNA and HMC213B mixer populated with correct bias.

### PT-030 — LNA Gain (S21)

**Objective:** Measure HMC1040LP4E LNA gain.

**Procedure:**
1. 2-port VNA calibration at the LNA input and output SMA reference planes.
2. Measure S21 from 8–12 GHz, 101 points, at nominal LNA bias (typically 3 V drain, 100 mA quiescent or per datasheet).
3. Record gain and bandwidth.

**Pass Criteria:** S21 ≥ 17 dB at 10.050 GHz (HMC1040 specifies 18 dB ± 1 dB). Flatness ≤1.5 dB across 10.000–10.100 GHz. Input return loss S11 ≥10 dB.

---

### PT-031 — Noise Figure (Y-Factor Method)

**Objective:** Measure system noise figure of the RX front end (LNA + Mixer).

**Procedure:**
1. Connect calibrated noise source (Keysight 346B, ENR known at 10 GHz) to LNA input.
2. Connect LNA output through mixer (LO at 9.950 GHz) to IF port (100 MHz IF) to SA noise figure personality (or noise figure meter).
3. Perform Y-factor measurement: record noise power with noise source ON and OFF.
4. Y = P_on / P_off (linear). NF = ENR / (Y − 1).
5. Measure NF at 10.000, 10.050, 10.100 GHz.

**Pass Criteria:** LNA NF ≤ 2.0 dB at 10.050 GHz (HMC1040 specified 1.5 dB; 0.5 dB allowed for board parasitics and connector loss). Total RX chain NF (LNA + mixer) ≤ 4.5 dB. System NF (including all RX components) ≤ 8 dB.

---

### PT-032 — Mixer Conversion Loss

**Objective:** Measure HMC213B double-balanced mixer conversion loss.

**Procedure:**
1. Apply LO: 10.000 GHz, +10 dBm from signal generator to LO port.
2. Apply RF: 10.050 GHz, −20 dBm (well below LNA compression) to RF port.
3. Expected IF: 50 MHz.
4. Measure IF output power at 50 MHz with SA (RBW 100 kHz).
5. Conversion loss = P_RF − P_IF (all in dBm, corrected for cable losses).
6. Sweep RF from 10.000 to 10.100 GHz (IF from 0 to 100 MHz).

**Pass Criteria:** Conversion loss ≤7 dB at 10.050 GHz (HMC213B specified ~6 dB ± 1 dB). Conversion loss variation ≤1.5 dB across 0–100 MHz IF bandwidth.

---

### PT-033 — IF Output Frequency Verification

**Objective:** Verify that beat frequencies produced by the FMCW system are within the ADC input range and FFT analysis window.

**Procedure:**
1. Connect a delay line (coax cable, known electrical length) from the TX output (through 60 dB of attenuation) back into the RX input to simulate a target at a known range.
2. Delay line of 20 ns represents range = c × τ / 2 = 3 m.
3. Configure system in FMCW mode. Measure IF output with SA. Verify beat frequency = (sweep rate) × delay = 100 GHz/s × 20 ns = 2 kHz.
4. Vary delay line length and verify that beat frequency scales correctly.

**Pass Criteria:** Measured beat frequency within ±5% of calculated value for all tested delay lengths. IF signal visible at ADC output in software FFT.

---

### PT-034 — ADC Full-Scale Calibration

**Objective:** Calibrate the ADS8661IRGAT ADC and verify dynamic range.

**Procedure:**
1. Apply a known sine wave from the signal generator at 50 kHz, 0 dBm (adjusted to match ADC input range, nominally 0–5 V differential) to the ADC input.
2. Capture 1024 samples at 1 MSPS via SPI into STM32 buffer.
3. Compute FFT. Measure fundamental amplitude and noise floor.
4. Compute SNR and ENOB: ENOB = (SNR − 1.76) / 6.02.
5. Sweep input amplitude from −60 dBFS to 0 dBFS and verify linearity.

**Pass Criteria:** ENOB ≥ 14 bits at 50 kHz input (ADS8661 specified SNR = 91 dB → ENOB = 14.8 bits). No missing codes over full-scale range.

---

### PT-035 — RX Chain Gain Budget Verification

**Objective:** Verify end-to-end RX chain gain from antenna SMA port to ADC input.

**Procedure:**
1. Apply known CW at 10.050 GHz, −50 dBm to the RX antenna SMA port.
2. Measure the IF output level at the ADC input.
3. Total expected RX chain gain: LNA (+18 dB) − Mixer conversion loss (−6 dB) + IF amplifier stages (as designed) = target ADC input level −20 to −3 dBFS for a −50 dBm RF input.

**Pass Criteria:** ADC input level within ±3 dB of expected value calculated from gain budget.

---

## 7. Phase 5 — Antenna Array Tests (PT-040 through PT-045)

**Prerequisites:** Antenna panel assembly complete. Rogers RO4003C PCB, immersion gold finish, SMA connectors soldered.

### PT-040 — Individual Element S11

**Objective:** Verify impedance matching of each of the 32 patch antenna elements (16 TX, 16 RX).

**Procedure:**
1. VNA 1-port calibration at the SMA connector reference plane (OSL or TOSM).
2. Terminate all other antenna ports with 50 Ω loads.
3. For each of the 32 elements, measure S11 from 9.5–10.5 GHz, 201 points.
4. Extract: resonant frequency (minimum S11), return loss at 10.050 GHz, −10 dB bandwidth.

**Pass Criteria:** Return loss ≥15 dB at 10.050 GHz for all 32 elements. Resonant frequency 10.050 ± 50 MHz. Element-to-element resonant frequency variation ≤30 MHz. (Patch dimensions: 13.8 mm × 13.8 mm on RO4003C, εr = 3.55.)

---

### PT-041 — Element-to-Element Isolation

**Objective:** Measure coupling between adjacent TX elements and between TX and RX arrays.

**Procedure:**
1. 2-port VNA. Connect port 1 to element under test, port 2 to adjacent element. Terminate all other elements in 50 Ω.
2. Measure S21 at 10.050 GHz for: nearest neighbour (15 mm spacing), diagonal neighbour, TX element to nearest RX element.
3. Record isolation values.

**Pass Criteria:** Adjacent element isolation ≥20 dB. TX-to-RX array isolation ≥30 dB at 10.050 GHz.

---

### PT-042 — Phase Coherence Across Array

**Objective:** Verify that all array elements exhibit the correct relative phase when driven from the common source.

**Procedure:**
1. Configure system to output CW at 10.050 GHz. Connect system RF source output (pre-phase-shifter) to each of the 16 TX elements in turn via a common feed.
2. For each element port, use VNA port 2 (reference: port 1 locked to the TX source) to measure S21 phase.
3. With all phase shifters set to 0x00 (minimum phase state), record S21 phase for each element.
4. Compute element-to-element phase variation (RMS deviation from mean).

**Pass Criteria:** Phase uniformity ≤±5° RMS across all 16 elements of each array (TX and RX) with phase shifters set to a common state. This verifies consistent feed network electrical length.

---

### PT-043 — Radiation Pattern Verification (Near-Field Scan)

**Objective:** Verify beam shape and steering capability using an improvised near-field measurement.

**Procedure:**
1. Mount the AERIS-10P antenna panel vertically at 1.5 m height on a non-metallic support.
2. Mount a calibrated reference antenna (standard gain horn, minimum 15 dBi at 10 GHz) on a camera tripod at distance R = 2 m from the aperture (near-field, adequate for pattern characterisation at this aperture size).
3. Connect reference horn to SA.
4. Apply CW from the AERIS TX chain at reduced power (−10 dBm at each element).
5. With all phase shifters at broadside setting (all 0x00), record received power as the reference horn is swept manually across ±60° in azimuth in 5° steps.
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

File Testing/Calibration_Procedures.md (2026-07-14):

# AERIS-10P Calibration Procedures
## Rev 1.0 — 2026-07-14

---

## Required Equipment

| Item | Specification | Purpose |
|---|---|---|
| Spectrum Analyzer | 0–20 GHz, resolution <1 kHz | Verify VCO frequency and PA output |
| Vector Network Analyzer (VNA) | 0–20 GHz (e.g., Keysight E5080B, R&S ZVA) | S11/S21 measurements, phase calibration |
| Power Meter | HP 437B + 8481A sensor or equivalent | TX power measurement |
| Frequency Counter | GPS-disciplined reference, 0.01 Hz resolution | OCXO calibration |
| Signal Generator | 10 GHz CW, ±1 dBm accuracy | Inject reference signal |
| Oscilloscope | ≥500 MHz, optional | FMCW chirp visualization |
| SMA attenuator | 20 dB, calibrated | Protect equipment from TX power |
| 50Ω terminator ×5 | SMA, 18 GHz | Terminate unused ports |

---

## 1. OCXO Frequency Calibration

**Objective:** Set OCXO to exactly 10.000000 MHz ±1 Hz

**Procedure:**
1. Connect OCXO output to frequency counter with GPS-disciplined reference
2. Allow 15 minutes warm-up time for OCXO temperature stabilization
3. Read displayed frequency. Target: 10.000000 MHz
4. If off by more than 1 Hz: adjust OCXO EFC (external frequency control) pin via firmware DAC
   - EFC voltage range: 0–5V (centered at 2.5V for nominal frequency)
   - Typical coefficient: ±0.5 ppm/V → ±5 Hz/V adjustment
5. Iterate until frequency counter shows 10.000000 ±0.001 MHz
6. Record OCXO serial number, calibration date, EFC voltage setting

**Acceptance:** Frequency within ±1 Hz of 10.000000 MHz

---

## 2. TX Power Calibration

**Objective:** Verify and document TX output power across chirp band

**Procedure:**
1. Connect 20 dB attenuator + power sensor to J_TX_RF SMA on main board
2. Send `CMD_SET_PA_ENABLE enable=1` via USB
3. Set chirp: 10.000–10.100 GHz, 1 ms sweep
4. Measure power at: 10.000, 10.025, 10.050, 10.075, 10.100 GHz (using SA in peak-hold mode)
5. Record all measured values in test data sheet
6. Compute flatness: max − min across band. Specification: ≤ 2 dB
7. Verify PA temperature: infrared thermometer on heatsink. Must be < 60°C after 5 min
8. If power is too high (> +30 dBm): reduce PA gate bias voltage via trimmer (R_VG on RF board)
9. If power is too low: check PA VDD supply voltage, verify SMA connections

**Acceptance:** Power at 10.05 GHz: +25 to +30 dBm. Flatness ≤ 2 dB across 100 MHz

---

## 3. Phase Shifter Calibration

**Objective:** Measure actual phase vs commanded code for all 32 phase shifters

**Setup:**
- VNA port 1 → HMC647A RF_IN (via SMA on antenna feed port, inject from divider side)
- VNA port 2 → HMC647A RF_OUT (antenna feed port for one element at a time)
- Measure S21 phase at 10.05 GHz

**Procedure (per element):**
1. Connect VNA to element under test (element 0 first)
2. Set all other elements to code=0 (isolation state)
3. For code = 0, 1, 2, ..., 63:
   a. Send SPI command via `aeris_control.py element_code --element N --code K`
   b. Wait 10 ms for VNA measurement
   c. Record VNA S21 phase reading
4. Compute phase error: error[k] = k × 5.625° − measured[k]
5. Store in calibration file: `calibration_tx_element_N.npy`
6. Repeat for all 16 TX elements, then all 16 RX elements

**Automation:**
```python
python Software/Signal_Processing/calibration.py --measure --element N --output cal_tx.npy
```
(Requires VNA Python interface — implement via pyvisa or similar)

**Acceptance:** RMS phase error per element ≤ 3° after calibration correction applied

---

## 4. RX Noise Figure Calibration

**Objective:** Measure RX chain noise figure using Y-factor method

**Setup:**
- Calibrated noise source (ENR known, e.g., Keysight 346B) → RX antenna input port
- IF output → spectrum analyzer

**Procedure:**
1. Record noise source ENR at 10.05 GHz (from calibration certificate)
2. With noise source OFF: measure output noise power N_cold on spectrum analyzer
3. With noise source ON: measure output noise power N_hot
4. Y-factor: Y = N_hot / N_cold (linear)
5. NF = ENR − 10·log10(Y − 1) (in dB, T_cold = 290 K assumed)
6. Expected result: ~2 dB (dominated by HMC1040 LNA NF = 1.5 dB)

**Acceptance:** System NF ≤ 3 dB

---

## 5. Range Calibration

**Objective:** Verify that detected range matches physical range to within ±1.5 m

**Setup:**
- Corner reflector at known distance (e.g., exactly 25.00 m in corridor or outdoor)
- Full radar system operating (PA enabled, calibration loaded)

**Procedure:**
1. Measure corner reflector distance precisely with tape measure (reference ±0.05 m)
2. Point radar antenna at corner reflector (broadside, 0° az, 0° el)
3. Capture 100 chirps and compute range profile
4. Identify range bin with peak amplitude
5. Compare detected range to physical distance
6. If offset: adjust software delay compensation in config.yaml → `range_offset_m`

**Acceptance:** Detected range within ±1.5 m (one range bin) of physical distance

---

## 6. Calibration Schedule

| Calibration | First Use | Periodic |
|---|---|---|
| OCXO frequency | ✓ | Every 100 operating hours |
| TX power | ✓ | Every 50 hours or after PA replacement |
| Phase shifter full | ✓ | Every 6 months |
| Phase shifter partial | — | After ±20°C temperature change |
| Noise figure | ✓ | Annually |
| Range calibration | ✓ | After software update |

---

## 7. Calibration Data Storage

All calibration files stored in `Software/Signal_Processing/` directory:
- `calibration_tx.npy` — TX array (16 × 64 float32 correction table)
- `calibration_rx.npy` — RX array (16 × 64 float32 correction table)
- `calibration_meta.yaml` — Date, temperature, operator, equipment used

Load calibration in control software:
```yaml
# In config.yaml:
array:
  calibration_file: calibration_tx.npy
```

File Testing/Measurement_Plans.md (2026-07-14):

# AERIS-10P Measurement Plans
## Rev 1.0 — 2026-07-14

---

## 1. Laboratory Measurement Plan

### Setup
```
Corner Reflector (0.3m edge)
         ↑
     (10–100m)
         ↑
  [AERIS-10P Radar]  ←→  [Laptop / Raspberry Pi 5]
         |                  (aeris_control.py + visualization.py)
    [24V supply]
```

### Test M-001: Short Range (10 m)
- **Objective:** Verify basic FMCW operation
- **Target:** 0.3m trihedral corner reflector (σ ≈ 133 m² = 21.2 dBsm)
- **Expected SNR:** ~60 dB (very high — will dominate the noise floor)
- **Expected range:** 10.0 m ± 1.5 m
- **Procedure:**
  1. Place corner reflector at 10.0 m in anechoic (or outdoor with no nearby reflectors)
  2. Enable TX, collect 100 chirps
  3. Compute range profile, identify peak
  4. Record: measured range, peak amplitude, SNR, noise floor
  5. Verify: peak at correct range bin (bin #6 for 10 m with 1.5 m resolution)

### Test M-002: Medium Range (50 m, 100 m)
- Repeat M-001 at 50 m and 100 m
- Expected SNR reduction: ~40·log10(10/50) = -28 dB at 50m, -40 dB at 100m from M-001
- Minimum detectable range at 100 m: still >15 dB SNR expected

### Test M-003: Car Target (100 m)
- Target: parked car (σ ≈ 10 m² = 10 dBsm)
- Measure SNR, compare to link budget prediction at 100 m
- Expected: ~40 dB SNR at 100 m for car target (well above 15 dB threshold)

---

## 2. Medium-Range Field Test Plan (500 m – 1 km)

### Location Requirements
- Open field, no obstacles in main beam direction
- Clear line of sight to target at all planned ranges
- Ground slope < 5° (to avoid multipath from ground)
- Minimum open area: 1 km × 0.1 km

### Test M-010: Car at 500 m
- Target: car driving at 30 km/h (8.3 m/s) in cross-path geometry
- Expected beat frequency at 500 m: f_beat = 2×500×100e6/(3e8×1e-3) = 333 Hz
- Expected Doppler: f_dop = 2×8.3/0.02985 = 556 Hz
- Capture 100-chirp CPI, compute range-Doppler map
- Identify car peak in RDM, record range, velocity, SNR

### Test M-011: Beam Steering Verification
- Place two corner reflectors at 0° and +30° azimuth (100 m range)
- Steer beam to 0°: verify reflector 1 peak > reflector 2 peak by >10 dB
- Steer beam to 30°: verify reflector 2 peak > reflector 1 peak by >10 dB
- Record beam pattern main lobe width

---

## 3. Maximum Range Test Plan (2 – 3 km)

### ⚠️ Regulatory Requirement
**Must receive BNetzA confirmation before this test.**
Operate under Klasse A amateur radio license, identify station every 10 min.

### Location Requirements
- Elevated position with >3 km clear line of sight
- No interference to/from primary users (satellite uplinks, etc.)
- Permission from landowner for field access
- Weather: no rain (adds attenuation), no lightning

### Test M-020: Vehicle Detection at 2 km
- Target: car at known distance (measure with GPS or rangefinder)
- Predicted SNR at 2 km: ~30 dB (car target, from link budget)
- Acceptance: detect car at 2 km with SNR > 15 dB in >80% of CPIs

### Test M-021: Maximum Range Determination
- Move car from 1 km to 5 km in 0.5 km steps
- At each range: capture 20 CPIs, record mean SNR and detection rate
- Plot SNR vs range, compare to link budget prediction
- Find R_max (range where SNR drops below 15 dB) — expected 3–5 km

---

## 4. Data Collection Workflow

```
1. aeris_control.py connect --port /dev/ttyACM0
2. aeris_control.py beam --az 0 --el 0
3. aeris_control.py chirp --start 10e9 --stop 10.1e9 --time-us 1000
4. aeris_control.py pa-enable 1
5. aeris_control.py capture --n-chirps 100 --save session_001
6. (repeat steps 2-5 for each steering angle)
7. aeris_control.py pa-enable 0
8. python fmcw_processing.py --session session_001 --plot
```

---

## 5. Expected Performance Table

| Range (km) | Target | σ (dBsm) | Predicted SNR (dB) | Detect? |
|---|---|---|---|---|
| 0.010 | Corner reflector | 21 | >60 | Yes |
| 0.100 | Car | 10 | ~45 | Yes |
| 0.500 | Car | 10 | ~33 | Yes |
| 1.000 | Car | 10 | ~27 | Yes |
| 2.000 | Car | 10 | ~21 | Yes |
| 3.000 | Car | 10 | ~17 | Yes (marginal) |
| 4.000 | Car | 10 | ~15 | Threshold |
| 5.000 | Car | 10 | ~12 | Borderline |
| 5.000 | Truck (σ=100m²) | 20 | ~22 | Yes |

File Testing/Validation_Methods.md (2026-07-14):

# AERIS-10P Validation Methods
## Rev 1.0 — 2026-07-14

---

## 1. Validation Philosophy

Each subsystem is validated independently before integration. Simulation predictions are compared against measurements. Pass/fail criteria are defined for each requirement.

**Validation levels:**
1. **L1 — Analysis:** verified by calculation (design-time, no hardware)
2. **L2 — Simulation:** verified by software simulation (demo_no_hardware.py, OpenEMS)
3. **L3 — Bench test:** verified by bench measurement (single board, lab instruments)
4. **L4 — Integration test:** verified in complete integrated system
5. **L5 — Field test:** verified in operational field conditions

---

## 2. Requirements Validation Matrix

| Req ID | Description | Target | Method | Level | Status |
|---|---|---|---|---|---|
| REQ-RF-001 | Chirp start frequency | 10.000 ±1 MHz | Spectrum analyzer | L3 | Pending |
| REQ-RF-002 | Chirp stop frequency | 10.100 ±1 MHz | Spectrum analyzer | L3 | Pending |
| REQ-RF-003 | Chirp bandwidth | 100 ±2 MHz | Spectrum analyzer | L3 | Pending |
| REQ-RF-004 | Chirp linearity | ≤1% deviation | Oscilloscope + FFT | L3 | Pending |
| REQ-RF-005 | TX output power | +25 to +30 dBm | Power meter | L3 | Pending |
| REQ-RF-006 | Phase shifter range | 0–354° all elements | VNA S21 phase | L3 | Pending |
| REQ-RF-007 | Phase shifter error | ≤3° RMS | VNA measurement | L3 | Pending |
| REQ-RF-008 | System noise figure | ≤3 dB | Y-factor | L3 | Pending |
| REQ-SYS-001 | Range resolution | ≤2 m | Corner reflector | L4 | Pending |
| REQ-SYS-002 | Max detection range (car) | ≥2 km | Field test | L5 | Pending |
| REQ-SYS-003 | Beam steering range | ±45° | Calibration antenna | L4 | Pending |
| REQ-SYS-004 | Beam width | ≤25° | Array pattern meas. | L4 | Pending |
| REQ-REG-001 | TX frequency in band | 10.000–10.500 GHz | Spectrum analyzer | L3 | Analysis done |
| REQ-REG-002 | TX power ≤75 W PEP | ≤75 W | Power meter | L3 | Pending |
| REQ-REG-003 | Station identification | Every 10 min | Software review | L2 | Analysis done |

---

## 3. Simulation-Hardware Correlation

For each test:
1. Run `demo_no_hardware.py` with same parameters (range, RCS, SNR)
2. Simulate and record: detected range, SNR, false alarm rate
3. Compare to hardware measurement result
4. Acceptance: within ±3 dB SNR, ±1 range bin

```python
# Run simulation for comparison:
python Software/Signal_Processing/demo_no_hardware.py \
  --scenario single \
  --no-display \
  --print-link-budget
```

---

## 4. Software Validation (Unit Tests)

```python
# Test signal processing pipeline:
python Software/Signal_Processing/fmcw_processing.py  # runs demo()

# Test link budget calculator:
python RF_System/link_budget_calculator.py --print-link-budget

# Test antenna simulation:
python RF_System/openems_antenna_simulation.py --mode analytical
```

**Test cases for fmcw_processing.py:**
- Single target at 500 m: verify detected range = 500 ±1.5 m
- Two targets at 500 m, 1200 m: verify both detected, resolved
- CFAR false alarm rate: 1000 noise-only trials, verify <1% false detections
- Phase monopulse: inject 30° angle, verify estimate within ±3°

---

## 5. Validation Report Template

After each test phase, complete this template:

```
AERIS-10P Validation Report
Test phase: [Phase name]
Date: [YYYY-MM-DD]
Operator: [Name + callsign]
Location: [Lab / field location]
Weather: [Temperature, humidity, conditions]

Equipment:
  VNA: [Model, serial, cal date]
  SA:  [Model, serial, cal date]
  Power meter: [Model, sensor, cal date]

Results:
  [Req ID]: Measured=[value], Spec=[value], PASS/FAIL

Issues:
  [Issue description, workaround applied]

Signature: _____________ Date: _________
```

---

## 6. Error Budget

| Error source | Magnitude | Impact |
|---|---|---|
| Phase shifter LSB (5.625°) | ±2.8° per element | ±1.4° beam pointing |
| Phase calibration residual | ±3° RMS | ~0.1 dB gain loss |
| Cable phase mismatch | ±3° | Same as calibration |
| Thermal drift (per 10°C) | ~0.5°/shifter | Correct with periodic recal |
| Total combined | ~±5° system | ~0.5 dB gain degradation |

**Conclusion:** Combined errors result in <0.5 dB gain loss and <2° beam pointing error. Acceptable for research-grade system.

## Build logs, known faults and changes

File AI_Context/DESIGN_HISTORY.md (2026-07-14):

# AERIS-10P Design History and Decision Log
**Format:** [Date] [Phase] [Decision]: Rationale. Alternatives considered.

---

## 2026-07-14 — Initial Design Session

**[2026-07-14] [Concept] [Project Name]:** Named AERIS-10P (Affordable Experimental Radar Intelligence System, 10 GHz Phased Array). Name chosen to reflect: experimental nature (important for regulatory context), budget constraint (affordable), and technical spec (10 GHz phased array). The "10P" distinguishes it from hypothetical future variants at other frequencies.

**[2026-07-14] [Concept] [Inspired by AERIS-10 N]:** Design inspired by the open-source AERIS-10 N radar project. Key differences: this design targets German amateur radio operation (different regulatory framework than US-based AERIS-10 N), adds phased-array capability, and targets 2-3 km range vs shorter-range demonstrations.

**[2026-07-14] [Regulatory] [German Band Selection]:** Selected 10.000–10.100 GHz after researching German amateur radio band plan (DARC). Key finding: 10.000–10.500 GHz (3 cm band) has full amateur secondary allocation in Germany. Klasse A license permits up to 75 W PEP. Our 1 W design has 18.75 dB margin. Alternative bands rejected: 5.8 GHz (no German amateur allocation outside ISM), 24 GHz (limited allocation, expensive components), 2.4 GHz (overcrowded, no good radar components).

**[2026-07-14] [Waveform] [FMCW Selected Over Pulse]:** FMCW chosen because: (1) low peak power — amateur license is power-limited, FMCW averages power over chirp time; (2) no range blind zone; (3) simpler receiver (low-rate ADC vs GHz-rate for pulse); (4) better spectral compatibility with amateur operations. Pulsed radar would need much higher peak power for same range, potentially requiring special permits.

**[2026-07-14] [RF] [10.0-10.1 GHz Chirp Band]:** 100 MHz bandwidth gives 1.5m range resolution (c/2B = 3e8/(2×100e6)). Wider bandwidth would give better resolution but would require more PCB layout care and possibly exceed amateur band allocation. 100 MHz was determined to be a good trade-off: achievable with ADF4159 + HMC733, stays within amateur band, gives useful resolution.

**[2026-07-14] [Architecture] [4×4 Array Size]:** 16 elements chosen after budget analysis. 8×8 would give better performance (11° beam width vs 22°, +6 dB gain) but costs nearly 4× more in phase shifters alone (64 × $35 = $2,240 vs 32 × $35 = $1,120). Budget constraint ($8,000 total) made 4×4 the practical choice. Future upgrade path: 4×4 + MIMO processing gives virtual 8×8.

**[2026-07-14] [Architecture] [Analog Beamforming]:** Analog phase shifters chosen over digital beamforming (per-element ADC) for cost. Digital beamforming with 32 elements would need 32 ADCs + FPGA → estimated cost $15,000+. Analog beamforming with HMC647A costs ~$1,120 for all 32 shifters. Trade-off: analog is less flexible (can only form one beam at a time, no post-processing beam agility) but sufficient for research purposes.

**[2026-07-14] [Components] [HMC647ALP5E Phase Shifter]:** Only 6-bit X-band MMIC phase shifter in stock at distributors in 2026. Alternatives reviewed: MAPS-010144 (5-bit, less resolution), UMS CHU2140 (obsolete/hard to source), custom GaAs (impractical for small quantity). HMC647A is the best available choice. 6-bit = 5.625° LSB → adequate for 4-element array where beam width is 22° (LSB = 22°/4 ≈ 5.5°, well matched).

**[2026-07-14] [Components] [ADF4159 FMCW PLL]:** Selected for built-in sawtooth ramp generator — eliminates need for real-time CPU-generated chirp (which would require DDS or DAC at high speed). ADF4159 generates the FMCW chirp autonomously in hardware once programmed. Alternative: ADF4355 (integrated PLL+VCO but worse phase noise at 10 GHz), ADF5355 (similar). ADF4159 + external HMC733 VCO gives better phase noise than integrated solutions.

**[2026-07-14] [Components] [HMC733 VCO]:** Selected for best in-class phase noise (-120 dBc/Hz @ 100 kHz offset) at 10 GHz in small quantity. This is critical for FMCW radar: VCO phase noise becomes range-dependent clutter floor. Alternative: HMC-SXX112 (integrated PLL+VCO, lower phase noise control, not as good for FMCW), custom DRO (better phase noise but impractical to source).

**[2026-07-14] [Components] [HMC451LS6GE PA]:** +29 dBm P1dB at X-band, 28 dB gain, in distributors. Operated at +27 dBm (back off 2 dB from P1dB for linearity). Alternatives: HMC943 (+33 dBm but $150+), CGY2122UH (cheaper but lower output). Decision: HMC451 gives 1W at antenna with good efficiency, within budget.

**[2026-07-14] [Components] [HMC1040LP4E LNA]:** Best noise figure (1.5 dB) at 10 GHz available from distributors in 2026. NF dominates system noise figure since it's first in the chain. Each 0.1 dB NF improvement adds ~0.4 km to max range. Alternative: TQL9092 (NF 1.7 dB, cheaper) would reduce range by ~10%.

**[2026-07-14] [Components] [STM32H743ZIT6 MCU]:** Selected because: (1) 6 SPI buses needed simultaneously (SPI1: TX PS, SPI2: RX PS, SPI3: ADF4159, SPI4: ADS8661, SPI5: spare, SPI6: spare); (2) USB FS built-in for PC communication; (3) 480 MHz for real-time control; (4) abundant GPIO (144-pin LQFP); (5) STM32Cube ecosystem. Alternatives: STM32F767 (slower), RP2040 (fast PIO but only 2 SPI buses), ESP32 (WiFi but limited SPI count).

**[2026-07-14] [Components] [Raspberry Pi 5 8GB]:** Best performance/cost for Python FMCW DSP. 2.4 GHz quad-core A76 can run 100k-point FFT at >10 Hz update rate. USB3 for ADC data streaming. Alternative: NVIDIA Jetson Nano ($149, CUDA for parallel FFT), Intel NUC ($400, overkill). Upgrade path documented in TODO.md.

**[2026-07-14] [Components] [Rogers RO4003C Substrate]:** Industry standard for X-band PCBs. εr=3.55, tan δ=0.0027, available from PCBWay and Advanced Circuits. Alternative: Rogers RO4350B (similar performance, slightly different εr), Rogers RT/duroid 5880 (lower loss but more expensive), standard FR4 (too lossy at 10 GHz — loss tangent 10× higher). RO4003C is the practical choice for a research project.

**[2026-07-14] [Mechanical] [3D-Printed Prototype]:** PETG chosen for prototype enclosure (vs machined aluminium) because: faster iteration (hours vs weeks), much cheaper ($5 vs $150+), sufficient for initial testing. Machined aluminium planned for field-use version (better RF shielding, durability, IP protection). STL files created for both prototype and final designs.

**[2026-07-14] [Software] [Python for Signal Processing]:** Python chosen for DSP because: numpy/scipy/matplotlib ecosystem; abundant radar signal processing libraries; easier development than C/MATLAB; runs on RPi5. NumPy FFT is fast enough for our update rate (<10 Hz). Alternative: MATLAB (expensive, requires license), GNU Radio (complex for custom FMCW), C++ (faster but more development time). Numba JIT compilation available for bottlenecks.

**[2026-07-14] [Software] [USB CDC-ACM Protocol]:** Custom binary packet protocol chosen over: JSON (too verbose for ADC streaming), UART (slower), SPI/I2C (requires additional hardware), Ethernet (RPi5 has it but adds complexity). Binary packet format is compact and fast. 16-bit ADC at 8 kSPS = 128 kbps → well within USB FS 12 Mbps.

**[2026-07-14] [Budget] [Total $4,451]:** Well under $8,000 target. Breakdown: RF ICs $2,292 (51%), PCBs $626 (14%), cables $512 (11%), mechanical $109 (2%), test equipment $140 (3%), consumables $75 (2%). Largest cost driver: 2.92mm SMA connectors ($358 for 40 units). Possible reduction: use cheaper SMA-type connectors for prototype, reserve 2.92mm for final version.

---

## Future Entries (Template)

When adding new entries, use this format:

**[YYYY-MM-DD] [Phase] [Decision Topic]:** What was decided. Why. What alternatives were considered and rejected. Who made the decision.

Phases: Concept, Research, Regulatory, RF, Architecture, Components, PCB, Mechanical, Software, Testing, Budget, Procurement, Assembly, Integration

---
*This log should be updated whenever a significant design decision is made or revised.*

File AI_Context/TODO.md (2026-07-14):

# AERIS-10P Project TODO
**Last updated:** 2026-07-14 | **Status:** Design complete, hardware phase starting

---

## CRITICAL (Do First)

- [ ] **Check HMC647ALP5E stock on Mouser** — 32 units needed. If stock < 50, order immediately. Long lead time (8-16 weeks) possible. Run `link_budget_calculator.py` first to confirm no design changes needed before ordering.
- [ ] **Import EasyEDA JSON files** — Open easyeda.com, File > Import > EasyEDA JSON, import all 4 files from PCB/EasyEDA_Projects/. Verify components appear correctly. Fix any format issues.
- [ ] **Contact BNetzA before field operation** — Email poststelle@bnetza.de. Subject: "Anfrage: FMCW-Radar unter Amateurfunklizenz Klasse A bei 10 GHz". Reference §67 TKG.

---

## HIGH PRIORITY

- [ ] **Generate STM32CubeMX project** — Open STM32CubeMX, select STM32H743ZIT6, configure: HSE 25 MHz crystal, PLL → 480 MHz HCLK, SPI1 (10 MHz AF5), SPI2 (10 MHz AF5), SPI3 (1 MHz AF6), SPI4 (1 MHz AF5), USB_FS (PA11/PA12), USART1 (PA9/PA10 115200 baud), ADC1 (for NTC). Generate HAL project, then merge with existing firmware files.

- [ ] **Run antenna EM simulation** — Install OpenEMS (conda install -c conda-forge openems). Run: `python RF_System/openems_antenna_simulation.py --mode analytical` (no hardware needed). Then `--mode setup` for full EM sim. Verify S11 < -15 dB at 10.05 GHz. If resonance is off, adjust L_patch by ±0.5 mm.

- [ ] **PCB layout — Power Board** (START HERE — simplest board)
  - Board: 100×80 mm, 2-layer FR4
  - Place LT8612 with L1, C3-C6 first
  - Place LT8607 with L2, C8-C9
  - Place TPS65133 with L3-L4
  - Place XT60 connector, fuse, reverse polarity MOSFET
  - Route 2mm power traces for 5A paths
  - Star ground at input capacitor
  - Export Gerbers and order from JLCPCB

- [ ] **PCB layout — Main Control Board**
  - Board: 160×100 mm, 4-layer FR4
  - Place STM32H743 centrally (144-pin)
  - Place ADF4159 near SPI3 pins
  - Place HMC733 VCO at corner with RF clearance
  - Place ADS8661 near SPI4 pins
  - Place OCXO module at corner
  - USB connector on board edge
  - Decouple all supply pins with 100nF 0402
  - Export Gerbers

- [ ] **Order RF components from Mouser** — Prioritize:
  1. HMC647ALP5E ×32+ (Mouser 597-HMC647ALP5E)
  2. HMC1040LP4E ×18 (Mouser 597-HMC1040LP4E)
  3. HMC213B ×2 (Mouser 597-HMC213B)
  4. HMC451LS6GE ×2 (Mouser 597-HMC451LS6GE)
  5. HMC733LP6CE ×2 (Mouser 597-HMC733LP6CE)
  6. ADF4159CCPZ ×2 (Mouser 584-ADF4159CCPZ)

- [ ] **Verify ADF4159 register values** — Use ADIsimPLL (free from Analog Devices website) to verify chirp register calculation in adf4159.c. Input: f_ref=10MHz, f_start=10.000GHz, f_stop=10.100GHz, sweep_time=1ms. Compare DEV_WORD and CLK_DIV with software output.

---

## MEDIUM PRIORITY

- [ ] **PCB layout — RF Frontend** (Most complex, save for last)
  - Board: 100×60 mm, 4-layer Rogers RO4003C
  - Impedance-controlled: 50Ω microstrip = 1.08 mm trace width
  - Place HMC451 PA at RF input with heatsink slug area
  - Place Wilkinson divider tree (PCB trace based)
  - Place 16× HMC647A in 4×4 grid pattern
  - Place 16× HMC1040 LNA in 4×4 pattern
  - Place HMC213B mixer
  - RF via fence along all RF traces
  - Add ground plane stitching vias every 5 mm
  - Order from PCBWay (specify RO4003C, controlled impedance)

- [ ] **PCB layout — Phase Shifter Boards** (2 identical boards: TX and RX)
  - Board: 120×80 mm, 4-layer hybrid Rogers/FR4
  - 16× HMC647A in 4×4 layout matching antenna element positions
  - SPI daisy-chain routing (U16→U15→...→U1)
  - RF distribution network (Wilkinson 1:4 + 4× 1:4)
  - 16× 2.92mm SMA edge-launch on board edge

- [ ] **Test firmware on Nucleo-H743ZI eval board** — Cheaper than custom PCB for firmware validation. Adapt GPIOs to Nucleo pinout. Test: USB CDC enumeration, SPI communication (use logic analyzer), ADF4159 lock detect.

- [ ] **Run `demo_no_hardware.py` tests** — `python Software/Signal_Processing/demo_no_hardware.py --scenario highway`. Verify processing pipeline, CFAR detection, visualization. Test with `--no-display --frames 50` for headless/CI testing.

- [ ] **Design PA heatsink** — HMC451LS6GE dissipates ~5W. Need heatsink with Rth < 6°C/W. Options: (a) Copper slug under PCB in Rogers board, (b) External TO-3 heatsink bonded with thermal paste, (c) Forced air from 80mm fan. Finalize design before PCB layout.

- [ ] **Install required software tools**:
  - STM32CubeIDE: st.com/stm32cubeide
  - OpenEMS: conda install -c conda-forge openems
  - Python deps: pip install -r Software/Control/requirements.txt
  - EasyEDA: easyeda.com (browser-based)
  - STM32CubeMX: st.com/stm32cubemx

---

## LOW PRIORITY

- [ ] **Refine STL models** — Current STL files are simple solid boxes. For production: (a) Add ventilation slots to enclosure, (b) Add connector cutouts to front panel, (c) Add PCB mounting bosses to electronics tray, (d) Use FreeCAD for parametric design.

- [ ] **Calibration software test** — Run `python Software/Signal_Processing/calibration.py` with test data. Verify calibration table generation and file format (.npy).

- [ ] **Excel spreadsheet generation** — Install openpyxl: `pip install openpyxl`. Run `python Spreadsheets/generate_spreadsheets.py` to generate formatted .xlsx files. Open in Excel and verify.

- [ ] **GitHub repository setup** — Create public repo at github.com. Include: all source files, README.md, LICENSE (CC BY-SA 4.0), .gitignore (exclude build artifacts), releases (firmware .bin files).

- [ ] **Write DARC community article** — Document the project for the DARC journal (Funkamateur or CQ DL). Share design files with amateur radio community. Contact DARC OV for possible club project support.

- [ ] **Amateur radio station identification** — Implement callsign beacon in firmware: every 600s, transmit CW callsign (Morsetext) as brief interrupt to normal FMCW operation. Command: CMD_SEND_ID in main.c.

- [ ] **Corner reflector fabrication** — Build trihedral corner reflector from 0.3m aluminum sheet (σ = ~133 m² = 21 dBsm). Use for range calibration test at 25 m. Dimensions: 3 equilateral triangles, 30cm edge.

- [ ] **Update PROJECT_MEMORY.md** after each major milestone (hardware assembly, first power-on, first detection).

---

## QUICK COMMANDS

```bash
# Test signal processing (no hardware needed):
python Software/Signal_Processing/demo_no_hardware.py --scenario highway

# Compute link budget:
python RF_System/link_budget_calculator.py --range-km 3 --rcs 10 --sweep

# Run antenna design calculations:
python RF_System/openems_antenna_simulation.py --mode analytical

# Generate Excel spreadsheets:
pip install openpyxl
python Spreadsheets/generate_spreadsheets.py

# Build STM32 firmware (requires arm-none-eabi-gcc):
cd Software/Embedded/firmware
make all

# Flash firmware (requires ST-Link):
make flash
```

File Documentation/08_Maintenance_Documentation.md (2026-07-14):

# AERIS-10P Maintenance Documentation
## Rev 1.0 — AERIS-10P Affordable Experimental Radar Intelligence System, 10 GHz Phased Array

**Document Number:** AERIS-MNT-001  
**Revision:** 1.0  
**Date:** 2026-07-14  
**Author:** RF Systems Engineering  
**Status:** Released  

---

## 1. Scope

This document defines all maintenance requirements for the AERIS-10P phased-array FMCW radar system, including scheduled preventive maintenance, calibration procedures, fault diagnosis, component replacement, storage, and disposal. Maintenance must be performed only by technicians familiar with RF systems and ESD-safe handling. Any radiated testing during maintenance activities requires a valid amateur radio licence (Klasse A) in accordance with AFuG 2017 and AFuV 2017.

---

## 2. Maintenance Schedule

### 2.1 Maintenance Interval Summary

| Interval | Activity | Reference |
|---|---|---|
| Pre-operation (every use) | Pre-operation checklist | Section 3 |
| Monthly | RF connector inspection, software version check, TX power verification, fan inspection | Sections 4.1, 4.2, 5.3 |
| Quarterly | OCXO frequency calibration against GPS reference, phase noise spot check, PCB visual inspection | Section 5.1 |
| Annually | Full calibration verification (all PT-0xx), phase shifter recalibration, thermal paste replacement, fan replacement (if required), deep PCB inspection for corrosion, spare parts inventory review | Sections 5.2, 6.1, 4.3 |
| After any hard impact or weather exposure | Mechanical inspection, connector integrity check, antenna panel inspection | Sections 4.1, 4.4 |

### 2.2 Maintenance Log

A maintenance log must be kept for the AERIS-10P system. Each entry must include:
- Date and time
- Operator (callsign and name)
- Activity performed
- Results / observations
- Corrective actions taken (if any)
- Signature

The maintenance log is stored with the system documentation in `/Documentation/Maintenance_Log/`. A paper copy may be kept in the system case for field use.

---

## 3. Pre-Operation Checklist

Perform this checklist before every operational use of the AERIS-10P system. The checklist takes approximately 5–10 minutes. Do not operate the system if any item fails.

| Item | Check | Action if Failed |
|---|---|---|
| 3.1 | RF connectors: visually inspect all SMA connectors for obvious damage, bent centre pins, cracked bodies | Do not operate; see Section 6.2 |
| 3.2 | RF connectors: verify all SMA connectors are finger-tight, then tightened to 0.9 Nm with torque wrench | Tighten; re-inspect |
| 3.3 | Antenna panel: no physical damage, no contamination on patch elements | Clean with dry lint-free cloth; do not use IPA on Rogers surface without a separate cleaning verification |
| 3.4 | 24 V power cable: inspect for damage, check fuse continuity | Replace fuse or cable |
| 3.5 | Cooling fan: power on system, verify fan spins within 5 s; hold hand near exhaust — airflow felt | See fault diagnosis; do not operate without working fan if ambient >20°C |
| 3.6 | Software version: boot system, check AERIS software version in startup screen or `aeris-status --version` | Update if behind current release |
| 3.7 | Calibration date: check last calibration date in maintenance log | Schedule calibration if overdue |
| 3.8 | PLL lock: verify PLL_LOCK indicator is GREEN in the software status panel within 10 s of startup | See fault diagnosis PT-010 fault tree |
| 3.9 | TX power indicator: verify software shows TX power within ±2 dB of nominal | See fault diagnosis |
| 3.10 | Station identification: confirm callsign is entered correctly in system settings; verify auto-ID timer is active (10-minute interval) | Enter callsign per AFuV 2017 requirements before any radiated operation |
| 3.11 | Tripod mounting: verify 3/8-16 UNC thread engagement is ≥6 turns; verify the system is level | Re-mount; do not operate if mount is insecure |

---

## 4. Routine Maintenance Tasks

### 4.1 RF Connector Inspection and Cleaning

RF connector integrity is the single most common source of performance degradation in field-operated RF systems. Clean connectors at every monthly maintenance and whenever the system has been operated in dusty or humid conditions.

**Procedure:**
1. Disconnect all SMA connectors from mating parts.
2. Inspect the centre pin of each SMA male connector: it must be straight, undamaged, and protrude the correct distance (SMA male pin protrusion: 3.02 mm ±0.05 mm from the reference plane). A bent or retracted pin must be replaced (see Section 6.2).
3. Inspect the SMA female socket: threads must be clean and sharp; the dielectric must be white/beige PTFE with no cracks.
4. Apply a few drops of 99.9% IPA to a lint-free swab. Insert the swab into the female SMA socket and rotate to clean the inner conductor and socket. Do not apply IPA to the Rogers RO4003C patch surfaces directly — apply to a lint-free cloth and gently wipe if cleaning is required.
5. Allow 2–3 minutes for IPA to evaporate before reconnecting.
6. Inspect the mating surfaces under 5× magnification if available. Any pitting, arcing damage, or contamination that persists after cleaning warrants connector replacement.

**Torque on reassembly:** 0.9 Nm (8 in-lb) using the calibrated SMA torque wrench. Do not over-torque — SMA connectors on Rogers PCBs can crack the PCB copper around the connector tabs if over-torqued.

### 4.2 Software Version Verification

1. SSH into the Raspberry Pi 5: `ssh pi@aeris-radar.local`
2. Check current version: `aeris-status --version`
3. Check for updates: `cd /home/pi/aeris-software && git fetch origin && git status`
4. If behind, update: `git pull origin main && pip3 install -r requirements.txt && sudo systemctl restart aeris-radar`
5. After update, run the self-test: `aeris-selftest --basic`
6. STM32 firmware version: visible in the serial console boot banner, or query via `aeris-status --fw-version`. Update STM32 firmware via ST-LINK per the assembly documentation (Section 9.1) if a new release is available.

### 4.3 Thermal Paste Refresh (Annual)

The HMC451LS6GE PA and the LT8612/LT8607 DC-DC converters use thermal interface material to the chassis. Thermal paste dries and cracks over 12–18 months, increasing junction temperatures.

**Procedure:**
1. Power off the system and disconnect 24 V.
2. Remove the electronics tray from the chassis (4× M3 screws).
3. Use a plastic spudger to separate the PA and DC-DC ICs from the thermal pad or paste contact with the tray.
4. Remove old thermal paste with IPA on a lint-free cloth. Remove thoroughly — do not leave residue.
5. Apply a fresh, thin bead (approximately 0.1 mm thickness, rice-grain amount for QFN packages) of Shin-Etsu X-23-7921-5 or equivalent ≥6 W/m·K paste to the IC thermal pad.
6. Replace the electronics tray. Torque screws to 0.35 Nm.
7. Run the system for 30 minutes and measure IC temperatures as per PT-005. Compare to baseline.

### 4.4 Fan and Filter Cleaning

The 80 mm fan draws air through the chassis. Dust accumulation on the fan blades and any inlet mesh increases thermal resistance and reduces fan life.

**Procedure (Monthly):**
1. Power off the system.
2. Open the chassis or access the fan from the rear panel.
3. Use a dry compressed air blast (ESD-safe can duster) to clear dust from the fan blades and any inlet grille. Direct the airflow backwards through the grille to push dust out.
4. Do not use water or IPA on the fan motor.
5. Check that the fan rotates freely by hand. Any bearing roughness or wobble indicates the fan should be replaced (annual or on condition).

**Fan Replacement:**
If the fan tachometer reading falls below 80% of rated speed (typically 1800–2400 RPM for a 5 V 80 mm ball-bearing fan) or exhibits audible bearing noise, replace the fan. Use a ball-bearing type only (not sleeve bearing) for reliability in tilted or inverted orientations on the tripod. Replace with: Noctua NF-A8 (5 V fan with JST adaptor) or Delta FFB0812EHE (12 V, with voltage converter if needed).

### 4.5 PCB Inspection for Corrosion

Annually or after any moisture exposure, inspect all PCBs for corrosion signs:

1. Remove all PCBs from the chassis.
2. Inspect under 10× magnification:
   - Green or white powdery deposits indicate flux residue contamination (not corrosion) — clean with IPA.
   - Blue/green staining on copper pads indicates copper oxide corrosion from moisture ingress.
   - Brown/black staining on SMA connector threads indicates oxidation — clean and assess structural integrity.
3. Apply a thin coat of Humiseal 1B31 conformal coating to non-RF areas (power board, digital sections of MainBoard) if regular humidity exposure is expected. Do not apply conformal coating to the RF Frontend board or antenna panel.

---

## 5. Calibration Procedures

### 5.1 Frequency Reference Calibration (Quarterly)

The AERIS-10P uses an ABRACON AOCJY-10 OCXO as the 10 MHz master reference. While this oscillator is specified at ±0.01 ppm stability, it can drift at the extremes of its temperature range. Calibration verifies that the frequency reference is within specification.

**Equipment required:** GPS-disciplined OCXO (e.g., Jackson Labs CSAC, Z3805A, or a GPS reference receiver with 10 MHz output such as a u-blox LEA-M8F development board), frequency counter (Keysight 53230A or HP 53131A, 10-digit, 10 MHz or higher timebase).

**Procedure:**
1. Allow the AERIS-10P OCXO to warm up for 15 minutes in a stable-temperature environment.
2. Connect the GPS-disciplined reference to the frequency counter's reference input.
3. Connect the AERIS OCXO output (10 MHz) to the frequency counter's measurement input.
4. Gate time: 10 seconds. Record 10 consecutive 10-second frequency measurements.
5. Compute mean frequency: f_mean. Compute offset from 10 MHz: Δf = f_mean − 10,000,000 Hz.
6. Frequency accuracy in ppm: accuracy = Δf / 10 × 10⁻⁶ ppm.

**Pass Criterion:** |accuracy| ≤ 0.01 ppm (|Δf| ≤ 0.1 Hz). If outside this range, the OCXO calibration trimmer (if available) may be adjusted. Otherwise, the OCXO must be replaced.

**Logging:** Record mean frequency and offset in the maintenance log.

### 5.2 Phase Shifter Recalibration (Annual)

The HMC647ALP5E phase shifters are factory-calibrated at manufacture, but the phase vs. code relationship can shift with temperature cycling and component ageing. Annual recalibration updates the phase correction table stored in the STM32 firmware.

**Equipment required:** Vector Network Analyzer with 2-port calibration, calibrated cables.

**Procedure:**
1. Execute the recalibration command from the AERIS software: `aeris-cal --phase-shifters`
2. The system automatically:
   a. Steps each of the 16 TX and 16 RX phase shifters through all 64 phase codes.
   b. Measures the S21 phase at each code using the system's internal feedback path (or an external VNA port if connected in calibration mode).
   c. Stores the measured phase-vs-code table in the STM32 non-volatile flash.
3. After calibration, verify beam steering performance (abbreviated version of PT-043): steer to 0°, ±15°, ±30°. Confirm peaks within ±3°.

**Alternative (VNA-based, more accurate):**
1. Connect VNA port 1 to the common TX feed. Connect VNA port 2 to the output of each phase shifter in turn.
2. Step through all 64 codes for each phase shifter and record measured phase at 10.050 GHz.
3. Upload the measured calibration table to the STM32 via USB serial command.

### 5.3 TX Power Verification (Monthly)

**Equipment required:** Power meter (HP 437B + 8485A sensor), 30 dB, 5 W in-line SMA attenuator, calibrated cable.

**Procedure:**
1. Connect 30 dB attenuator and calibrated cable to the TX output SMA port.
2. Connect power meter sensor to the cable output.
3. Zero the power meter with RF off.
4. Enable CW at 10.050 GHz via the AERIS software maintenance menu (`aeris-maint --cw-mode 10050`).
5. Record power meter reading. Correct for attenuator loss and cable loss (from the cable loss log).
6. Compare to nominal value (+30 dBm ±1 dB at the TX SMA port).

**Pass Criterion:** Corrected TX output power: +29 to +31 dBm. If outside this range, proceed to the PA fault diagnosis (Section 6.3).

---

## 6. Common Fault Diagnosis

### 6.1 No PLL Lock

**Symptom:** PLL_LOCK indicator is red or absent in the AERIS software status panel. The ADF4159 lock detect (MUXOUT) GPIO reads LOW on the STM32.

**Fault tree:**

1. **Check OCXO power and output.** Measure the OCXO supply voltage (should be +5 V ±0.1 V). Measure OCXO output level at the ADF4159 REF_IN pin with an oscilloscope: expect a 10 MHz sine wave, 0.5–1 V peak, or a clipped near-square wave. If no signal: OCXO may have failed; replace the ABRACON AOCJY-10.

2. **Check SPI communication.** Using the STM32 serial console, run `aeris-diag --spi-loopback`. This verifies that the SPI bus to the ADF4159 is functional. If SPI loopback fails, inspect the SPI cable connection and board connector. If SPI is working but PLL does not lock, the ADF4159 may have been programmed with incorrect register values. Re-run `aeris-init --pll` to reload the default register set.

3. **Check VCO supply voltage.** Measure the HMC733LP6CE supply pins: Vd should be +5 V ±0.25 V; Vs (source bias) should be at the designed operating point. If supply is out of range, trace back to the TPS65133 ±5 V_RF rails (PT-002).

4. **Check VCO tuning range.** In CW mode, sweep the ADF4159 N-divider to step the VCO from its minimum to maximum frequency (9.5–11 GHz per HMC733 datasheet). A PLL that locks at some frequencies but not others may indicate the VCO is operating outside its range for the chosen N-divider values. Verify N-divider and reference divider settings against the ADF4159 configuration spreadsheet.

5. **Replace ADF4159 or HMC733.** If all above steps are inconclusive, the IC may have been damaged by ESD or over-voltage. Replace with a spare (see Section 8).

### 6.2 Low TX Output Power

**Symptom:** TX power >2 dB below nominal (+30 dBm).

**Fault tree:**

1. **Check PA bias.** Measure the HMC451LS6GE gate and drain voltages. The PA requires specific gate bias voltage (from datasheet, typically negative gate voltage for pHEMT depletion-mode devices). If bias is incorrect, check the gate bias circuit (often a DAC output from the STM32 or a fixed resistor divider from the −5 V_RF rail).

2. **Check PA supply voltage.** Vd for the HMC451 should be +5 V ±0.25 V. Measure directly at the PA drain pin. If supply sags under load, the TPS65133 +5 V_RF rail has insufficient current capacity — inspect for a shorted bypass capacitor.

3. **Check cable connections.** Inspect the SMA connections from the phase shifters to the PA input, and from the PA output to the TX feed. A partially mated SMA connector can introduce 3–6 dB of attenuation. Tighten all connectors and re-measure.

4. **Check PA temperature.** The HMC451LS6GE has a thermal shutdown or significant gain roll-off if the die temperature exceeds 150°C. Measure PA case temperature. If above 80°C, check thermal paste and chassis cooling. Allow the PA to cool and re-measure output power.

5. **PA failure.** If bias is correct, supply is correct, connections are correct, and temperature is within range, the PA may have failed (degraded output stage). Replace HMC451LS6GE per Section 6.5.

### 6.3 High Noise Floor on IF Output

**Symptom:** The software noise floor in the range-FFT is elevated (worse than expected based on the system NF budget of 8 dB), reducing detection range.

**Fault tree:**

1. **Check LNA bias.** Measure the HMC1040LP4E drain voltage and current. Operating point must be within the specified range (typically 3 V drain, ~60–80 mA). Incorrect bias shifts the noise figure and gain away from the optimum.

2. **Check mixer LO drive level.** The HMC213B requires nominally +7 to +10 dBm LO drive. Measure LO level at the mixer LO port with a directional coupler and SA. Under-driven LO increases conversion loss and noise figure.

3. **Check mixer supply.** The HMC213B requires DC bias on its IF port (+5 V_RF) for proper operation. Verify bias is present and within tolerance.

4. **Check IF amplifier chain.** If the system has IF amplifier stages between the mixer output and the ADC, verify each stage gain and supply. A failed IF amplifier can reduce signal level and cause the ADC to be dominated by quantisation noise.

5. **Check for interference.** Operate the system with the TX disabled. Measure the IF noise floor with TX off. If the noise floor is normal with TX off but elevated with TX on, there is TX-to-RX leakage (insufficient isolation) creating self-jamming. Check the MASWSS0179 T/R switch operation and TX-to-RX isolation (PT-041).

6. **Check ADC reference.** The ADS8661 uses an internal or external voltage reference. An incorrect or noisy reference voltage increases ADC noise floor. Measure the reference voltage at the ADS8661 REF pin (nominal 4.096 V internal or as configured externally).

### 6.4 Beam Steering Not Working

**Symptom:** The radar beam does not steer to the commanded angle; the pattern remains at broadside regardless of phase shifter commands, or the beam is erratic.

**Fault tree:**

1. **Check SPI communication to HMC647A.** From the AERIS software diagnostic menu: `aeris-diag --phase-shifter 1`. This commands phase shifter #1 through all 64 codes and reads back the code via the SPI DOUT line (if the HMC647A SPI read-back is supported). If communication fails, trace the SPI CS, CLK, and MOSI lines from the STM32 to the HMC647A.

2. **Check phase shifter supply voltage.** The HMC647ALP5E requires VDD (digital, typically 3.3 V) and VCC (phase shifter bias, typically from the +5 V or −5 V_RF rail, depending on the application circuit). Measure each supply at the IC power pins.

3. **Verify with VNA.** Connect the VNA to one phase shifter input and output. Command the phase shifter through codes 0x00, 0x10, 0x20, 0x30, 0x3F via the STM32 serial command interface. Verify that S21 phase changes in the expected direction and magnitude on the VNA. If no phase change is seen despite correct SPI signalling, the HMC647A IC has likely failed and must be replaced.

4. **Check phase control word in firmware.** Verify that the beam-steering algorithm is computing the correct phase gradient for the commanded angle. The required inter-element phase shift for angle θ is: Δφ = 360° × (d/λ) × sin(θ) = 360° × 0.5 × sin(θ). For θ = 30°: Δφ = 90° per element. This value, divided by the phase step (5.625° per bit for the 6-bit shifter) gives 16 bits per element — verify this calculation in the firmware source.

---

## 7. Component Replacement Procedures

### 7.1 General ESD Precautions

All component replacement must be performed at an ESD-safe workstation with wrist strap and ESD mat grounded. The HMC647A, HMC1040, and HMC213B are GaAs devices with HBM ESD ratings as low as 500 V. Handle with care; never touch pins directly.

### 7.2 HMC647ALP5E Rework with Hot Air

The HMC647ALP5E is in a 5×5 mm QFN package with an exposed thermal pad. Replacement requires a hot air rework station and proper stencil or syringe paste application.

**Tools required:** Hot air rework station (Hakko FR-872B or Metcal MFR-H1-DS), fine-tip iron 350°C, flux pen (Kester 951), desoldering wick 2.0 mm, tweezers, 0.12 mm stencil (or syringe paste for individual pad application), new HMC647ALP5E in ESD-safe packaging.

**Removal:**
1. Apply flux pen generously to all four sides of the HMC647A package.
2. Set hot air: 360°C, 30 L/min airflow, round nozzle 5 mm diameter.
3. Hover the nozzle 5–8 mm above the package. Move in slow circles. Observe the solder — when reflowed, the package will float very slightly.
4. After approximately 30–60 s, gently lift the package with tweezers from one corner. Do not force; if it does not lift freely, continue heating.
5. Place removed component in an ESD tray (do not discard — may be tested and reused).

**Pad Cleanup:**
1. Apply fresh flux to the PCB pads.
2. Using desoldering wick 2.0 mm and the iron at 350°C, remove all solder from each exposed pad. Work methodically around all four sides, then the thermal pad (apply heat for 3–4 s per section; the thermal pad is large and requires longer dwell).
3. Inspect under 10× magnification: all pads should be clean, flat copper with ENIG finish (gold colour). No solder bridges, no lifted pads.

**Installation:**
1. Apply solder paste to pads using a mini-stencil (cut from the full stencil for this IC footprint) or with a syringe applying paste to each pad manually. The thermal pad receives a segmented paste deposit (window-pane pattern).
2. Place the new HMC647ALP5E. Align pin 1 dot to silkscreen mark.
3. Set hot air: 350°C, 25 L/min. Approach from the side first to preheat the board for 15 s. Then move nozzle over the component for 30–45 s until solder is seen to reflow (slight movement of component as surface tension centres it).
4. Remove heat. Allow to cool with no airflow for 2 minutes.
5. Inspect under 10× microscope. Perform continuity checks.

### 7.3 STM32H743 Replacement

The STM32H743ZIT6 in LQFP-144 at 0.5 mm pitch can be replaced with hot air, but requires significant skill due to the 144 leads. Consider sending the board to a professional rework facility for this operation.

If performing in-house: use a large round nozzle (12–15 mm), 350°C, 20 L/min, hover over the entire package, preheat the board from below with a pre-heater plate at 150°C, then reflow from above. Lead-frame IC packages often require more heat than QFN packages due to the gull-wing leads dissipating heat to the board.

---

## 8. Spare Parts List

Maintain the following minimum spare parts inventory. Suggested stocking quantity reflects the estimated failure rate over a 2-year operational period.

| Part | Description | Quantity | Notes |
|---|---|---|---|
| HMC647ALP5E | 6-bit phase shifter, 10–14 GHz, QFN | 4 | Most likely RF IC to require replacement; 16 installed |
| HMC1040LP4E | LNA 8–12 GHz, NF 1.5 dB | 2 | 4 installed; critical for RX sensitivity |
| HMC213B | Double-balanced mixer 8–26 GHz | 2 | 4 installed |
| HMC451LS6GE | TX PA, +29 dBm, 28 dB gain | 2 | 1 installed; PA most stressed component |
| HMC733LP6CE | VCO 9.5–11 GHz | 1 | 1 installed |
| ADF4159CCPZ | FMCW PLL synthesiser | 1 | 1 installed |
| STM32H743ZIT6 | Microcontroller LQFP-144 | 1 | 1 installed |
| ADS8661IRGAT | 16-bit 1 MSPS ADC | 2 | 1 installed; ESD-sensitive |
| ABRACON AOCJY-10 | 10 MHz OCXO reference | 1 | 1 installed |
| LT8612EFE | 5 V DC-DC converter | 1 | 1 installed |
| LT8607PMSE6 | 3.3 V DC-DC converter | 1 | 1 installed |
| PE8316 | 9.5–10.5 GHz circulator/isolator | 1 | As installed |
| SMA female, PCB mount | Panel SMA connector | 6 | Connectors are field-replaceable; highest wear item |
| SMA m-m barrel | Loopback adaptor | 2 | |
| 30 dB SMA attenuator, 5 W | In-line attenuator for TX measurements | 2 | |
| M3 × 6, cap-head, SS | Stainless M3 fasteners | 20 | Various lengths |
| 10 A blade fuse | AGX or ATO automotive blade | 5 | For 24 V input fuse |
| 80 mm ball-bearing fan, 5 V | Noctua NF-A8 5V or equivalent | 1 | Annual replacement on condition |
| Shin-Etsu X-23-7921-5 thermal paste | 7 g syringe | 1 | Annual replacement |
| Kester 44 solder wire 0.5 mm | Sn63Pb37 | 1 spool | Field touch-up |
| IPA 99.9% | 500 mL spray bottle | 2 | Connector cleaning |

---

## 9. Storage Procedure

### 9.1 Short-Term Storage (Less Than 6 Months)

1. Power off the system and disconnect 24 V input.
2. Install dust caps on all exposed SMA connectors (SMA dust cap, push-on type).
3. Wipe all external surfaces with a dry lint-free cloth to remove moisture and fingerprints.
4. Place 5 g silica gel sachet inside the chassis.
5. Close the chassis and secure all access panels.
6. Store in an indoor environment: temperature +5°C to +40°C, humidity <70% RH non-condensing.
7. Place in a protective carry case with foam cut-outs.

### 9.2 Long-Term Storage (6 Months or Greater)

1. Complete all pre-storage maintenance checks.
2. Remove the antenna panel and wrap in anti-static bubble wrap. Store separately in a flat orientation to prevent the Rogers substrate from warping.
3. Remove the Raspberry Pi 5 microSD card (if used) or USB SSD and store it in an anti-static bag separately from the main chassis.
4. Bag all PCB assemblies individually in metallic anti-static bags (not pink anti-static foam, which does not provide RF shielding).
5. Place desiccant (10 g minimum) inside the sealed chassis.
6. Store at: temperature −20°C to +60°C dry, preferred +15°C to +25°C; humidity <50% RH.
7. Power on and perform the complete pre-operation checklist at least once every 12 months during long-term storage to verify the OCXO maintains calibration and capacitors do not dry out.

### 9.3 Field Transport

Transport the AERIS-10P in the dedicated carry case. Do not leave the system in a vehicle in direct sunlight (interior temperatures can exceed 80°C). Use the original tripod mounting hardware; improvised mounts may not support the 5 kg system weight safely.

---

## 10. End-of-Life and Disposal

### 10.1 RF Integrated Circuit Recycling

The HMC647ALP5E, HMC1040LP4E, HMC213B, and HMC451LS6GE contain gallium arsenide (GaAs) compound semiconductor material. GaAs is classified as a hazardous substance under EU Directive 2011/65/EU (RoHS) and must not be disposed of in general waste. Options for disposal:

- Return to the component distributor (Analog Devices authorised distributors may accept returns under take-back programmes).
- Deliver to a licensed electronic waste recycling facility. In Germany, WEEE (Waste Electrical and Electronic Equipment) regulations (ElektroG, implementing EU Directive 2012/19/EU) require registered take-back. Use a certified WEEE recycling point.

### 10.2 PCB and Electronic Assembly Disposal

All populated PCBs, including the Rogers RO4003C antenna panel, must be disposed of as WEEE (Elektroschrott) in accordance with ElektroG. Do not dispose in household waste. Deliver to a municipal Wertstoffhof (recycling centre) with electronics acceptance, or to a certified WEEE recycler.

The Rogers RO4003C substrate does not contain hazardous halogens (it is a halogen-free material), but the copper layers and solder alloys require separate handling per local regulations.

### 10.3 Battery Disposal

If a lithium coin cell (CR2032 or similar) is used for the STM32 real-time clock battery, it must be disposed of at a battery collection point (Batterie-Rückgabe) per BattG (Batteriegesetz) in Germany. Do not dispose in household waste.

### 10.4 Decommissioning Checklist

Before final disposal:
1. Delete all personal data (callsign, GPS coordinates, station logs) from the Raspberry Pi 5 storage: `sudo shred -vuz /dev/mmcblk0` or perform a secure erase.
2. Remove the microSD card / SSD and destroy physically if it contains sensitive data.
3. Document system serial number and disposal date in the maintenance log.
4. If the system holds a BNetzA experimental radar permit, notify BNetzA that the station is being decommissioned and the permit is being relinquished.

---

*End of AERIS-10P Maintenance Documentation Rev 1.0*

*Document controlled. Check repository for latest revision before use.*

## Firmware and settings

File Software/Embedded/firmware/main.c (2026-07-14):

/**
 * @file main.c
 * @brief AERIS-10P Radar Main Firmware — STM32H743ZIT6
 *
 * System:  480 MHz Cortex-M7, FPU, ICACHE/DCACHE enabled
 * Purpose: FMCW chirp generation, phased array control, ADC acquisition, USB data streaming
 *
 * Build with: make all  (see Makefile)
 * Flash with: make flash (requires ST-Link V3 or STLINK-V2)
 *
 * USB CDC-ACM protocol:
 *   Packet: [0xAA][0x55][uint16 len][uint8 cmd][payload][uint8 checksum]
 *   Commands:
 *     0x01 PING -> 0x02 PONG (connectivity test)
 *     0x10 SET_BEAM [float az][float el] -> sets beam steering
 *     0x11 SET_CHIRP [uint64 f_start][uint64 f_stop][uint32 t_us]
 *     0x20 START_CAPTURE [uint32 n_samples] -> streams ADC data
 *     0x21 DATA_PACKET [uint32 seq][uint16[] samples] (sent by firmware)
 *     0x30 GET_STATUS -> 0x31 STATUS [uint8 flags][float az][float el][float tx_pwr_dbm]
 *     0x40 SET_PA_ENABLE [uint8 en] -> enable/disable PA
 *     0x50 REBOOT -> software reset
 */

#include "stm32h7xx_hal.h"
#include "usb_device.h"
#include "usbd_cdc_if.h"
#include "phase_shifter.h"
#include "adf4159.h"
#include <string.h>
#include <stdio.h>
#include <math.h>

/* ─────────────────────────────────────────────────────────────────── */
/* Defines & Constants                                                   */
/* ─────────────────────────────────────────────────────────────────── */

#define FIRMWARE_VERSION        "1.0.0"
#define ADC_BUFFER_SIZE         8192        /* samples per capture (1 s at 8 kSPS) */
#define USB_PACKET_HEADER_LEN  5
#define USB_TX_BUF_SIZE        512
#define TEMP_SHUTDOWN_CELSIUS  70.0f
#define PA_ENABLE_GPIO_PORT    GPIOC
#define PA_ENABLE_GPIO_PIN     GPIO_PIN_0
#define LNA_ENABLE_GPIO_PORT   GPIOC
#define LNA_ENABLE_GPIO_PIN    GPIO_PIN_1
#define LED_OK_GPIO_PORT       GPIOC
#define LED_OK_GPIO_PIN        GPIO_PIN_3
#define LED_TX_GPIO_PORT       GPIOC
#define LED_TX_GPIO_PIN        GPIO_PIN_4

/* USB protocol commands */
#define CMD_PING               0x01
#define CMD_PONG               0x02
#define CMD_SET_BEAM           0x10
#define CMD_SET_CHIRP          0x11
#define CMD_START_CAPTURE      0x20
#define CMD_DATA_PACKET        0x21
#define CMD_GET_STATUS         0x30
#define CMD_STATUS             0x31
#define CMD_SET_PA_ENABLE      0x40
#define CMD_REBOOT             0x50

/* ─────────────────────────────────────────────────────────────────── */
/* Global Handles and State                                              */
/* ─────────────────────────────────────────────────────────────────── */

extern SPI_HandleTypeDef hspi1;   /* TX phase shifter bus */
extern SPI_HandleTypeDef hspi2;   /* RX phase shifter bus */
extern SPI_HandleTypeDef hspi3;   /* ADF4159 PLL */
extern SPI_HandleTypeDef hspi4;   /* ADS8661 ADC */
extern ADC_HandleTypeDef hadc1;   /* Internal ADC for temperature monitor */

static PS_System_t   ps_sys;
static ADF4159_Config_t pll_cfg;

static uint16_t adc_buffer[ADC_BUFFER_SIZE];
static volatile uint32_t adc_sample_count = 0;
static volatile bool capture_active = false;
static volatile bool pa_enabled = false;
static float current_az_deg = 0.0f;
static float current_el_deg = 0.0f;
static float pa_heatsink_temp_c = 25.0f;

/* USB transmit buffer */
static uint8_t usb_tx_buf[USB_TX_BUF_SIZE];

/* ─────────────────────────────────────────────────────────────────── */
/* Private Function Prototypes                                           */
/* ─────────────────────────────────────────────────────────────────── */

static void System_Init(void);
static void Process_USB_Command(uint8_t *data, uint16_t len);
static void Send_USB_Packet(uint8_t cmd, const uint8_t *payload, uint16_t payload_len);
static uint8_t Compute_Checksum(const uint8_t *data, uint16_t len);
static void Read_Heatsink_Temperature(void);
static void Handle_Overtemperature(void);
static uint16_t ADC_ReadSingleSample(void);
static void Start_ADC_Capture(uint32_t n_samples);
static void LED_OK_Toggle(void);

/* ─────────────────────────────────────────────────────────────────── */
/* Main Entry Point                                                      */
/* ─────────────────────────────────────────────────────────────────── */

int main(void) {
    HAL_Init();
    SystemClock_Config();  /* Configure 480 MHz PLL from 25 MHz HSE */

    /* Enable DWT cycle counter for microsecond timing */
    CoreDebug->DEMCR |= CoreDebug_DEMCR_TRCENA_Msk;
    DWT->CYCCNT = 0;
    DWT->CTRL  |= DWT_CTRL_CYCCNTENA_Msk;

    /* Enable I/D cache for performance */
    SCB_EnableICache();
    SCB_EnableDCache();

    /* Initialize HAL peripherals */
    MX_GPIO_Init();
    MX_DMA_Init();
    MX_SPI1_Init();   /* TX phase shifters: CPOL=0 CPHA=0, 10 MHz */
    MX_SPI2_Init();   /* RX phase shifters: same */
    MX_SPI3_Init();   /* ADF4159: 1 MHz */
    MX_SPI4_Init();   /* ADS8661 ADC: 1 MHz */
    MX_ADC1_Init();   /* Internal temperature / NTC */
    MX_USB_DEVICE_Init();
    MX_USART1_UART_Init();  /* Debug UART 115200 */

    /* System initialization: PLL, phase shifters, default beam */
    System_Init();

    printf("AERIS-10P Firmware v%s ready.\r\n", FIRMWARE_VERSION);
    printf("STM32H743 @ 480 MHz, USB CDC ready.\r\n");

    uint32_t tick_1hz = HAL_GetTick();
    uint32_t tick_led = HAL_GetTick();
    uint32_t tick_temp = HAL_GetTick();

    while (1) {
        uint32_t now = HAL_GetTick();

        /* 1 Hz tasks */
        if (now - tick_1hz >= 1000) {
            tick_1hz = now;
            Read_Heatsink_Temperature();
            if (pa_heatsink_temp_c > TEMP_SHUTDOWN_CELSIUS) {
                Handle_Overtemperature();
            }
        }

        /* LED heartbeat at 0.5 Hz (blink every 1000 ms) */
        if (now - tick_led >= 1000) {
            tick_led = now;
            LED_OK_Toggle();
        }

        /* ADC capture: if active, collect samples and send via USB */
        if (capture_active && adc_sample_count < ADC_BUFFER_SIZE) {
            adc_buffer[adc_sample_count++] = ADC_ReadSingleSample();
            if (adc_sample_count >= ADC_BUFFER_SIZE) {
                /* Send complete buffer as DATA_PACKET */
                uint8_t hdr[4];
                hdr[0] = (adc_sample_count >> 24) & 0xFF;
                hdr[1] = (adc_sample_count >> 16) & 0xFF;
                hdr[2] = (adc_sample_count >>  8) & 0xFF;
                hdr[3] = (adc_sample_count      ) & 0xFF;
                /* Send in chunks (USB FS max packet = 64 bytes) */
                /* TODO: implement chunked USB transfer */
                capture_active = false;
                HAL_GPIO_WritePin(LED_TX_GPIO_PORT, LED_TX_GPIO_PIN, GPIO_PIN_RESET);
            }
        }

        /* USB receive handled by callback CDC_Receive_FS in usbd_cdc_if.c */
        /* which calls Process_USB_Command */
    }
}

/* ─────────────────────────────────────────────────────────────────── */
/* System Initialization                                                 */
/* ─────────────────────────────────────────────────────────────────── */

static void System_Init(void) {
    /* 1. Initialize ADF4159 FMCW PLL */
    ADF4159_Error_t pll_err = ADF4159_Init(&pll_cfg, &hspi3);
    if (pll_err == ADF4159_OK) {
        printf("ADF4159 initialized. Chirp: %.3f-%.3f GHz in %lu us\r\n",
               (double)pll_cfg.freq_start_hz / 1e9,
               (double)pll_cfg.freq_stop_hz  / 1e9,
               (unsigned long)pll_cfg.chirp_time_us);
    } else {
        printf("ADF4159 init FAILED (err=%d)\r\n", pll_err);
    }

    /* 2. Initialize phase shifter arrays */
    PS_Error_t ps_err = PS_Init(&ps_sys, &hspi1, &hspi2);
    if (ps_err == PS_OK) {
        printf("Phase shifters initialized. Broadside beam set.\r\n");
    } else {
        printf("Phase shifter init FAILED (err=%d)\r\n", ps_err);
    }

    /* 3. Enable LNA bias (but NOT PA yet — PA requires explicit enable command) */
    HAL_GPIO_WritePin(LNA_ENABLE_GPIO_PORT, LNA_ENABLE_GPIO_PIN, GPIO_PIN_SET);
    printf("LNA enabled.\r\n");

    /* 4. PA disabled by default (safety) */
    HAL_GPIO_WritePin(PA_ENABLE_GPIO_PORT, PA_ENABLE_GPIO_PIN, GPIO_PIN_RESET);
    pa_enabled = false;
    printf("PA disabled (use CMD_SET_PA_ENABLE to enable).\r\n");

    /* 5. Enable FMCW ramp */
    ADF4159_EnableRamp(&hspi3);
    printf("FMCW ramp enabled.\r\n");

    /* 6. OK LED on */
    HAL_GPIO_WritePin(LED_OK_GPIO_PORT, LED_OK_GPIO_PIN, GPIO_PIN_SET);
}

/* ─────────────────────────────────────────────────────────────────── */
/* USB Command Processing                                                */
/* Called from USB CDC receive callback                                  */
/* ─────────────────────────────────────────────────────────────────── */

static void Process_USB_Command(uint8_t *data, uint16_t len) {
    if (len < USB_PACKET_HEADER_LEN) return;

    /* Verify header magic */
    if (data[0] != 0xAA || data[1] != 0x55) return;

    uint16_t payload_len = ((uint16_t)data[2] << 8) | data[3];
    uint8_t  cmd = data[4];

    if (len < (uint16_t)(5 + payload_len + 1)) return;  /* too short */

    uint8_t  *payload   = &data[5];
    uint8_t  rx_cksum   = data[5 + payload_len];
    uint8_t  calc_cksum = Compute_Checksum(data, 5 + payload_len);
    if (rx_cksum != calc_cksum) return;  /* checksum mismatch */

    switch (cmd) {
        case CMD_PING:
            Send_USB_Packet(CMD_PONG, NULL, 0);
            break;

        case CMD_SET_BEAM: {
            /* payload: [float32 az_deg][float32 el_deg] (8 bytes) */
            if (payload_len < 8) break;
            float az, el;
            memcpy(&az, &payload[0], 4);
            memcpy(&el, &payload[4], 4);
            PS_SetSteering(&ps_sys, az, el);
            current_az_deg = az;
            current_el_deg = el;
            printf("Beam -> az=%.1f el=%.1f\r\n", (double)az, (double)el);
            break;
        }

        case CMD_SET_CHIRP: {
            /* payload: [uint64 f_start][uint64 f_stop][uint32 t_us] (20 bytes) */
            if (payload_len < 20) break;
            uint64_t f_start, f_stop;
            uint32_t t_us;
            memcpy(&f_start, &payload[0],  8);
            memcpy(&f_stop,  &payload[8],  8);
            memcpy(&t_us,    &payload[16], 4);
            ADF4159_SetChirp(&pll_cfg, f_start, f_stop, t_us, &hspi3);
            ADF4159_EnableRamp(&hspi3);
            printf("Chirp: %.3f-%.3f GHz, %lu us\r\n",
                   (double)f_start/1e9, (double)f_stop/1e9, (unsigned long)t_us);
            break;
        }

        case CMD_START_CAPTURE: {
            /* payload: [uint32 n_samples] (4 bytes) */
            if (payload_len < 4) break;
            uint32_t n;
            memcpy(&n, &payload[0], 4);
            Start_ADC_Capture(n);
            break;
        }

        case CMD_GET_STATUS: {
            uint8_t status_payload[13];
            uint8_t flags = pa_enabled ? 0x01 : 0x00;
            if (ADF4159_IsLocked()) flags |= 0x02;
            status_payload[0] = flags;
            memcpy(&status_payload[1], &current_az_deg, 4);
            memcpy(&status_payload[5], &current_el_deg, 4);
            memcpy(&status_payload[9], &pa_heatsink_temp_c, 4);
            Send_USB_Packet(CMD_STATUS, status_payload, 13);
            break;
        }

        case CMD_SET_PA_ENABLE: {
            if (payload_len < 1) break;
            pa_enabled = (payload[0] != 0);
            HAL_GPIO_WritePin(PA_ENABLE_GPIO_PORT, PA_ENABLE_GPIO_PIN,
                              pa_enabled ? GPIO_PIN_SET : GPIO_PIN_RESET);
            HAL_GPIO_WritePin(LED_TX_GPIO_PORT, LED_TX_GPIO_PIN,
                              pa_enabled ? GPIO_PIN_SET : GPIO_PIN_RESET);
            printf("PA %s\r\n", pa_enabled ? "ENABLED" : "disabled");
            break;
        }

        case CMD_REBOOT:
            HAL_Delay(100);
            NVIC_SystemReset();
            break;

        default:
            printf("Unknown CMD 0x%02X\r\n", cmd);
            break;
    }
}

/* ─────────────────────────────────────────────────────────────────── */
/* USB Packet Transmission                                               */
/* ─────────────────────────────────────────────────────────────────── */

static void Send_USB_Packet(uint8_t cmd, const uint8_t *payload, uint16_t payload_len) {
    if (2 + payload_len + 1 > USB_TX_BUF_SIZE) return;

    usb_tx_buf[0] = 0xAA;
    usb_tx_buf[1] = 0x55;
    usb_tx_buf[2] = (payload_len >> 8) & 0xFF;
    usb_tx_buf[3] = (payload_len     ) & 0xFF;
    usb_tx_buf[4] = cmd;
    if (payload && payload_len > 0) {
        memcpy(&usb_tx_buf[5], payload, payload_len);
    }
    uint8_t cksum = Compute_Checksum(usb_tx_buf, 5 + payload_len);
    usb_tx_buf[5 + payload_len] = cksum;

    CDC_Transmit_FS(usb_tx_buf, 5 + payload_len + 1);
}

/* ─────────────────────────────────────────────────────────────────── */
/* Checksum: XOR of all bytes                                            */
/* ─────────────────────────────────────────────────────────────────── */

static uint8_t Compute_Checksum(const uint8_t *data, uint16_t len) {
    uint8_t cksum = 0;
    for (uint16_t i = 0; i < len; i++) cksum ^= data[i];
    return cksum;
}

/* ─────────────────────────────────────────────────────────────────── */
/* Temperature Monitoring (NTC on PA heatsink via STM32 ADC)            */
/* ─────────────────────────────────────────────────────────────────── */

static void Read_Heatsink_Temperature(void) {
    /* TODO: read NTC thermistor via ADC1 channel */
    /* NTC: 10kOhm at 25°C, B=3950K */
    /* Simple approximation: ADC_raw -> voltage -> resistance -> temperature */
    /* For now: placeholder */
    pa_heatsink_temp_c = 30.0f;  /* Replace with actual NTC calculation */
}

static void Handle_Overtemperature(void) {
    /* Emergency shutdown: disable PA */
    HAL_GPIO_WritePin(PA_ENABLE_GPIO_PORT, PA_ENABLE_GPIO_PIN, GPIO_PIN_RESET);
    pa_enabled = false;
    HAL_GPIO_WritePin(LED_TX_GPIO_PORT, LED_TX_GPIO_PIN, GPIO_PIN_RESET);
    printf("OVERTEMP: PA disabled! Temp=%.1f C\r\n", (double)pa_heatsink_temp_c);
}

/* ─────────────────────────────────────────────────────────────────── */
/* ADC Capture via ADS8661 (SPI4)                                       */
/* ─────────────────────────────────────────────────────────────────── */

static uint16_t ADC_ReadSingleSample(void) {
    /* ADS8661 SPI read: 24-bit transaction
     * Send: [0x00 0x00 0x00] with CS asserted
     * Receive: [status|MSB][LSB][don't care]
     * Data = received_word >> 4 (12-bit in 16-bit MSB justified)
     * Wait: /BUSY goes low after conversion, then read
     */
    uint8_t tx_buf[3] = {0x00, 0x00, 0x00};
    uint8_t rx_buf[3] = {0x00};

    HAL_GPIO_WritePin(GPIOE, GPIO_PIN_11, GPIO_PIN_RESET);  /* CS low */
    HAL_SPI_TransmitReceive(&hspi4, tx_buf, rx_buf, 3, 10);
    HAL_GPIO_WritePin(GPIOE, GPIO_PIN_11, GPIO_PIN_SET);    /* CS high */

    /* Extract 16-bit sample from received bytes */
    uint16_t sample = ((uint16_t)rx_buf[0] << 8) | rx_buf[1];
    return sample;
}

static void Start_ADC_Capture(uint32_t n_samples) {
    if (n_samples > ADC_BUFFER_SIZE) n_samples = ADC_BUFFER_SIZE;
    adc_sample_count = 0;
    capture_active   = true;
    HAL_GPIO_WritePin(LED_TX_GPIO_PORT, LED_TX_GPIO_PIN, GPIO_PIN_SET);
    printf("Capture started: %lu samples\r\n", (unsigned long)n_samples);
}

static void LED_OK_Toggle(void) {
    HAL_GPIO_TogglePin(LED_OK_GPIO_PORT, LED_OK_GPIO_PIN);
}

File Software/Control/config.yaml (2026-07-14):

# AERIS-10P Radar Control Configuration
# Edit this file to match your hardware setup
# -------------------------------------------

radar:
  serial_port: /dev/ttyACM0    # Linux/Mac: /dev/ttyACM0  |  Windows: COM3
  baud_rate: 115200
  connect_timeout_s: 5.0
  reconnect_on_error: true

rf:
  freq_start_hz: 10000000000   # 10.000 GHz chirp start
  freq_stop_hz:  10100000000   # 10.100 GHz chirp stop
  sweep_time_us: 1000          # 1 ms per chirp
  pa_enabled: false            # PA off at startup (safety)

beam:
  default_az_deg: 0.0          # broadside
  default_el_deg: 0.0
  min_az_deg: -45.0
  max_az_deg:  45.0
  min_el_deg: -30.0
  max_el_deg:  30.0
  az_step_deg:  5.0            # scan step size

array:
  n_elements: 16
  element_spacing_mm: 15.0
  wavelength_mm: 29.85
  rows: 4
  cols: 4
  calibration_file: calibration_tx.npy  # null = no calibration

processing:
  adc_sample_rate_hz: 8000
  n_chirps_per_cpi: 100        # coherent processing interval
  fft_size: 8192
  max_range_m: 4000
  range_resolution_m: 1.5
  cfar_threshold_db: 15.0
  cfar_guard_cells: 4
  cfar_training_cells: 16
  clutter_filter: dc_removal   # dc_removal | mti | none

display:
  update_rate_hz: 2.0
  range_max_display_m: 3000
  velocity_max_display_mps: 50.0
  colormap: plasma
  show_ppi: true
  show_rdm: true
  show_range_profile: true

logging:
  level: INFO                  # DEBUG | INFO | WARNING | ERROR
  log_file: aeris_session.log
  save_raw_data: true          # save HDF5 data files
  data_dir: ./data
  max_file_size_mb: 500

safety:
  max_pa_temp_c: 70.0          # PA temperature shutdown threshold
  min_pll_lock_required: true  # abort if PLL not locked

regulatory:
  # German Klasse A amateur radio compliance
  callsign: "DL0EXAMPLE"       # Replace with your actual callsign
  id_interval_s: 600           # Station identification every 10 minutes (mandatory)
  id_method: software_cw       # software_cw | manual
  max_tx_power_w: 1.0          # Software-enforced TX power limit

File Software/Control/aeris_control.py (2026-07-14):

"""
AERIS-10P Radar Control Application
=====================================
PC-side control software for the AERIS-10P phased array radar.
Communicates with STM32H743 firmware via USB CDC-ACM (virtual serial port).

Usage:
    python aeris_control.py --help
    python aeris_control.py connect --port /dev/ttyACM0
    python aeris_control.py beam --az 30 --el 0
    python aeris_control.py pa-enable 1
    python aeris_control.py capture --n-chirps 100
    python aeris_control.py scan --az-min -45 --az-max 45 --step 5

Requirements:
    pip install pyserial PyYAML loguru
"""

import struct
import time
import threading
import queue
import argparse
import logging
import sys
from pathlib import Path
from typing import Optional

try:
    import serial
    import serial.tools.list_ports
    HAS_SERIAL = True
except ImportError:
    HAS_SERIAL = False
    print("Warning: pyserial not installed. Run: pip install pyserial")

try:
    import yaml
    HAS_YAML = True
except ImportError:
    HAS_YAML = False

try:
    import numpy as np
    HAS_NUMPY = True
except ImportError:
    HAS_NUMPY = False

# ── Protocol constants ───────────────────────────────────────────────────────

SYNC1, SYNC2 = 0xAA, 0x55
CMD_PING          = 0x01
CMD_PONG          = 0x02
CMD_SET_BEAM      = 0x10
CMD_SET_CHIRP     = 0x11
CMD_START_CAPTURE = 0x20
CMD_DATA_PACKET   = 0x21
CMD_GET_STATUS    = 0x30
CMD_STATUS        = 0x31
CMD_SET_PA_ENABLE = 0x40
CMD_REBOOT        = 0x50

# ── Logging setup ────────────────────────────────────────────────────────────

logging.basicConfig(
    level=logging.INFO,
    format='%(asctime)s [%(levelname)s] %(message)s',
    handlers=[logging.StreamHandler(sys.stdout)]
)
log = logging.getLogger('aeris')

# ── Config loader ────────────────────────────────────────────────────────────

def load_config(path: str = 'config.yaml') -> dict:
    """Load YAML configuration file."""
    defaults = {
        'radar': {'serial_port': '/dev/ttyACM0', 'baud_rate': 115200},
        'rf': {'freq_start_hz': 10_000_000_000, 'freq_stop_hz': 10_100_000_000, 'sweep_time_us': 1000},
        'beam': {'default_az_deg': 0.0, 'default_el_deg': 0.0},
        'processing': {'adc_sample_rate_hz': 8000, 'n_chirps_per_cpi': 100},
        'regulatory': {'callsign': 'NOCALL', 'id_interval_s': 600},
    }
    if not HAS_YAML or not Path(path).exists():
        return defaults
    with open(path) as f:
        loaded = yaml.safe_load(f)
    # Merge with defaults
    for section, values in defaults.items():
        if section not in loaded:
            loaded[section] = values
        else:
            for k, v in values.items():
                if k not in loaded[section]:
                    loaded[section][k] = v
    return loaded

# ── Packet codec ─────────────────────────────────────────────────────────────

def checksum(data: bytes) -> int:
    result = 0
    for b in data:
        result ^= b
    return result

def build_packet(cmd: int, payload: bytes = b'') -> bytes:
    length = len(payload)
    header = bytes([SYNC1, SYNC2, (length >> 8) & 0xFF, length & 0xFF, cmd])
    body = header + payload
    return body + bytes([checksum(body)])

def parse_packet(data: bytes) -> Optional[tuple]:
    """Parse a received packet. Returns (cmd, payload) or None if invalid."""
    if len(data) < 6:
        return None
    if data[0] != SYNC1 or data[1] != SYNC2:
        return None
    length = (data[2] << 8) | data[3]
    cmd = data[4]
    if len(data) < 5 + length + 1:
        return None
    payload = data[5:5 + length]
    rx_cksum = data[5 + length]
    calc_cksum = checksum(data[:5 + length])
    if rx_cksum != calc_cksum:
        log.warning(f"Checksum mismatch: got {rx_cksum:#04x}, expected {calc_cksum:#04x}")
        return None
    return cmd, payload

# ── AERISController class ─────────────────────────────────────────────────────

class AERISController:
    """Controls AERIS-10P radar via USB CDC-ACM protocol."""

    def __init__(self, port: str, baud: int = 115200, config: dict = None):
        self.port   = port
        self.baud   = baud
        self.config = config or {}
        self._serial: Optional['serial.Serial'] = None
        self._rx_queue = queue.Queue()
        self._rx_thread: Optional[threading.Thread] = None
        self._running = False
        self._data_buffer = bytearray()
        self._last_id_time = 0.0
        self._callsign = self.config.get('regulatory', {}).get('callsign', 'NOCALL')
        self._id_interval = self.config.get('regulatory', {}).get('id_interval_s', 600)

    def connect(self, timeout: float = 5.0) -> bool:
        """Open serial port and verify connectivity with PING."""
        if not HAS_SERIAL:
            log.error("pyserial not installed")
            return False
        try:
            self._serial = serial.Serial(self.port, self.baud, timeout=0.1)
            self._running = True
            self._rx_thread = threading.Thread(target=self._receive_loop, daemon=True)
            self._rx_thread.start()
            log.info(f"Connected to {self.port} @ {self.baud} baud")
        except Exception as e:
            log.error(f"Failed to open {self.port}: {e}")
            return False

        # Send PING
        self._send(build_packet(CMD_PING))
        deadline = time.monotonic() + timeout
        while time.monotonic() < deadline:
            try:
                cmd, payload = self._rx_queue.get(timeout=0.5)
                if cmd == CMD_PONG:
                    log.info("AERIS-10P connected — PONG received")
                    return True
            except queue.Empty:
                continue
        log.error(f"No PONG response within {timeout}s")
        return False

    def disconnect(self):
        self._running = False
        if self._serial and self._serial.is_open:
            self._serial.close()
        log.info("Disconnected")

    def _send(self, packet: bytes):
        if self._serial and self._serial.is_open:
            self._serial.write(packet)
            self._serial.flush()

    def _receive_loop(self):
        """Background thread: read bytes and parse packets."""
        while self._running:
            if not self._serial or not self._serial.is_open:
                break
            try:
                data = self._serial.read(256)
                if data:
                    self._data_buffer.extend(data)
                    self._process_buffer()
            except Exception:
                break
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
